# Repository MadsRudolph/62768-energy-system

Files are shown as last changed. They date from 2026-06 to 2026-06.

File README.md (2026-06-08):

# 62768 — Electrical Energy System

Team project for **62768 Electrical Energy Systems** (DTU, June 2026, 3-week course).
We design and build a complete electrical energy system per the course requirement spec
(*Kravspecifikation*), from idea to a working functional model (CDIO).

> 📋 **Start here:** [`docs/project-overview.md`](docs/project-overview.md) — what to build,
> targets, subsystem plan, deadlines, and division of labour (synthesised from the course material).
> 🗂️ **Kickoff:** [`docs/project-plan.md`](docs/project-plan.md) — the 9-section project plan
> (Lecture 1 structure) to fill in on day 1: tasks/owners, budget, Gantt.

## Team

| Name | GitHub | Role / area |
|---|---|---|
| Mads Rudolph | @MadsRudolph | |
| Jonas Beck Jensen | @MotherFrogher | |
| Andreas Skånning | @AndreasSJacobsen | |
| Bjørn Bjarnason | @Ask-ham | |
| Nikolas Jacobsen | @nikolas-jacobsen | |
| Nikolas Primdahl Lund | @s235080 | |

## System overview

```mermaid
flowchart LR
    SOL[Solar panel] --> MPPT["MPPT cap (15 mF)"]
    MPPT --> LIN["Linear reg (5V)"]
    LIN --> STORE(("Energy store<br/>1F · V3=5V"))

    MOT[DC-Motor] --> GEN["AC-generator<br/>(3-phase)"]
    GEN --> TR["3× transformer"]
    TR --> REC["Rectifier + cap (15 mF)"]
    REC --> BUCK["Buck (Vout=4.8V)"]
    BUCK -->|V1=15V| STORE

    STORE --> BOOST[Boost]
    BOOST -->|V2=10V| LOAD["Pulsing load 10V"]

    PID["PID (Arduino)"] --> PWM[PWM driver]
    PWM --> MOT
    STORE -.monitor.-> DAQ["PC monitoring"]
```

**Key targets:** V1 = 15 V ±1 V (≥300 mA to buck) · V2 = 10 V ±1 V (≥150 mA) · V3 = 5 V ±0.5 V.
Converters and current sensing must use **discrete components** (op-amps allowed; no integrated converter ICs).
Full requirement list lives in the course spec (see `docs/`).

## Repository layout

| Folder | Contents |
|---|---|
| `firmware/` | Arduino code — PID control, ADC, timer/PWM, monitoring |
| `simulation/` | Simulink models (`.slx`) + parameter scripts (`.m`) |
| `hardware/schematics/` | Circuit schematics |
| `hardware/bom/` | Bill of materials |
| `report/` | LaTeX project report — compile `report/main.tex` (`latexmk -pdf main.tex`) |
| `docs/` | Spec, lab guides, design notes; `docs/datasheets/` for component PDFs |
| `measurements/` | Lab/test data (csv, xlsx) |

## Getting started

- **Firmware:** Arduino IDE (or PlatformIO). Boards used: Arduino + (optionally) TI LAUNCHXL-F28027.
- **Simulation:** MATLAB/Simulink — open `.slx` models in `simulation/`, run the `Parameters*.m` scripts first to load workspace variables.
- **Report:** LaTeX in `report/`. Compile with `latexmk -pdf main.tex` (or `pdflatex main` twice). Each `sections/*.tex` can also be compiled standalone. Fill in the frontpage group members and the kravsporing table.

## Workflow (6-person team)

- **Branch per feature/task:** `git checkout -b firmware/pid-loop` (or `sim/...`, `hw/...`, `docs/...`).
- **Pull request into `main`** — keep `main` always working. Ask one teammate to review before merge.
- **Commit small and often**, with clear messages. Pull before you push.
- **Avoid committing binaries that change every save** — `.gitignore` already excludes MATLAB/Arduino build artifacts.
- Heavy binary files (videos, big captures): link from a shared drive instead of committing.

## Course

- DTU 62768, June 2026 · groups of up to 6 · assessment = report + functional model.
- Lab: V1.01-04 · Lecturers: Ashraf, Sam, Audrey.

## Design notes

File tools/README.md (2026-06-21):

# tools/

## srm-cam — Roland SRM-20 CAM tool (git submodule)

`tools/srm-cam/` is a **git submodule** pointing at
[`MadsRudolph/gerber2rml`](https://github.com/MadsRudolph/gerber2rml) (private):
a standalone tool that converts our KiCad Gerber/Excellon exports into Roland
SRM-20 **RML** jobs (trace isolation, drilling, board cutout) — the CNC-mill
alternative to the fiber laser.

### First checkout / after pulling this in

```bash
git submodule update --init tools/srm-cam
```

(or clone the team repo with `git clone --recurse-submodules …`). You need read
access to the private `gerber2rml` repo.

### Use it

```bash
cd tools/srm-cam
python -m venv .venv && .venv\Scripts\activate     # Windows
pip install -e ".[dev,gui]"
python -m gerber2rml.cli <gerber-folder> -o out -n <board>   # CLI → 3 .rml + runplan
python -m gerber2rml                                          # GUI (preview + export)
```

Gerbers come from the usual KiCad production export (see
`hardware/kicad/WORKFLOW.md`). Full docs live in the submodule: `tools/srm-cam/README.md`,
`tools/srm-cam/docs/design.md`.

### ⚠️ Not yet hardware-verified

Run `tools/srm-cam/docs/parity-mosfet_test.md` (compare against the mods website on a
real board) before cutting copper. The fiber-laser flow remains the default until then.

### Updating the pin

The submodule is pinned to a specific `gerber2rml` commit. To move the team repo to a
newer version: `cd tools/srm-cam && git pull origin main && cd ../.. && git add tools/srm-cam && git commit`.

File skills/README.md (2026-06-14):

# Team skills

Claude Code/Claude.ai skills for this project. A "skill" is a playbook Claude loads
automatically when it's relevant — install once and Claude knows our workflow.

## kicad-laser-pcb

The full KiCad → xTool fiber-laser PCB pipeline: schematic design-bug review
(gate drive, grounding, output caps, opto isolation), through-hole footprint
assignment, the 104×104 mm jig format, two-stage Freerouting, and DXF/Gerber export.
Encodes every gotcha we hit (Freerouting 1.9-not-2.0.1, the PowerShell BOM bug,
the `pcbnew` zone-removal crash, the pin-letter trap, …).

**Self-contained.** It bundles its own scripts (`scripts/`) and the laser footprint
library (`lib/`), so it works on *anyone's* KiCad 9 project — you do **not** need
access to our team repo to use it. Share the single `.skill` file with the whole class
and it just works (after the one-time toolchain install below).

### Install (each person, once)

**Option A — the packaged file (easiest to share).** Hand someone
`kicad-laser-pcb.skill` and they install it via the skills UI in Claude Code / the
Claude desktop app. Nothing else needed.

**Option B — copy the source folder** into your personal skills directory:

```powershell
# Windows
Copy-Item -Recurse "skills\kicad-laser-pcb" "$env:USERPROFILE\.claude\skills\"
```
```bash
# macOS / Linux
cp -r skills/kicad-laser-pcb ~/.claude/skills/
```

Restart Claude Code (or reload skills) and it'll show up. Ask something like
"route this buck board" or "review this boost schematic" and it triggers — pointed at
*your own* KiCad project.

### First-time toolchain setup

The skill drives the scripts in `hardware/kicad/tools/`, which need KiCad 9, Java 21,
Python 3.13 + sexpdata, and the Freerouting **1.9.0** jar. The one-time install steps
are in the skill's `references/setup.md` (Claude will walk you through them, or read it
directly). The pipeline is Windows + PowerShell; schematic review and footprint work
are fine on any OS, but routing/export need Windows + KiCad 9.

### Updating the skill

Edit the source under `skills/kicad-laser-pcb/`, then anyone can re-copy it. (The
`.skill` package is a convenience snapshot — regenerate it with the skill-creator's
`package_skill.py` if you change the source and want to redistribute the one-file
version.)

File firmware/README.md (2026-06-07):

# Firmware — 62768 Electrical Energy System

**Bare-metal AVR C** firmware (PlatformIO, no Arduino framework). Builds for
**Arduino Uno** (ATmega328P) and **Mega 2560**. The source files are empty
skeletons — to be written by the team.

## Build & upload

```bash
pio run -e uno            # build for Uno
pio run -e mega           # build for Mega 2560
pio run -e uno -t upload  # upload
pio device monitor        # serial monitor @ 115200
```

(Install PlatformIO: VS Code extension, or `pip install platformio`.)

## Files (skeletons — fill in)
| File | Intended role |
|---|---|
| `include/config.h` | Pins, calibration, setpoints, control parameters |
| `pid.h` / `src/pid.c` | PID controller (kept as plain C — can later be swapped for Simulink/Embedded Coder output) |
| `sensors.h` / `src/sensors.c` | ADC reading + scaling to volts/amps |
| `src/main.c` | Init, control loop, PWM, serial monitoring, ISRs |

## What it needs to do (from the spec)
- PID-regulate the motor/generator to hold bus **V1 = 15 V** (Krav 1)
- Use the Arduino's **ADC + timer interrupts + PWM** (Krav 15)
- **PC voltage monitoring**, updated every 1.0 s (Krav 13/14)

> Note: the skeletons are empty, so the project won't link until `main()` and the
> drivers are written.

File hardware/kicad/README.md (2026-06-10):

# KiCad — 62768 Electrical Energy System (KiCad 9)

Alle 7 system-boards, produktionsfiler til XTool-fiberlaseren og hele
genererings-pipelinen. **Status og produktionsplan: se `../../PCB_RESULTS.md`
og `production/README.md`.**

## Mappestruktur

| Mappe | Indhold |
|---|---|
| **`boards/<navn>/`** | Ét KiCad-projekt pr. board — **åbn `.kicad_pro`-filen** (skema + PCB linket). `pcb/`-undermappen har DRC-rapport + top/bund-renders. `README-exp3a.md` / `README-system.md` er design-noterne. |
| **`production/<navn>/`** | **Laserfiler**: `<navn>.dxf` (importeres i xTool), `_silk_top.dxf` (valgfri topside-tekst), `gerbers/` (komplet fab-sæt). Køreplan i `production/README.md`. |
| `bom/` | `footprint_map.csv` — ref → indkøbsdel (shop/kit) → footprint → noter. Bestil efter den. |
| `lib/` | Projekt-bibliotek: `energy_system.pretty/` (bl.a. `*_LaserPads`-footprints), `energy_system.kicad_sym`, scaffold-projektet. Hvert board har sin egen `fp-lib-table` der peger herhen. |
| `tools/` | Pipeline: `pcb_make_all.ps1` (netliste → placering → Freerouting → DRC → render), `pcb_export_production.ps1` (DXF + Gerbers), hjælpescripts. `tools/generators/` genskaber skemaerne. `retrofit_pcb.py` er historisk (engangs-rettelser, gamle stier). |
| `simulation/` | ngspice/behavioral-simuleringerne: `converters/` (buck/boost + modeller) og `exp3a/` (drive/feedback). Egne README'er. |

## Boards

`buck` · `boost` · `drive_circuit` · `feedback_circuit` · `rectifier` · `mppt` · `current_sense`

Designregler (fiberlaser-guiden): bane 1.0 mm, clearance 0.8 mm — ligger i hvert
boards `.kicad_pro`, så GUI-routing automatisk overholder dem. Komponentnavne er
graveret som kobber-tekst på B.Cu.

## Genbyg / eksportér (køres fra denne mappe)

```powershell
.\tools\pcb_make_all.ps1 [-Jar <sti>\freerouting-1.9.0.jar] [-Boards buck,mppt]
.\tools\pcb_export_production.ps1
```

Kræver KiCad 9, `py -3.13` med sexpdata, Java 21 + freerouting-**1.9.0**.jar
(https://github.com/freerouting/freerouting/releases/tag/v1.9.0 — IKKE 2.0.1,
se gotcha-tabellen i WORKFLOW.md: BOM/NPE æder SES-gemningen).
NB: KiCad-stable popper en harmløs debug-assert-dialog under DSN-eksport — klik **No**.

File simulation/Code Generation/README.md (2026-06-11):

# Code Generation example models

The worked Simulink models from the **Code Generation** lecture series (Ashraf/Sam).
They demonstrate the MATLAB → C automatic-code-generation workflow, peripheral by
peripheral, building up to a closed-loop controller.

| Model | Demonstrates | Lecture |
|---|---|---|
| `PulseGenerator.slx` | GPIO digital output (the LED-blink smoke test) | Deck 1–2 (Install) |
| `SliderPWM.slx` | ePWM — set frequency + vary duty live with a slider | Deck 3 (PWM) |
| `ADC.slx` | ADC peripheral — SOC trigger, channel, the sensing chain | Deck 4 (ADC) |
| `MotorControl2026.slx` | **closed-loop PI(z) control** — ref → PI → PWM → plant → ADC → back | Deck 5 (PID) |

`MotorControl2026.slx` is effectively the **template for our own motor/converter control**.

## ⚠️ Target board
These examples target the **TI C2000 F28027 LaunchPad** (the lecture's board). Our project
uses an **Arduino Mega 2560** — to run them on it, change *Configuration Parameters
(Ctrl+E) → Hardware board* and swap the C2000 ePWM/ADC blocks for the Arduino PWM / Analog
Input blocks. See the study notes for the full mapping:

- Slides + write-up: `Obsidian/Courses/62768 Electrical Energy Systems/` →
  `Lecture Notes/Code Generation — C2000 Workflow.md` (the lecture target) and
  `…/Code Generation — ATmega2560 (Arduino Mega) Workflow.md` (our board).

Needs the **C2000 Microcontroller Blockset** (for the originals) or the **Simulink Support
Package for Arduino Hardware** (to retarget) — see the install steps in those notes.

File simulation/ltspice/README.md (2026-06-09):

# LTspice converter models — buck & boost

First-pass open-loop models of the two self-built DC/DC converters (Krav 8/9),
generated with **SpicePilot / PySpice** and verified in **LTspice** batch mode.

| File | What it is |
|---|---|
| `buck_converter.py` / `boost_converter.py` | SpicePilot/PySpice generators — edit values here, re-run to regenerate |
| `buck.net` / `boost.net` | The LTspice-ready SPICE netlists (open these directly in LTspice) |
| `*.raw`, `*.log` | LTspice simulation output (gitignored) |

## How to use

**Just simulate (no Python needed):** open `buck.net` or `boost.net` in LTspice
(`File > Open`), then `Run`. Probe `V(out)`, `V(sw)`, `I(L1)`.

**Regenerate after changing a value:** edit the design block at the top of the
`.py`, then:
```
py -3.13 buck_converter.py        # rewrites buck.net
```
(Needs PySpice: `py -3.13 -m pip install pyspice`. ngspice is NOT required — we
only generate the netlist; LTspice does the simulating.)

**Batch-verify from the command line** (writes measurements into the `.log`):
```
"C:\Users\<you>\AppData\Local\Programs\ADI\LTspice\LTspice.exe" -b -ascii buck.net
```
then read the `.meas` results from `buck.log`.

## Design

Targets from the project diagram (Lec 1) and the Kravspecifikation. Formulas from
the [Lec 2 (Erickson)](../../../../Obsidian) / Lec 5 (Rashid) converter notes.

| | Buck | Boost |
|---|---|---|
| In → Out | 15 V (V1 bus) → 5 V (charges V3 store) | 5 V (V3 store) → 15 V (V2 load) |
| Duty `D` | `Vout/Vin` = 0.333 | `1 − Vin/Vout` = 0.667 |
| `f_sw` | 50 kHz | 50 kHz |
| `L` | 470 µH | 470 µH |
| `C` | 47 µF | 47 µF |
| `R_load` | 10 Ω (~0.5 A) | 100 Ω (150 mA) |

Inductor sized for continuous conduction (~30 % peak-peak ripple); capacitor sized
to keep output ripple inside the ± tolerance.

## Verified results (LTspice, steady state)

| Converter | Sim Vout | Output ripple (pp) | Inductor ripple (pp) | Spec | Pass |
|---|---|---|---|---|---|
| Buck 15→5 V | 4.66 V | 46 mV | 0.16 A | V3 = 5 V ±0.5 V | ✓ |
| Boost 5→15 V | 14.45 V | 109 mV | 0.16 A | V2 ±1.0 V | ✓ |

**Why Vout is a bit low:** open-loop, the switch `Ron` and the diode forward drop
eat ~0.3 V (buck) and ~0.55 V (boost). In the real system the converters are
**closed-loop** (discrete op-amp feedback), which trims the duty up to hit the
target exactly. Good thing to show in the report: ideal `D·Vin` vs measured, and
the loss budget.

> Note: the boost needs a long enough sim to settle — its output time constant is
> `R·C = 100 Ω × 47 µF = 4.7 ms`, so `boost.net` runs 25 ms (~5 τ) before measuring.
> The buck (`R·C = 0.47 ms`) settles inside 5 ms.

## From model to hardware (the discrete build)

These models use ideal SPICE primitives (`SW` switch + a Schottky-ish diode). The
actual board (Krav 9: **discrete components, no converter ICs**) maps them to:

| Model element | Real part |
|---|---|
| `S1` (SW switch) | **IRF530N** power MOSFET (in the kit) |
| gate `PULSE` source | Arduino PWM → **gate driver** (IR2110, high-side for the buck — see Exp 3A) |
| `MYDIODE` | Schottky freewheel/output diode (e.g. 1N5819) |
| — | + current sense (discrete + op-amp, Krav 10) |

## Next steps
- Swap the ideal `SW` for a real IRF530N SPICE model and the diode for a Schottky model.
- Close the loop (op-amp PI feedback) and re-check the step-response specs
  (V1 100→300 mA, V2 50→150 mA in ≤1 s).
- Optionally draw the graphical `.asc` schematics for the report figures.

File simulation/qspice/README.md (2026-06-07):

# QSPICE project — 62768 Electrical Energy System

Circuit-level (SPICE) simulation of the **discrete power electronics** — buck/boost
converters, 3-phase rectifier, gate-drive — to verify designs before building the PCB.
(Complements the Simulink models, which are more system/control level.)

## Open it
Open `energy_system.qsch` in **QSPICE** (free, from Qorvo — installed at
`C:\Program Files\QSPICE`). It's a **blank schematic** to build in.

> The file was created to match QSPICE's `.qsch` format (verified byte-for-byte against
> the installed examples). If for any reason it doesn't open, just make a fresh one in
> QSPICE (**File → New Schematic → Save as `energy_system.qsch`**) — the rest of this
> folder (README, .gitignore) still applies.

## Workflow
1. Draw the converter/rectifier circuit, add a `.tran` directive, simulate.
2. Use it to size L/C, check ripple and switching behaviour, and confirm the discrete
   design before committing it to the KiCad PCB (`../../hardware/kicad/`).

## Notes
- Generated outputs (`*.qraw` waveforms, `*.cir` netlist, etc.) are gitignored — only the
  `.qsch` schematic is tracked.
- Keep component values consistent with `../DC-DC Converters/load_parameters.m` and the
  targets in `../../docs/project-overview.md`.

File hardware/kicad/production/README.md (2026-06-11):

# Produktion på XTool fiberlaseren — klar til kørsel

Følger [SimsesLab/DTU-PCB-prototyping](https://github.com/SimsesLab/DTU-PCB-prototyping)-guiden.
*(Alternativ maskine: Roland SRM-20-fræseren — samme produktionsfiler, se [SRM20_MILL.md](SRM20_MILL.md).)*
Alle 7 boards overholder guidens designregler, **DRC = 0 fejl** og **0 uroutede net**:

- Bane ≥ 1.0 mm, clearance 0.8 mm (netclass — ligger i hvert boards `.kicad_pro`)
- **To-trins-routet:** alt der kan, ligger på **B.Cu** (etch-siden); kun de kryds
  der er umulige enkeltsidet, ligger på **F.Cu** (toppen) — se tabellen nederst
- Solid **no-net fill zone** pr. kobberlag (pad-forbindelse: ingen) — laseren
  fjerner kun isolations-kanalerne, jf. guidens "Correcting your design for the Laser"
- DIP **LongPads** + `energy_system:*_LaserPads` TO-220 (luft 0.84 mm ≥ 0.8)
- DXF eksporteret med guidens indstillinger: kobberlag + Edge.Cuts i én fil,
  drill marks **Small**, mm, ingen konturer

## Filer pr. board

| Fil | Hvad | Spejlvendes i xTool? |
|---|---|---|
| `<board>.dxf` | **BUNDEN** (B.Cu) — hoved-etch | **JA** |
| `<board>_top_cu.dxf` | **TOPPEN** (F.Cu) — trådbro-plan ELLER side 2 ved dobbeltsidet | NEJ |
| `<board>_silk_top.dxf` | valgfri topside-tekst (alle refdes) | NEJ |
| `gerbers/` | komplet Gerber-sæt (begge lag) + Excellon-drill | — |

## Top-laget: to måder at bygge det på

Alle net er routet — toppen indeholder kun det, der ikke kunne ligge enkeltsidet:

| Board | Top-baner | Længde | Vias | Net på toppen |
|---|---|---|---|---|
| buck | **0** | 0 mm | 0 | — (helt enkeltsidet!) |
| boost | 2 | 35 mm | 0 | D1-A |
| drive_circuit | 20 | 135 mm | 0 | GND, D2-A, PWM (manuel placering, to-trins-routet) |
| feedback_circuit | 15 | 73 mm | 0 | GND, SERVO |
| rectifier | 7 | 60 mm | 0 | GND, V1 |
| mppt | 15 | 77 mm | 0 | GND, PV_BUS, U1B_FB |
| current_sense | 8 | 68 mm | 0 | +5V, GND, RET1, U2B_FB |
| buck_v2 | 14 | 86 mm | 0 | (selvstaendig buck m. 555-PWM ombord — `boards/buck/buck_v2/`) |

**Mulighed A — enkeltsidet etch + trådbroer (anbefalet, hurtigst):** ets kun
bunden (`<board>.dxf`). Byg topbanerne som trådbroer mellem THT-benene —
`<board>_top_cu.dxf` ER tegningen (åbn evt. boardet i KiCad og se F.Cu-laget).
Ingen boards har vias længere — alle topbaner går pin-til-pin.

**Mulighed B — dobbeltsidet etch:** ets bunden, vend pladen, justér og ets
toppen med `<board>_top_cu.dxf` (IKKE spejlvendt). Guiden advarer: dobbeltsidet
er på eget ansvar/uprøvet — flip-justering er den svære del. Vias loddes som tråd.

## Komponentnavne på printet

Refdes (R1, U1 …) ligger som **kobber-tekst på F.Cu — OVERSIDEN, komponentsiden**
ved hver komponent (ikke spejlvendt). De er med i `<board>_top_cu.dxf`:
- **Mulighed B (dobbeltsidet):** navnene ætses i top-kobberet — færdig.
- **Mulighed A (enkeltsidet):** gravér `_top_cu.dxf` let på oversiden FØR
  kobberkørslen — så får du navnene OG trådbro-planen tegnet på toppen i én
  arbejdsgang. (Alternativt `_silk_top.dxf`, som kun har navne.)
Enkelte navne er flyttet/droppet i de tætteste klynger (fremgår af
`gerbers/<board>-F_Fab.gbr`).

## Udskæringsmål — positionerings-jiggen

**ALLE 7 boards har samme format:** edge cuts **104×104 mm**, skåret kobberplade
**præcis 109×109 mm** (jiggens åbning). Det giver 2.5 mm rand hele vejen rundt
mellem plade og print — efter gravering skæres/files ned til edge cuts-linjen.

## Tjekliste på laseren (fra guiden — læs hele guiden først!)

1. Sikkerhedskursus gennemført? Ellers STOP.
2. Skær kobberpladen til **præcis 109×109 mm** — jiggens åbning (IKKE de
   blå-film-plader; IKKE dobbeltsidet plade medmindre du kører Mulighed B).
3. 400-grit sandpapir, let — kun oxidlaget af.
4. xTool Creative Space → Import image → vælg `<board>.dxf`.
5. **FLIP designet (spejlvend!)** og gør det **compound**. (Kun bund-DXF'en!)
6. Engrave-mode, Output grøn. **Banerne skal være HVIDE, området omkring SORT**
   (sort = fjernes).
7. Huller: *Edit compound* → slet hver hul-markering så de bliver sorte
   (standard-importen graverer dem ikke).
8. Pladen i positionerings-jiggen (109×109-åbningen). *Framing* → juster så
   rammen IKKE går ud over kanten — der er 2.5 mm rand til edge cuts-linjen.
9. *Auto height adjustment*.
10. Preset **PCB** under Engrave-fanen — tjek parametre mod opslagene/TA'erne.
11. Sidste tjek: spejlvendt? hvide baner? parametre OK? → *Process*.
12. Kig IKKE ind i brændpunktet. Bagefter: bor hullerne (drill marks er graveret
    som små centreringsmærker), skær til endeligt mål, og byg toppen
    (trådbroer jf. Mulighed A — eller anden etch jf. Mulighed B).

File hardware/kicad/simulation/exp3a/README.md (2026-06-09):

# Exp 3A — behavioral simulations

The drive/feedback circuits use ICs (IR2110, MCP601, IL300, ILD74) that ngspice has
**no built-in models** for, so we can't sim the real schematics directly the way we did
the buck/boost (which were all SPICE primitives). Instead these are **behavioral**
models that capture each block's *intent* and run cleanly.

Run with PySpice driving its bundled ngspice DLL (py 3.13):
`py -3.13 run_feedback.py` (or load `feedback_behavioral.cir` in any ngspice).

## `feedback_behavioral.cir` — isolated linear amp ✅

Generic single-supply op-amps (tanh soft-rail, 0–5 V) + a behavioral **IL300**
(LED → two matched photodiodes, K3 = K2/K1 ≈ 1). DC-swept the input 0–15 V.

**Result:** `FB_OUT = INPUT / 6`, **dead linear** (ratio 0.16667 across the whole range,
see `fb_transfer.png` / `fb_sweep.csv`). 15 V in → 2.5 V out — ADC-friendly. The servo
node tracks the input exactly, confirming the IL300 servo loop linearises the opto.
Gain is set by `R1/R2` (÷6) and `R5/R3` (×1) with K3 ≈ 1.

### ⚠️ Polarity finding — the as-drawn schematic latches

The sim only converges to this linear transfer when the **LED is driven anode-side by U3**
(U3 *sources* the LED current, so U3↑ → Iled↑ → SERVO↑ = **negative** feedback).

In `feedback_circuit.kicad_sch` as generated, the LED is wired **anode → +5 V, cathode ←
R4 ← U3** (U3 *sinks* it) while U3's **+in = IN_P**. That combination is **positive
feedback** — the loop latches to a rail instead of regulating. Two equivalent fixes:

- **(a)** drive the LED **anode** from U3 (R4 → IL300 pin 1), cathode → GND; or
- **(b)** swap U3's inputs (+in = SERVO, −in = IN_P).

Check the slide to see which it intends, then apply the matching fix.
**Applied:** fix (a) is now in `feedback_circuit.kicad_sch`.

## `drive_behavioral.cir` — PWM motor drive ✅

The opto + IR2110 have no ngspice model, so they're idealised as a **gate PULSE**
(0→12 V, 10 kHz, 50%). The rest is real: **IRF540N** (VDMOS), **DC motor** (Ra=3 Ω +
La=2 mH + 8 V back-EMF), **1N4007** freewheel. Run: `py -3.13 run_drive.py`.

**Result** (steady state, see `drive_waveforms.png`):

| Quantity | Value | Meaning |
|---|---|---|
| SW node, on | ~0.02 V | MOSFET fully enhanced, motor current to GND |
| SW node, off | ~21 V | **freewheel diode clamps the inductive kick** (not a spike) |
| Motor current | ~0.49 A avg, 0.27 A p-p | winding inductance smooths PWM into near-DC |

The current ramps up while the gate is high (motor sees +20 V) and decays through D2
while the gate is low — classic chopper behaviour. This validates the **power stage +
freewheel**; the opto/IR2110 timing itself is trusted from the datasheets.

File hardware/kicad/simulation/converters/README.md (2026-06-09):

# KiCad converter schematics — buck & boost

KiCad 9 schematics of the two self-built DC/DC converters (Krav 8/9), generated
programmatically and matching the LTspice design models in
[`../../../simulation/ltspice/`](../../../simulation/ltspice).

```
converters/
├── design/   real (PCB-bound) schematics + the generator scripts
│   ├── buck.kicad_sch  boost.kicad_sch        the converters
│   ├── buck_preview.pdf  boost_preview.pdf    rendered figures (report)
│   └── buck_build.py  generate_kicad.py  add_optocoupler.py   generators
├── sim/      simulation copies (one standalone project each)
│   └── buck_sim.kicad_sch  boost_sim.kicad_sch
└── models/   ngspice device models (shared by both)
    └── IRF530N.lib (VDMOS)   1N5819.lib (Schottky)
```

**design/** vs **sim/**: the design sheets are the real circuits (opto + everything,
destined for the PCB). The sim sheets are simplified copies — opto excluded, gate
driven by a PULSE source — because each must be its **own standalone project** so the
KiCad simulator nets only that one converter (it flattens a whole project into one
circuit). Both reference the shared models via the relative path `..\models\*.lib`.

> **Simulating:** open a `sim/*.kicad_sch`, set a transient (`5m`/`1u` for buck,
> `25m`/`1u` for boost), Run, probe `V(VOUT_*)`. The gate is a PULSE source (the opto's
> isolated grounds break ngspice, so it's left out of the sim).

## How these were generated

The `spicepilot-kicad` library was tried first but its auto-layout only understands
IC topologies (current mirrors, op-amps) and collapsed the whole converter into one
overlapping cluster. So these follow the **proven kicad-skip / sexpdata pattern**
(per the DTU Multimeter project): components placed on an explicit 2.54 mm grid,
connectivity by net labels dropped exactly on each pin, with short wire stubs.

- **Switch** = real N-MOSFET symbol (`Q_NMOS`, valued **IRF530N**) — maps to the kit part.
- **Diode** = `D_Schottky`, valued **1N5819** (freewheel on the buck, output on the boost).
- Internal nets (`SW`, `VOUT_*`, `GND`) are local labels; external interface nets
  (`VIN_*`, `GATE`) are **global-label ports** — they connect to the rest of the system
  (rectifier bus, Arduino PWM) on other sheets.

## Open / render / regenerate

```
# open in KiCad 9 (File > Open)        buck.kicad_sch / boost.kicad_sch
# render a PDF figure
"C:\Program Files\KiCad\9.0\bin\kicad-cli.exe" sch export pdf -o buck_preview.pdf buck.kicad_sch
# regenerate after editing the tables in generate_kicad.py  (needs: pip install sexpdata)
py -3.13 generate_kicad.py
```

## Isolated gate drive (optocoupler)

Each converter's MOSFET gate is driven through a **4N25 optocoupler** for galvanic
isolation between the Arduino and the power stage (non-inverting):

```
PWM (Arduino) -> R1 330 -> 4N25 LED -> GND_MCU        (isolated logic side)
4N25 transistor: collector -> +12V supply, emitter -> GATE
R2 10k: gate pulldown -> reference
```

- **Boost** (low-side switch): pulldown -> `GND`, supply `+12V`.
- **Buck** (high-side switch): pulldown -> `SW`, floating supply `+12V_SW`. The gate is
  referenced to the MOSFET **source = SW node** (not GND), since V_gs is measured against
  the source. The opto's isolation is what lets this side float on SW.

> ⚠️ **Drive strength:** a 4N25 phototransistor gives isolation but only ~2 mA of drive.
> The IRF530N's gate charge (~34 nC) charges in ~17 µs at 2 mA — workable at **10 kHz**
> but still marginal at 50 kHz. For fast, clean switching add a **BJT totem-pole buffer**
> (BD139 + PNP) after the opto, and/or keep the switching frequency low.

## ERC

Both report **3 expected notes**, all external-interface `global_label_dangling`:
`PWM`, `GND_MCU`, and the `+12V*` gate-drive rail — they connect to the rest of the
system on other sheets. All **internal** nets (SW, VOUT, GND, GATE) are clean.

## Next steps
- Add the **BJT gate-drive buffer** after each optocoupler (see drive-strength note).
- Assign **footprints** (THT) so the schematic can drive a PCB layout.
- Add current sense (Krav 10); optionally merge into `energy_system.kicad_sch` as sub-sheets.

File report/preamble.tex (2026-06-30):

% ============================================================
%  FÆLLES PRÆAMBEL
%  Deles af main.tex (hele rapporten) og de enkelte sektionsfiler,
%  som via \ifdefined\mainfile også kan kompileres alene.
%  Ret kun pakker/stil her ét sted.
%  NB: \documentclass er IKKE her -- den står i main.tex (og i sektionernes
%  standalone-guard), så Overleaf ikke forveksler preamble.tex med hoveddokumentet.
% ============================================================
\usepackage[utf8]{inputenc}
\usepackage[T1]{fontenc}
\usepackage[danish]{babel}
\usepackage{subcaption}
\usepackage{graphicx}              % Indsættelse af billeder
% ------------------------------------------------------------
%  Rod-uafhængige stier: virker både når der kompileres fra
%  report/-mappen (lokalt) og fra repo-roden (Overleaf).
%  Alle \input/\includegraphics bruger report-relative stier
%  (images/..., sections/...); fallback-listerne nedenfor lader
%  TeX også finde dem under report/.
% ------------------------------------------------------------
\graphicspath{{./}{report/}{../}}
\makeatletter
\providecommand\input@path{}
\g@addto@macro\input@path{{./}{report/}{../}}
\makeatother
\usepackage[absolute,overlay]{textpos}
\usepackage{float}                 % H-placering
\usepackage{amsmath}
\usepackage{amssymb}
\usepackage{siunitx}               % \SI{15}{\volt} m.m. -- praktisk til måleresultater
\usepackage{booktabs}
\usepackage[a4paper, left=2.5cm, right=2.5cm, top=2.5cm, bottom=2.5cm]{geometry}
\usepackage{listings}              % Kildekode-listings
\usepackage{xcolor}
\usepackage{tikz}
\usetikzlibrary{automata, positioning, arrows, calc, shapes.geometric}
\tikzset{
    >=stealth,
    shorten >=2pt, shorten <=2pt,
    node distance=2.8cm,
    block/.style={draw, very thick, rectangle, minimum height=1cm, minimum width=2cm, fill=blue!10},
}
\usepackage[colorlinks=true,
            linkcolor=black,
            citecolor=blue,
            urlcolor=blue]{hyperref}

% ------------------------------------------------------------
%  Listing-stil til C / Arduino-firmware
% ------------------------------------------------------------
\lstdefinestyle{c}{
    language=C,
    extendedchars=true,
    basicstyle=\footnotesize\ttfamily,
    keywordstyle=\color{blue}\bfseries,
    commentstyle=\color{green!60!black}\itshape,
    stringstyle=\color{red},
    numbers=left, numberstyle=\tiny\color{gray}, stepnumber=1, numbersep=8pt,
    showspaces=false, showstringspaces=false, showtabs=false,
    frame=single, rulecolor=\color{black}, tabsize=4, captionpos=b,
    breaklines=true, breakatwhitespace=false,
    literate=%
        {æ}{{\ae}}1 {ø}{{\o}}1 {å}{{\aa}}1
        {Æ}{{\AE}}1 {Ø}{{\O}}1 {Å}{{\AA}}1
        {Δ}{{$\Delta$}}1 {Ω}{{$\Omega$}}1 {≈}{{$\approx$}}1,
}

% ------------------------------------------------------------
%  Listing-stil til MATLAB
% ------------------------------------------------------------
\lstdefinestyle{matlab}{
    language=Matlab,
    basicstyle=\footnotesize\ttfamily,
    keywordstyle=\color{blue}\bfseries,
    commentstyle=\color{green!60!black}\itshape,
    stringstyle=\color{magenta},
    numbers=left, numberstyle=\tiny\color{gray}, numbersep=8pt,
    showstringspaces=false, frame=single, tabsize=4, captionpos=b, breaklines=true,
}

\title{Elektrisk Energisystem}
\author{Gruppe \textbf{XX} -- 62768}
\date{Juni 2026}

% \mainfile defineres i main.tex (IKKE her) -- ellers tror standalone-sektioner
% også at de er i hoveddokumentet og springer deres \end{document} over.
\newcommand{\doubleunderline}[1]{\underline{\underline{#1}}}

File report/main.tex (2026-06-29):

% ============================================================
%  SAMLET RAPPORT -- Elektrisk Energisystem (62768)
%  Fælles præambel: preamble.tex
%  Hver sektionsfil kan også kompileres alene (se \ifdefined\mainfile).
%  Kompiler:  latexmk -pdf main.tex     (eller pdflatex main, 2x)
%  NB: \documentclass står her, så Overleaf vælger main.tex som hoveddokument.
% ============================================================
\documentclass{article}
\input{preamble}
\newcommand{\mainfile}{}   % markerer at sektionerne inkluderes -> spring standalone-guard over

\begin{document}

\input{frontpage}

% ============================================================
%  INDHOLD
% ============================================================
\newpage
\tableofcontents
\newpage

% ============================================================
%  RAPPORT
% ============================================================
\input{sections/introduktion}
\input{sections/systemoverblik}

\clearpage
\section{Sub systems}
\input{sections/generator-transformer}   % AC-generator, 3x transformer, ensretter -> V1
\input{sections/buck}                     % Buck-konverter (Vout = 4.8 V)
\input{sections/boost}                    % Boost-konverter -> pulserende last (V2 = 10 V)
\input{sections/solcelle-mppt}            % Solcelle + MPPT + lineær regulator -> V3
\input{sections/stroemmaaling}            % Strømmåling med diskrete komponenter
\input{sections/styring}                  % Arduino: PID, ADC, timer, PWM, overvågning
\input{sections/DriveCircuit}

\input{sections/Feedback-circuit}

\clearpage
\input{sections/integration}              % Systemintegration + energikilde-prioritering           % Test og resultater (100 W LED-test)
\input{sections/diskussion}
\input{sections/konklusion}

% ============================================================
%  APPENDIKS
% ============================================================
\clearpage
\appendix
\part{Appendix}
\input{sections/kravsporing} 
\input{sections/responsibility}
% Kravsporing: 18 krav -> ansvarlig / status
\clearpage
\input{sections/appendix-kildekode}
% Firmware-kildekode (\lstinputlisting)

\end{document}

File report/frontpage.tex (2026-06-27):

% ============================================================
%  FORSIDE (kun til den samlede rapport, main.tex)
% ============================================================

% Logo i højre hjørne (officielt DTU-logo, vektor-PDF)
\begin{textblock*}{3cm}(17.8cm,1cm)
  
\end{textblock*}

% --- Hjælpekommandoer til medlemskort ---
% Kort med foto:        \photocard{billedsti}{Navn}{Studienr.}
% Pladsholder (intet foto): \placeholdercard{Navn}{Studienr.}
\newcommand{\photocard}[3]{%
  \begin{tabular}{c}
    \fbox{}\\[4pt]
    \textbf{#2}\\ #3
  \end{tabular}}
\newcommand{\placeholdercard}[2]{%
  \begin{tabular}{c}
    \fbox{\parbox[c][3cm][c]{2.6cm}{\centering\Huge ?}}\\[4pt]
    \emph{#1}\\ \emph{#2}
  \end{tabular}}

\vspace*{3cm}
\begin{center}
    {\Huge \textbf{ Electrical energy systems, project}}\\[0.6cm]
    {\large Project report}\\[1.0cm]
    \textbf{Course 62768 -- Electrical Energy Systems (project)}\\[0.3cm]
    Danmarks Tekniske Universitet \\
    June 2026
\end{center}

\vspace{1.5cm}

\begin{center}
\renewcommand{\arraystretch}{1.2}
\begin{tabular}{ccc}
    \photocard{images/frontpage/Mads.png}{Mads Rudolph}{s246132} &
    \photocard{images/frontpage/dtu_jonas.png}{Jonas Beck Jensen}{s240324} &
    \photocard{images/frontpage/dtu_andreas.png}{Andreas Skånning}{s241123} \\[1.0cm]
    \photocard{images/frontpage/bjorn.jpg}{Bjørn Bjarnason}{s233928} &
    \photocard{images/frontpage/nikolas.jpg}{Nikolas Jacobsen}{s245428} &
    \photocard{images/frontpage/nikolas_lund.jpg}{Nikolas Primdahl Lund}{s235080} \\
\end{tabular}
\end{center}

\vfill
\begin{center}
     \textbf{\large Group 06}
\end{center}

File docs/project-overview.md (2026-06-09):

# 62768 Electrical Energy Systems — Project Overview

Synthesis of the course material (7 lecture decks, Exp 3A, Three-Phase Transformer
lab, the Kravspecifikation, and the intro slides). Shared reference for the team.

> 📐 **How the circuits fit together** (motor drive vs buck vs boost vs feedback — they're
> separate stages, don't cross-wire them): see [**system-architecture.md**](system-architecture.md).

## What this project is
A 6-person **CDIO** project: build a **two-source electrical energy system**.
- **Deliverables:** group **report** + **poster** → upload to **DTU Learn by 26 June**.
  Plus **peer review** of the report and a **poster presentation**.
- **Grading:** **Pass / Fail**, on the overall impression of the report.
- **Timeline:** 8 June intro + project box; 9 June Simulink code-gen + converter design
  + MPPT (Sam); work through 3 weeks; 26 June hand-in.
- **Kit (from EIS, MCA-143):** Motraxx SR555 DC-motor, Hacker A20-L22 3-phase PMSM
  generator (14 poles, 924 rev/V), 3× ring-core transformers (1:8, Y/Δ choosable,
  ~20–400 Hz), Phaesun Sun Plus 10 PV panel (10 W), 4×400 W halogen "sun", 1 F
  super-cap, Arduino, NI USB-6008 DAQ.

## The system + authoritative targets (from the spec table)
Two branches feed a shared **1 F** super-capacitor store → boost → pulsing load.

| Node | Requirement | Priority |
|---|---|---|
| **V1** (rectifier bus) | 15 V ±1 V at 100 mA buck draw; generator delivers 300 mA; hold through a 100→300 mA step in ≤1.0 s | 1 |
| **V2** (load) | within ±1.0 V; deliver ≥150 mA; hold through a 50→150 mA step in ≤1.0 s | 1 |
| **V3** (energy store) | 5 V ±0.5 V for currents > 20 mA | 1 |
| Converters | self-built **buck & boost**, **discrete components** (no converter ICs) | 1 |
| Current sensing | discrete components, **op-amps allowed**, no other ICs | 1 |
| Source priority | **PV consumed first**, generator is the supplementary source | 1 |
| System test | drive a **100 W LED light at 0.5 m** from the PV branch | 1 |
| Monitoring + Arduino ADC/timer/PWM | PC monitoring, 1.0 s update | 2 (optional) |

> Priority 1 = must design + implement. Priority 2 = optional.

## Subsystems + which lecture drives each
> ✅ **All mappings below are verified against the slide PDFs** (read 9 June). Lecture
> sequence: **Lec 1** = Project Description/Plan; **Lec 1 Modeling** = motor/gen model +
> PID + MPPT (Per Lynggaard companion); **Lec 2** = buck/boost (Erickson);
> **Lec 3** = PMSM; **Lec 4** = diode rectifiers; **Lec 5** = DC/DC choppers (Rashid).
> (Note: the 2024 `Lec 2.pdf` is an old *DC-Motor* deck, superseded by
> `Lec 2_PowerElectronics.pdf` — ignore the old one.)

| Subsystem | What to do | Theory source |
|---|---|---|
| **Generator stage** | PWM-drive DC motor → 3-phase PMSM generator → 3× transformer (**1:8, Y-Δ** — avoids 3rd-harmonic issues), 20–400 Hz → **6-diode rectifier + 15 mF** → V1 = 15 V | **Lec 1 Modeling** (motor+gen TF), **Lec 3** (PMSM), **Lec 4** (3φ rectifier: `V_dc=1.654·V_m`, FF/RF, L/C/LC filter) |
| **Buck converter** (discrete) | feed V2; with `k=D`: `ΔI=V_s·k(1−k)/(2fL)`, `ΔV_c=V_s·k(1−k)/(16LCf²)` (amplitude, about the mean); worst-case ripple at k=0.5 ≈ `V_s/(4fL)` | **Lec 2** (Erickson) + **Lec 5** (Rashid chopper) |
| **Boost converter** (discrete) | store → pulsing load; `V_a=V_s/(1−k)`, `ΔI=V_s·k/(2fL)`, `ΔV_c=(V_a/R)·k/(2fC)` | **Lec 2** + **Lec 5** |
| **PV + MPPT** | Sun Plus 10 under 4×400 W halogen → **discrete MPPT (Perturb & Observe)** → buck + linear-reg → 1 F store at V3 = 5 V | **Lec 1 Modeling** (P&O flowchart) |
| **Gate drive + current sense** | the **Exp 3A** circuit: ILD74 opto → IR2110 → IRF530N + 1N4007 freewheel; isolated feedback via IL300 + MCP601 op-amps | Exp 3A lab |
| **Arduino control** | motor PID + MPPT + monitoring (see below) | **Lec 1 Modeling** (digital PID in C, Ziegler-Nichols) |

## The Arduino's role (important)
- The Arduino's **PID regulates V1 by driving the motor's PWM** (closed loop on the
  generator output) — **not** the converters. The buck/boost are **discrete/analog**.
- So the Arduino does: **motor PID + MPPT + (optional) PC monitoring**.
- **Lec 1 Modeling** shows a P-only loop leaves **≈3 V steady-state error** (or rings if
  you push the gain) → a **full PID** is required. The plant ≈ 1st-order,
  `H(s)=22.83/((s+7.4)(s+37.17))`, settles ~9.6 V.
- **For the PID C-code:** Lec 1 Modeling gives the digital PID directly as a few lines of
  C (integral = running sum `y=y+x; yi=y*Ki/fs`; derivative = difference
  `y=x-xold; yd=Kd*y*fs`), tuned with Ziegler-Nichols. `dcdc120_cl.slx` is the *converter*
  model — a separate thing, not the Arduino's deployed controller.

## How the repo maps to this
| Repo | Role |
|---|---|
| `firmware/` | Motor PID + ADC + monitoring (bare-metal C skeletons — team writes) |
| `simulation/` | Converter models + `load_parameters.m`; **still need a motor+generator model from Lec 2** for the PID |
| `hardware/kicad/` | The discrete buck/boost/MPPT/current-sense/gate-drive board |
| `report/` + Figma poster | The two graded deliverables (due 26 June) |
| `docs/datasheets/` | Exactly the Exp 3A parts (IR2110, IRF540, MCP601, IL300, ILD74) |

## Suggested division of labour (group of 6)
The intro slides suggest: mechanical (2), electronics (2), code (2). A workable split:
- **Generator/mechanical:** motor mount, generator, transformer wiring, rectifier + filter → V1.
- **Power electronics:** discrete buck + boost + MPPT + current-sense + gate-drive → PCB (KiCad).
- **Firmware + control:** motor PID, MPPT, monitoring + the Simulink modeling/code-gen.
- **Report + poster:** continuous, everyone contributes; owners coordinate.

Track tasks via the GitHub issues/board.

## Confirm with the supervisor
- **V2 nominal value** — diagram shows buck "4.8 V" and load "10 V", but the spec table
  only says "within ±1 V" without the nominal. Pin this down.
- **Energy store**: 1 F super-cap vs the 6 V / 2.8 Ah gel battery (spec leaves it open).
- Requirement 10's priority field is blank in the spec.

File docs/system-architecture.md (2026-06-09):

# System Architecture — how the circuits fit together

**Read this before wiring blocks together.** It clears up which parts are *separate
circuits* and how they actually connect — and one mix-up that's easy to make.

---

## The system at a glance (the signal/power chain)

```
Arduino ──PWM──▶ [Motor drive] ──▶ DC Motor ──▶ AC Generator ──▶ 3φ Transformer ──▶ Rectifier ──▶ V1 (15 V)
   ▲                                                                                                  │
   └──────────────────────── [Feedback / sensing] ◀──────────────────────────────────────────────────┤
                                                                                                      │
                                                                                                      ▼
                                                                  [Buck] ──▶ Store (1F, V3 = 5 V) ──▶ [Boost] ──▶ Load (V2)
PV panel ──▶ [MPPT] ──────────────────────────────────────────────────────▶ Store
```

The blocks in `[brackets]` are the circuits we build. Power flows **left → right**; the
feedback path closes the control loops back to the Arduino.

---

## The separate circuits (each is its own block)

| # | Circuit | Input → Output | Its job |
|---|---|---|---|
| 1 | **Motor drive** | Arduino PWM → DC motor | spin the motor → generator, which sets **V1**. The Arduino's **PID regulates V1 by varying this PWM** (motor speed). |
| 2 | **Feedback / sensing** | V1, V2, V3, currents → Arduino & converter controllers | measure everything (op-amps + dividers) for the control loops and PC monitoring. |
| 3 | **Buck converter** | **V1 (15 V)** → 5 V store | step the rectified bus down to charge the energy store. Has **its own** switch, gate drive, and control. |
| 4 | **Boost converter** | store (5 V) → load (15 V) | step the store up to the pulsing load. Has **its own** switch, gate drive, and control. |
| (5) | **PV + MPPT** | solar panel → store | maximum-power-point tracking into the store (PV is consumed first). |

---

## What connects to what — the rules

- **Motor drive** is at the **very start** of the chain. Its only output is the **motor**.
  Its PWM exists to **regulate V1** (via motor speed) — nothing else.
- **Buck input = V1** (the rectifier output). **Not** the motor drive.
- **Boost input = the store.** **Not** the buck directly (the store sits between them).
- **Each converter has its OWN gate driver and its OWN feedback** that regulates *its own*
  output. They are independent stages.

---

## ⚠️ Common mix-up: the buck is **NOT** part of the motor drive

It's tempting to tap the motor drive's **IR2110** to switch the buck's MOSFET — they use
the same `opto → IR2110 → MOSFET` pattern, so they look alike. **Don't.** Here's why:

- The motor drive's PWM duty is set by the **V1 loop** (whatever motor speed V1 needs).
- The buck's switch needs a PWM that regulates the **buck's 5 V output** — a *different*
  objective.

If the buck is driven from the motor's IR2110, it just chops at *the motor's* duty. It may
*read* ~5 V (because the motor PWM happens to land near the right duty), but the moment the
V1 loop changes that duty, **the buck output drifts with it.** The two stages become
accidentally chained.

**What the buck should have instead** — its own front-end, fed from V1:

```
   senses buck 5 V output
            │
            ▼
   [Buck control] ──▶ [own gate driver: opto + IR2110 + bootstrap] ──▶ IRF530N ──▶ L-C ──▶ 5 V
                                                                          ▲
                                                                     V1 (15 V) in
```

The control is either a **discrete op-amp loop** (Krav 9 prefers discrete) regulating to
5 V, or a separate Arduino PWM channel — but **independent of the motor drive**. The boost
is the same idea (its own drive + feedback).

**One-liner:** *the motor drive and the buck are different stages — the buck takes V1 in
and needs its own gate driver + its own feedback. Don't drive the buck from the motor's
IR2110.*

---

## Gate-drive reminder (applies to each converter switch)

The **buck switch is high-side** (its source = the switching node SW, which swings up to
15 V). To drive a high-side N-MOSFET you **must** use the IR2110's **high-side** channel:

- gate ← **HO (pin 7)**, *not* LO (pin 1)
- **VS (pin 5) → the SW node** (the MOSFET source)
- **bootstrap**: diode VCC→VB + cap VB→VS

Driving a high-side MOSFET from a **ground-referenced** output (LO) makes it run as a
**source follower** — it "works" (the output gets choppy ~12 V instead of 15 V, so you
need more duty), but the MOSFET sits in its linear region and **dissipates a lot of heat**.
If a switch MOSFET is getting hot, this is usually why. (The boost switch is low-side —
LO is correct there.)

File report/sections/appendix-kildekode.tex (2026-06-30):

\ifdefined\mainfile\else\documentclass{article}\input{../preamble}\begin{document}\fi

\section{Source code -- Firmware}
\label{sec:appendix-kildekode}

\noindent
The MPPT firmware for the Arduino Nano (ATmega328P) is listed below. It implements the
Perturb-and-Observe algorithm described in Section~\ref{sec:styring}: the PV voltage and
current are read from the INA219 over the I\textsuperscript{2}C bus, the power is computed
in software, and the PWM duty cycle is adjusted to track the maximum power point. The code
is written in embedded C and is included directly from the firmware sources in the
repository (\texttt{firmware/MPPT-embedded-c/}).

\subsection*{main.c}
\lstinputlisting[style=c]{firmware/MPPT-embedded-c/src/main.c}

\subsection*{ina219.h}
\lstinputlisting[style=c]{firmware/MPPT-embedded-c/src/ina219.h}

\subsection*{ina219.c}
\lstinputlisting[style=c]{firmware/MPPT-embedded-c/src/ina219.c}

\subsection*{twi.h}
\lstinputlisting[style=c]{firmware/MPPT-embedded-c/src/twi.h}

\subsection*{twi.c}
\lstinputlisting[style=c]{firmware/MPPT-embedded-c/src/twi.c}

\ifdefined\mainfile\else\end{document}\fi

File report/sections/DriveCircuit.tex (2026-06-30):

\ifdefined\mainfile\else\documentclass{article}\input{../preamble}\begin{document}\fi

\subsection{Simulation and MPPT Control Behavior}

The simulation does not represent a classical closed loop control system that regulates the output to a fixed reference value. Instead, it implements a Maximum Power Point Tracking (MPPT) algorithm based on the Perturb and Observe method.\\
\\
In this approach, the controller does not aim to track a predefined voltage or current. Instead, it continuously adjusts the PWM duty cycle in order to find the operating point that maximizes the power output of the PV module.\\
\\
This is fundamentally different from traditional PID control, where the objective is to minimize the error between a reference value and the measured output. In the MPPT system, the objective is to maximize the power, meaning that the system performs an optimization.\\
\\
A key component in the simulation is the buck converter. The buck converter makes control of the operating point possible by adjusting the efective load seen by the PV module. By changing the PWM duty cycle, the controller changes the current drawn from the PV module, which shifts the operatingpoint along the I--V curve.\\
\\
In the experimental setup, the PV module was connected directly to a resistive load. In this case, the operating point is fixed by the load, and no active control is possible. The measurements were therefore used to determine the I/V and P/V characteristics and to identify the maximum power point.\\
\\
In contrast, the simulation includes a buck converter, which acts as a controllable interface between the PV module and the load. This allows the MPPTalgorithm to dynamically adjust the operating point and track the maximum power point.\\
\\
For this reason, the simulation results are not expected to match the measured voltage, current, and power values directly. The purpose of the simulation is instead to demonstrate that the control strategy works and that the system is able to converge to a stable operating point where the power is maximum
\begin{figure} [H]
    \centering
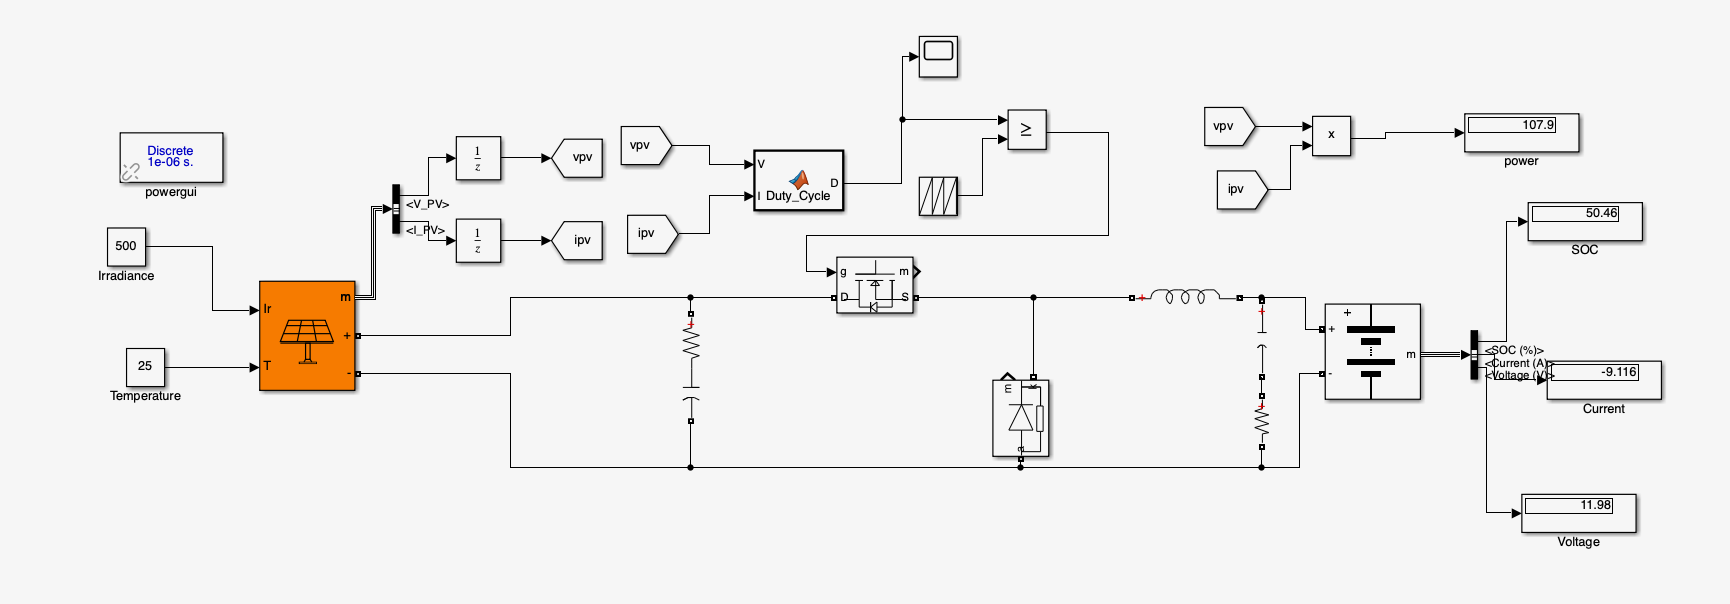
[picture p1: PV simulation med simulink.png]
    
    \caption{Simulation of PV regulation}
    \label{fig:PV_sim}
\end{figure}

\begin{figure} [H]
    \centering
    
    \caption{PWM simulation}
    \label{fig:PWM_sim}
\end{figure}
\noindent The figure shows the PWM duty cycle generated by the MPPT algorithm. 
At the beginning, the duty cycle changes rapidly as the algorithm searches for the maximum power point. 
After a short transient, the duty cycle converges to a stable value of approximately 0.43. 
\\
This behavior indicates that the system has found an operating point where the power is maximized. 
The constant value of the duty cycle demonstrates that the algorithm has reached steady state and no further adjustment is required.

\subsection{Drive Circuit}
\label{sec:DriveCircuit}

\noindent
The driver circuit is used to control the DC motor that drives the three-phase generator in the energy system. The motor speed is controlled by applying a PWM signal to the driver circuit. By changing the PWM duty cycle, the average voltage applied to the motor changes, which makes it possible to regulate the generator speed and therefore the generated voltage.

\vspace{0.4cm}

\noindent
In this project, the driver circuit consists of a CNY17-3 optocoupler, an IR2110 gate driver, and an IRF540N MOSFET. The circuit is designed to allow a low-voltage microcontroller signal to control a higher-power motor circuit. The microcontroller generates the PWM signal, while the MOSFET switches the motor current on and off.

\vspace{0.5cm}

\begin{figure}[H]
\centering
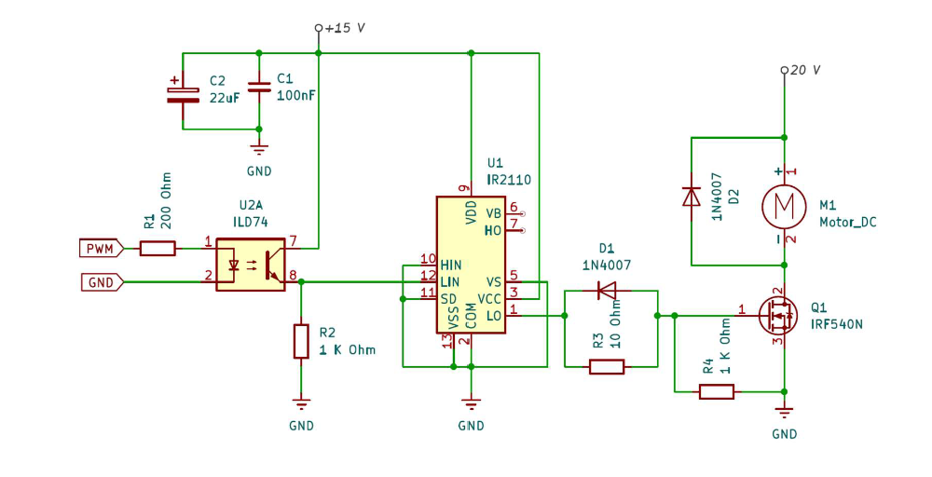
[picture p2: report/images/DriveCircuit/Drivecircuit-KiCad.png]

\caption{KiCad schematic of the motor driver circuit used in the project. - Lecture 2, Exp 3A}
\label{fig:driver_circuit_KiCad}
\end{figure}

\vspace{0.5cm}

\noindent
The PWM signal from the microcontroller is first sent through the CNY17-3 optocoupler. The purpose of the optocoupler is to provide galvanic isolation between the low-voltage control side and the motor power side. This is important because the motor and generator can create electrical noise, voltage spikes, and ground potential differences. The optocoupler helps protect the microcontroller from these disturbances.

\vspace{0.4cm}

\noindent
The input side of the CNY17-3 contains an internal LED. A series resistor is used to limit the current through this LED and prevent damage. When the microcontroller sends a PWM signal, the LED inside the optocoupler turns on and off. On the output side of the optocoupler, this signal is transferred optically and used as the input signal for the IR2110 gate driver.

\vspace{0.4cm}

\noindent
The IR2110 is used as a MOSFET gate driver. A microcontroller output pin cannot normally supply enough current to charge and discharge the MOSFET gate quickly. Therefore, the IR2110 is used to amplify the control signal and provide a stronger gate drive signal to the MOSFET. This allows the MOSFET to switch faster and more reliably.

\vspace{0.4cm}

\noindent
In this circuit, the IR2110 is mainly used to drive the low-side MOSFET. The MOSFET used is an IRF540N N-channel MOSFET. The motor is connected between the positive supply and the drain of the MOSFET, while the source of the MOSFET is connected to ground. When the PWM signal turns the MOSFET on, current flows through the motor and the MOSFET to ground. When the MOSFET turns off, the motor current is interrupted.

\vspace{0.4cm}

\noindent
A flyback diode is placed across the motor. This diode is important because the motor is an inductive load. When the MOSFET turns off, the motor inductance tries to keep the current flowing, which can create a large voltage spike. The flyback diode gives this current a safe path and helps protect the MOSFET from overvoltage.

\vspace{0.4cm}

\noindent
The circuit also includes resistors around the MOSFET gate. These resistors help control the switching behaviour of the MOSFET. A gate resistor limits the peak gate current and reduces ringing during switching. A gate-to-source resistor is also used to make sure the MOSFET stays off when no valid gate signal is present. This prevents unintended switching of the motor.

\vspace{0.4cm}

\noindent
Decoupling capacitors are placed close to the IR2110 supply pins. These capacitors help stabilize the driver supply voltage and reduce the effect of switching noise. This is important because the MOSFET gate driver needs a stable supply voltage to operate reliably.

\subsubsection*{Reasoning for choice of components}

\noindent
The following calculations justify the most important component values used in the motor driver circuit. Since the function of the optocoupler, gate driver, MOSFET, flyback diode, and decoupling capacitors has already been explained above, this section mainly focuses on the selected resistor values and switching considerations.

\vspace{0.4cm}

\noindent
\textbf{Optocoupler LED series resistor}

\noindent
The input LED of the CNY17-3 optocoupler must be driven with a controlled current. To achieve reliable switching while still protecting the microcontroller output and the optocoupler LED, the LED current is chosen as:

\[
I_F = 10~\text{mA}
\]

\noindent
The resistor value can be calculated as:

\[
R = \frac{V_{\text{MCU}} - V_F}{I_F}
\]

\noindent
Using \(V_{\text{MCU}} = 3.3~\text{V}\), \(V_F = 1.3~\text{V}\), and \(I_F = 10~\text{mA}\), the resistor value becomes:

\[
R = \frac{3.3~\text{V} - 1.3~\text{V}}{0.01~\text{A}}
\]

\[
R = 200~\Omega
\]

\noindent
A \(200~\Omega\) resistor is therefore selected. This gives approximately:

\[
I_F = \frac{V_{\text{MCU}} - V_F}{R}
\]

\[
I_F = \frac{3.3~\text{V} - 1.3~\text{V}}{200~\Omega}
\]

\[
I_F = 10~\text{mA}
\]

\noindent
This current is suitable for the CNY17-3 and ensures that the optocoupler can transfer the PWM signal reliably.

\vspace{0.5cm}

\noindent
\textbf{Optocoupler output resistor}

\noindent
On the output side of the CNY17-3, a \(1~\text{k}\Omega\) resistor is used to make sure that the IR2110 input has a defined logic level. This prevents the gate driver input from floating when the optocoupler is not conducting. The CNY17-3 is chosen because its current transfer ratio gives better margin when transferring the PWM signal compared with lower CTR optocoupler versions.

\vspace{0.5cm}

\noindent
\textbf{MOSFET gate resistor}

\noindent
The gate resistor is selected to control how quickly the MOSFET gate is charged and discharged. The IRF540N has a total gate charge of approximately:

\[
Q_g = 71~\text{nC}
\]

\noindent
The required gate current can be estimated as:

\[
I_g = \frac{Q_g}{t_{sw}}
\]

\noindent
Using \(Q_g = 71~\text{nC}\) and an assumed switching time of \(t_{sw} = 200~\text{ns}\), the gate current becomes:

\[
I_g = \frac{71~\text{nC}}{200~\text{ns}}
\]

\[
I_g \approx 0.355~\text{A}
\]

\noindent
The theoretical gate resistance can then be estimated as:

\[
R_g = \frac{V_{GS}}{I_g}
\]

\noindent
Using \(V_{GS} = 15~\text{V}\) and \(I_g = 0.355~\text{A}\), the gate resistance becomes:

\[
R_g = \frac{15~\text{V}}{0.355~\text{A}}
\]

\[
R_g \approx 42~\Omega
\]

\noindent
In the practical circuit, a smaller gate resistor is used to obtain faster switching and reduce switching losses. The resistor still helps limit the peak gate current and reduces ringing in the gate signal.

\vspace{0.5cm}

\noindent
\textbf{Decoupling capacitors}

\noindent
A (100~\text{nF}) capacitor is placed close to the IR2110 supply pins to reduce high-frequency noise. A larger capacitor is also used on the supply rail to support the driver during switching. These capacitors help keep the gate-driver supply stable when the MOSFET switches the motor current.

\vspace{0.5cm}

\noindent
Overall, the chosen component values allow the PWM signal to be transferred safely through the CNY17-3, while the IR2110 and IRF540N can switch the motor current reliably. The selected resistor and capacitor values help protect the circuit, reduce noise, and improve switching stability.

\vspace{0.5cm}

\begin{figure}[H]
\centering
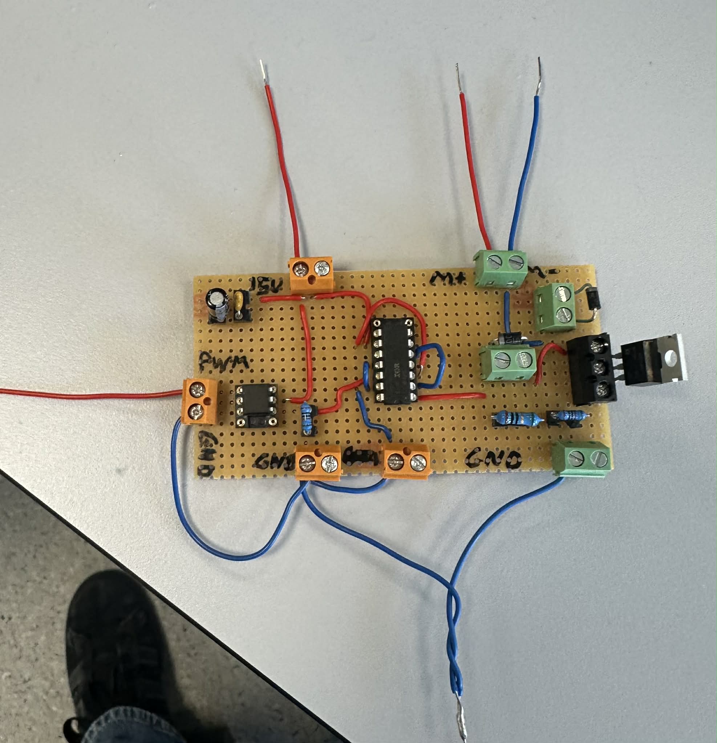
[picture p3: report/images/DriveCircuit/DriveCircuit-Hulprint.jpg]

\caption{Physical implementation of the motor driver circuit on perfboard.}
\label{fig:driver_circuit_physical}
\end{figure}

\vspace{0.5cm}

\noindent
The driver circuit is used as part of the generator control system. By changing the PWM duty cycle, the controller can adjust the speed of the DC motor. A higher duty cycle gives a higher average motor voltage, which increases the motor speed and generator output voltage. A lower duty cycle reduces the motor voltage, which lowers the generator speed and output voltage.

\vspace{0.4cm}
\subsection*{PID Control of the Motor}
A PID controller is used to regulate the output voltage of the motor-generator system. 
The system dynamics are characterized by a dominant pole at approximately 37 rad/s and an additional pole at 7 rad/s. 
A reference voltage \(V_{ref}\) is defined as the desired output level, and the controller adjusts the system such that the measured output voltage follows this reference.
\noindent
The controller compares the measured output voltage with the reference voltage, and the difference between these is defined as the error:

\[
e(t) = V_{ref} - V_{out}
\]
\noindent
This error signal is used as the input to the digital PID controller, which generates a control signal based on proportional, integral, and derivative actions. 
The controller output determines the PWM duty cycle, which is sent through the drive circuit to control the DC motor.
\noindent
The PID parameters (\(K_p\), \(K_i\), and \(K_d\)) are selected based on the system dynamics. 
The dominant time constant \(\tau_1 \approx 0.027\) s provides a guideline for the tuning.
\noindent
An initial estimate of the integral gain can be found as:

\[
K_i \approx \frac{K_p}{\tau_1}
\]
\noindent
The derivative gain can be approximated as:

\[
K_d \approx K_p \cdot \tau_1
\]
\noindent
In practice, however, the theoretical values from these relations are rarely optimal for the real system. 
This is because the physical system includes non ideal effects such as friction, non linearities, delays, which are not fully integrated in the simplified model.
\noindent
The final PID parameters were given in a code generation document selected as:

\[
K_p = 20, \quad K_i = 2, \quad K_d = 0.6
\]
\noindent
The proportional gain \(K_p\) is often chosen through iterative tuning. 
The tuning process starts with a small value of \(K_p\), which should be gradually increased while observing the system response. 
Increasing \(K_p\) improves the response speed of the system, but too high values result in oscillations. 
The selected value \(K_p = 20\) was found to provide a fast response without causing instability.
\noindent
The integral gain \(K_i = 2\) was chosen to eliminate steady-state error. 
A larger value of \(K_i\) can lead to oscillatory behaviour, so a moderate value was selected to ensure stable convergence to the reference.
\noindent
The derivative gain \(K_d = 0.6\) is introduced to provide damping of oscillations. 
Since the system is already relatively fast, only a small derivative term is required. 
The derivative action reduces overshoot and improves stability.
\noindent
Overall, the selected PID parameters represent a compromise between theoretical predictions and practical performance. 
The final values are obtained through iterative tuning based on simulation and experimental testing, where they provided the most stable and efficient way of operation of the system.

\vspace{0.5cm}

\begin{figure}[H]
\centering
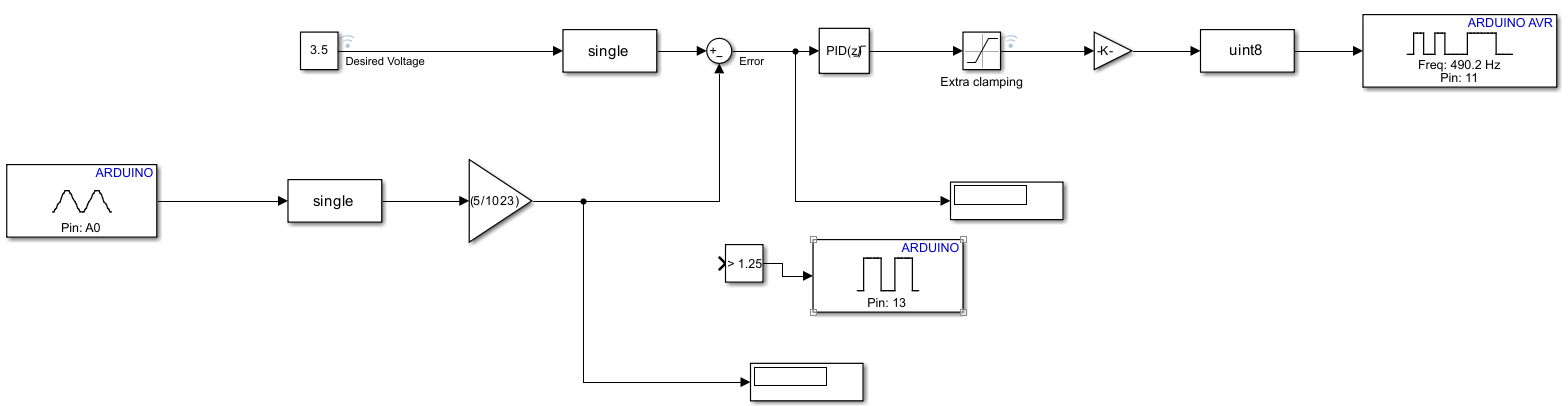
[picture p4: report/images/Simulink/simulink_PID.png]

\caption{Simulink code gen - From MotorControl2026 file.}
\label{fig:simulink_pid_codegen}
\end{figure}

\ifdefined\mainfile\else\end{document}\fi

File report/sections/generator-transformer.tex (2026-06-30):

\ifdefined\mainfile\else\documentclass{article}\input{../preamble}\begin{document}\fi

\subsection{AC-generator, transformer and rectifier}
\label{sec:generator-transformer}
% Beskriv generatoren, 3-fase transformeren og ensretter + kondensator (15\,mF). Krav 1--3 (V1 = 15\,V). Inkl. simulering (Simulink) og målte resultater.

% TODO: design, beregninger, simulering, implementering og måleresultater.

\subsection*{DC-motor / AC-generator}

The system uses a Motraxx SR555SHP-3247S-75 brushed DC motor to drive an A20-22 L EVO kv924 three-phase generator. The DC motor has a rated voltage of \(12~\text{V}\) and a no-load speed of \(5887~\text{rpm}\). When the motor is loaded, the speed decreases to \(5024~\text{rpm}\), which shows that the connected generator and electrical load affect the motor speed. This is expected, since the motor must deliver mechanical torque to rotate the generator while the generator supplies electrical power to the rest of the system.

\noindent The speed drop of the DC motor can be calculated as:

\[
\Delta n = n_{\text{no-load}} - n_{\text{load}}
\]

\[
\Delta n = 5887 - 5024 = 863~\text{rpm}
\]

\noindent This corresponds to a percentage speed decrease of:

\[
\frac{863}{5887} \cdot 100 \approx 14.7\%
\]

\noindent This means that the motor speed decreases by approximately \(14.7\%\) when it is loaded.

\noindent The motor current also increases when the motor is loaded. The no-load current is \(0.25~\text{A}\), while the load current is \(1.46~\text{A}\). The current increase is therefore:

\[
\Delta I = I_{\text{load}} - I_{\text{no-load}}
\]

\[
\Delta I = 1.46 - 0.25 = 1.21~\text{A}
\]

\noindent The approximate electrical input power to the DC motor under load can be calculated as:

\[
P_{\text{in}} = V \cdot I
\]

\[
P_{\text{in}} = 12 \cdot 1.46 = 17.52~\text{W}
\]

\noindent So, under load, the DC motor uses approximately \(17.52~\text{W}\) of electrical input power.

\noindent The behavior of the DC motor can also be explained using the theory for a DC motor. The internal generated voltage, also called back EMF, is given by:

\[
E_A = K\phi\omega_m
\]

\noindent This equation shows that the internal generated voltage depends on the magnetic flux \(\phi\) and the mechanical speed \(\omega_m\). When the motor slows down, \(\omega_m\) decreases, and therefore the internal generated voltage \(E_A\) also decreases. The armature current is given by:

\[
I_A = \frac{V_T - E_A}{R_A}
\]

\noindent This means that when \(E_A\) decreases, the armature current \(I_A\) increases. The induced torque is given by:

\[
\tau_{\text{ind}} = K\phi I_A
\]

\noindent Therefore, when the armature current increases, the induced torque also increases. The motor then reaches a new operating point where the induced torque equals the load torque, but at a lower speed. This explains why the motor slows down when the generator is loaded and why it draws more current when more electrical power is required from the generator.
\vspace{0.5cm}

\noindent The generator is an A20-22 L EVO kv924 brushless outrunner motor. It is lightweight, weighing only \(55~\text{g}\), and has an operating voltage range of \(7.2~\text{V}\) to \(12.6~\text{V}\). According to the datasheet, the generator motor can run at around \(7200~\text{rpm}\) and has a power rating between \(165~\text{W}\) and \(187~\text{W}\), depending on the setup. This means that the generator motor is suitable for producing electrical energy in a small-scale energy system. In practice, the actual output voltage and current will depend on the speed of rotation, the load connected to the system, and losses in the transformer and rectifier.

\noindent Since the generator has a motor constant of \(924~\text{rpm/V}\), the approximate generated voltage at \(7200~\text{rpm}\) can be estimated as:

\[
V \approx \frac{n}{K_V}
\]

\[
V \approx \frac{7200}{924} \approx 7.79~\text{V}
\]

\noindent This is only an approximate value, because the actual generated voltage depends on the rotation speed, the connected load, the transformer connection, and losses in the rectifier.
\vspace{0.5cm}

\noindent In our system, the generated three-phase AC voltage is first connected through a \(Y-\Delta\) transformer and then through a three-phase rectifier. The transformer is used to adapt the three-phase voltage before it reaches the rectifier. The rectifier then converts the three-phase AC voltage into the DC voltage \(V_1\), which is used by the rest of the circuit.

\vspace{1.5cm}

\subsection*{Transformer}

Our transformer setup uses a Wye-to-Delta connection, written as \(Y-\Delta\). This means that the primary side of the transformer is connected in wye, while the secondary side is connected in delta. In our system, the transformer is placed between the three-phase generator and the three-phase rectifier. Its purpose is to adapt the generated AC voltage before it is converted into the DC voltage \(V_1\).
\vspace{0.5cm}
\noindent A three-phase transformer can either be made as one single three-phase transformer or as three separate single-phase transformers connected together. A single three-phase transformer is usually lighter, smaller, cheaper, and slightly more efficient. However, using three separate single-phase transformers can make maintenance easier, because one transformer can be replaced individually if there is a fault.

\noindent For a wye-connected primary side, the line voltage and phase voltage are related by:

\[
V_L = \sqrt{3} \cdot V_\phi
\]

\noindent This means that each transformer winding on the primary side only receives the phase voltage, which is smaller than the line-to-line voltage. On the delta-connected secondary side, the line voltage is equal to the phase voltage:

\[
V_L = V_\phi
\]

\noindent Because of this, the final voltage ratio depends both on the transformer turns ratio and on the \(Y-\Delta\) connection. If the transformer turns ratio is written as:

\[
a = \frac{V_{\phi,\text{primary}}}{V_{\phi,\text{secondary}}}
\]

\noindent then the line voltage relationship for a \(Y-\Delta\) transformer becomes:

\[
\frac{V_{L,\text{primary}}}{V_{L,\text{secondary}}}
=
\sqrt{3} \cdot a
\]

\noindent This means that the voltage on the secondary side is not only determined by the winding ratio, but also by the fact that the primary is connected in wye and the secondary is connected in delta.
\vspace{0.5cm}

\noindent Another important point is that three-phase transformer calculations are often done on a per-phase basis. This means that impedance, voltage regulation, efficiency, and similar calculations can be treated almost like single-phase transformer calculations, but applied to each phase of the three-phase system.
\vspace{0.5cm}

\noindent A useful advantage of the \(Y-\Delta\) transformer connection is that it helps reduce problems caused by third-harmonic components. In a pure wye-wye transformer, third-harmonic voltages can become large, especially if the load is unbalanced. In a \(Y-\Delta\) transformer, the delta winding gives these third-harmonic currents a closed path where they can circulate instead of appearing strongly in the output voltage. This helps make the voltage supplied to the rectifier more stable and reduces unwanted distortion.
\vspace{0.5cm}

\noindent The delta side can also help if the load is slightly unbalanced, because the delta connection can partly redistribute the imbalance between the phases. This makes the \(Y-\Delta\) connection more stable compared to some other transformer connections. Therefore, the \(Y-\Delta\) transformer is useful in our system because it affects the voltage level, improves stability, reduces harmonic problems, and helps provide a better three-phase AC input for the rectifier.
\vspace{0.5cm}
\subsection*{System Dynamics of the Motor-Generator}

The dynamic behavior of the motor-generator system is governed by both mechanical and electrical effects. 
The DC motor and the mechanical load introduce inertia and damping, which influence how the system responds to changes in input.
\\
The mechanical part of the system can be described by the following equation:

\[
T = J_m \frac{d\omega}{dt} + B_m \omega + J_a \frac{d\omega}{dt} + B_a \omega
\]
where \(J_m\) and \(J_a\) represent the inertia of the motor and the load, and \(B_m\) and \(B_a\) represent mechanical damping (friction). 
The angular speed \(\omega\) describes the rotational speed of the motor and generator.
\\
This equation shows that the system does not respond instantaneously to changes in input. 
The inertia resists fast changes in speed, while the damping represents friction that slows down the system. 
As a result, the system has a dynamic response with a certain time delay.
\\
These physical properties lead to a transfer function \(H(s)\) that contains poles. 
From the system model, the motor generator system is characterized by a dominant pole at approximately 37 rad/s and an additional pole at 7 rad/s.
\\
The corresponding time constants are:

\[
\tau_1 = \frac{1}{37} \approx 0.027 \, \text{s}
\]
\[
\tau_2 = \frac{1}{7} \approx 0.143 \, \text{s}
\]
The dominant pole indicates that the system can be approximated as a first-order system, meaning that the response is mainly governed by one dominant time constant.
\\
These dynamics are important, as they determine how quickly the motor-generator system reacts to changes in input and form the basis for the subsequent control design. These time constants are used later in the PID tuning

\vspace{1.5cm}

\subsection*{Rectifier}

\noindent
We use a three-phase diode rectifier consisting of six Schottky diodes. Three diodes are connected to the positive DC output, called the top diodes, and three diodes provide the return path to the negative output, called the bottom diodes. Each phase of the AC generator is connected to the rectifier input.

\vspace{0.4cm}

\begin{figure}[H]
    \centering
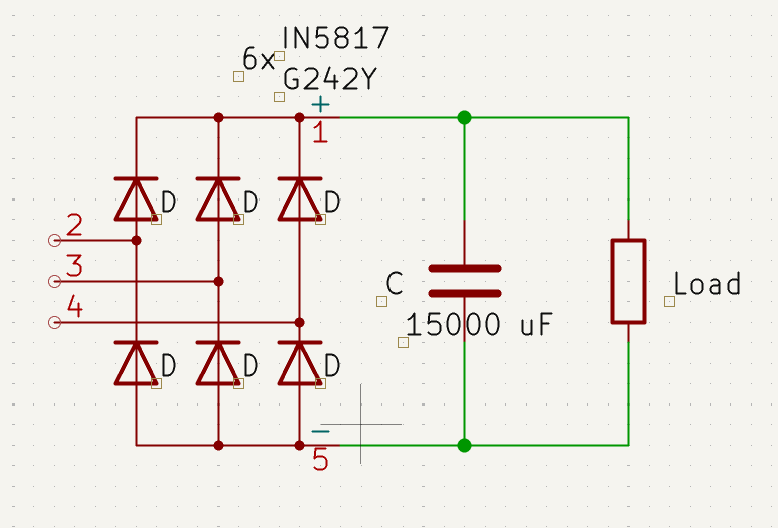
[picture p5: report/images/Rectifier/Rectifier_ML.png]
    
    \caption{KiCad schematic of the three-phase rectifier circuit.}
    \label{fig:rectifier_kicad}
\end{figure}

\vspace{0.4cm}

\noindent
At any instant, the phase with the highest voltage conducts through its corresponding top diode, while the phase with the lowest voltage provides the return path through one of the bottom diodes. In this way, the rectifier converts the three-phase AC input into a pulsating DC output. According to the lecture slides, two diodes conduct at the same time in a three-phase bridge rectifier, and each diode conducts for \(120^\circ\). The conducting diode pair is the pair connected between the two supply lines with the highest instantaneous line-to-line voltage.

\vspace{0.4cm}

\noindent
The line-to-line voltage is important for the rectifier, because the rectifier output depends on the voltage between two phases. For a three-phase system, the line-to-line voltage is related to the phase voltage by:

\[
V_L = \sqrt{3} \cdot V_\phi
\]

\vspace{0.2cm}

\noindent
Schottky diodes are chosen due to their low forward voltage drop, typically \(0.2~\text{V}\) to \(0.4~\text{V}\), which reduces power losses and increases the available DC voltage after rectification. This is useful because two diodes conduct at the same time, so the total diode voltage drop affects the final DC output voltage.

\vspace{0.5cm}

\noindent
After the rectifier, an RC filter is used to smooth the pulsating DC voltage. The capacitor stores charge during voltage peaks and releases it during voltage drops, reducing ripple and producing a more stable DC voltage. The lecture slides also mention that DC filters are usually made as \(L\), \(C\), or \(LC\) filters, and that the filter design depends on the harmonics and ripple content in the output voltage.

\vspace{0.5cm}

\noindent
The DC voltage after the rectifier is designed to operate in the range of approximately \(20\text{--}30~\text{V}\). This variation occurs due to changing load conditions in the system. When the load increases, more current is drawn, causing a voltage drop across internal resistances and components, which lowers the DC voltage. At lower load conditions, the voltage increases due to reduced current draw.

\vspace{0.5cm}

\noindent
This DC voltage is then fed into a buck converter, which steps the voltage down to a stable level of approximately \(15~\text{V}\) for the final load. The buck converter therefore converts a higher, variable input voltage into a lower and regulated output voltage.

\vspace{0.5cm}

\noindent
The load used during testing consists of a \(150~\Omega\) power resistor and a capacitor of \(15000~\mu\text{F}\). The resistor is implemented as a power resistor to safely dissipate the electrical power without overheating. At operating voltages between \(20~\text{V}\) and \(30~\text{V}\), the resistor draws a current between approximately \(133~\text{mA}\) and \(200~\text{mA}\).

\vspace{0.5cm}

\noindent
The maximum power dissipation at \(30~\text{V}\) is:

\[
P = \frac{V^2}{R}
\]

\[
P = \frac{30^2}{150} = 6~\text{W}
\]

\vspace{0.2cm}

\noindent
However, since the voltage is not constant and varies with load conditions, the average power dissipation is lower. A \(5~\text{W}\) power resistor can be acceptable for short or lower-voltage tests, but if the resistor is operated continuously near \(30~\text{V}\), a higher power rating such as \(10~\text{W}\) would be safer.

\vspace{0.5cm}

\noindent
The power resistor is used as a controllable test load to simulate the expected input conditions of the buck converter. Since the buck converter reduces the voltage from approximately \(20\text{--}30~\text{V}\) to \(15~\text{V}\), the input current is lower than the output current. The resistor is therefore selected to approximate the expected input current drawn by the buck converter during operation.

\vspace{0.5cm}

\noindent
Overall, the rectifier performance depends on values such as output voltage, output current, ripple content, diode current rating, peak current, and peak inverse voltage. These are important because the diodes must be able to handle the current and voltage stresses in the circuit.

\vspace{1.5cm}

\subsubsection*{Measured Input Voltage, Rectifier Output Voltage, and Input Current}

\vspace{0.2cm}

\noindent
To verify the behaviour of the rectifier, measurements were performed where the input voltage to the motor was gradually increased. For each input voltage, the DC output voltage after the rectifier and the input current were measured. The measured values are shown in Table~\ref{tab:rectifier_measurements}.

\vspace{0.3cm}

\begin{table}[H]
\centering
\caption{Measured input voltage, output voltage after the rectifier, and input current.}
\begin{tabular}{|c|c|c|}
\hline
\textbf{Input voltage (V)} & \textbf{Output voltage (V)} & \textbf{Input current (A)} \\ \hline
1.5 & 1.84 & 0.400 \\ \hline
2.0 & 2.89 & 0.430 \\ \hline
2.5 & 4.10 & 0.450 \\ \hline
3.0 & 5.06 & 0.525 \\ \hline
3.5 & 6.27 & 0.550 \\ \hline
4.0 & 7.30 & 0.618 \\ \hline
4.5 & 8.52 & 0.630 \\ \hline
5.0 & 9.70 & 0.679 \\ \hline
5.5 & 10.83 & 0.710 \\ \hline
6.0 & 11.92 & 0.757 \\ \hline
6.5 & 13.02 & 0.787 \\ \hline
7.0 & 14.22 & 0.831 \\ \hline
7.5 & 15.23 & 0.870 \\ \hline
8.0 & 16.47 & 0.903 \\ \hline
8.5 & 17.46 & 0.920 \\ \hline
9.0 & 18.70 & 0.970 \\ \hline
9.5 & 19.60 & 0.999 \\ \hline
10.0 & 20.80 & 1.045 \\ \hline
10.5 & 21.80 & 1.072 \\ \hline
11.0 & 22.90 & 1.123 \\ \hline
11.5 & 24.10 & 1.149 \\ \hline
12.0 & 25.10 & 1.185 \\ \hline
12.5 & 26.40 & 1.220 \\ \hline
\end{tabular}
\label{tab:rectifier_measurements}
\end{table}

\vspace{0.5cm}

\begin{figure}[H]
    \centering

    \begin{subfigure}{0.46\textwidth}
        \centering
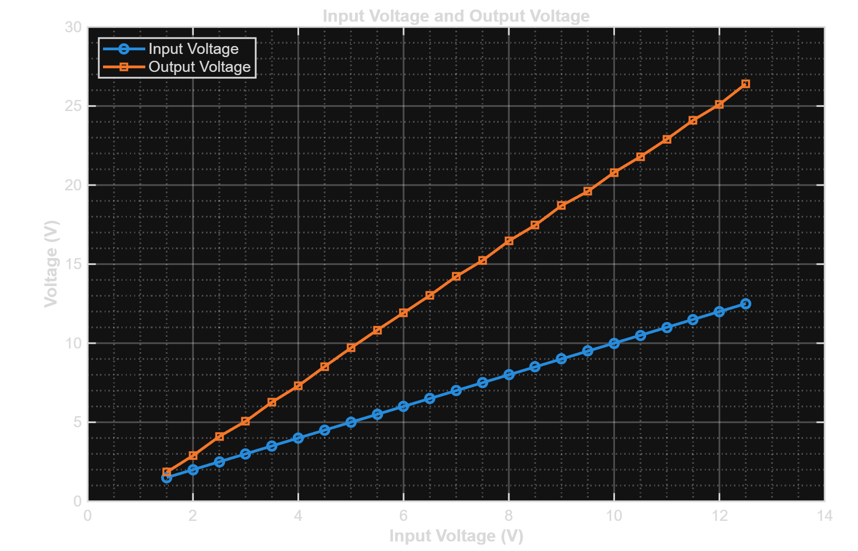
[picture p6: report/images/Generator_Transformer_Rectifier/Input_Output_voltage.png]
        
        \caption{Input voltage and output voltage}
        \label{fig:input_output_voltage}
    \end{subfigure}
    \hfill
    \begin{subfigure}{0.46\textwidth}
        \centering
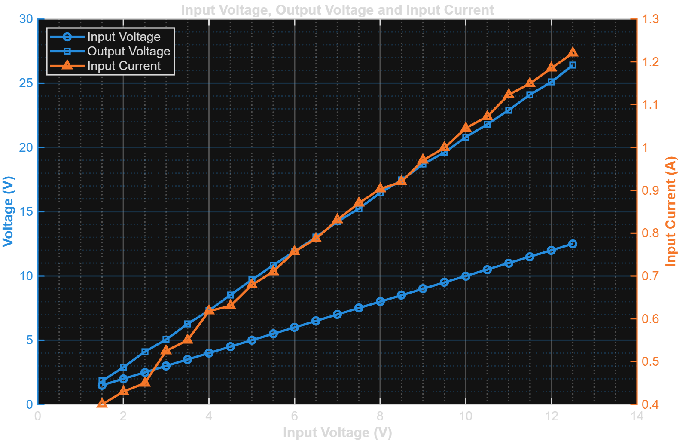
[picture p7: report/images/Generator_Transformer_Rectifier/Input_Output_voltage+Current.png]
        
        \caption{Input voltage, output voltage and input current}
        \label{fig:input_output_voltage_current}
    \end{subfigure}

    \caption{Measured rectifier output voltage and input current as the motor input voltage is increased.}
    \label{fig:rectifier_measurements}
\end{figure}

\vspace{0.5cm}

\noindent
From the measurements in Table~\ref{tab:rectifier_measurements}, it can be seen that the output voltage after the rectifier increases as the input voltage to the motor is increased. At an input voltage of \(1.5~\text{V}\), the rectifier output voltage is \(1.84~\text{V}\). When the input voltage is increased to \(12.5~\text{V}\), the rectifier output voltage increases to \(26.40~\text{V}\). This shows that a higher motor input voltage causes the motor to rotate faster, which drives the generator at a higher speed. As a result, the generated three-phase AC voltage increases, and the rectified DC voltage also increases.

\vspace{0.5cm}

\noindent
Figure~\ref{fig:input_output_voltage} shows the relationship between the input voltage and the output voltage after the rectifier. The graph shows that the output voltage is higher than the input voltage over the full measurement range. This is expected because the input voltage is applied to the DC motor, while the output voltage is measured after the generator, transformer, and rectifier. Therefore, the graph does not show a direct voltage gain from one electrical point to another, but instead shows how the full motor-generator and rectifier system reacts when the motor input voltage is increased.

\vspace{0.5cm}

\noindent
Figure~\ref{fig:input_output_voltage_current} also includes the input current. The input current generally increases as the input voltage is increased. At \(1.5~\text{V}\), the input current is \(0.400~\text{A}\), while at \(12.5~\text{V}\), it reaches \(1.220~\text{A}\). This shows that the motor draws more current as it has to deliver more mechanical power to the generator. The increasing current also indicates that the load on the motor becomes larger when the generator output voltage and output power increase.

\vspace{0.5cm}

\noindent
The measured output voltage reaches the desired rectifier output range of approximately \(20\text{--}30~\text{V}\) when the motor input voltage is around \(10~\text{V}\) or higher. For example, at \(10~\text{V}\) input, the rectifier output voltage is \(20.80~\text{V}\), and at \(12.5~\text{V}\) input, the output voltage is \(26.40~\text{V}\). This means that the system is able to produce a suitable DC voltage for the buck converter when the motor is supplied with a sufficiently high input voltage.

\vspace{0.5cm}

\noindent
Overall, the measurements confirm that the rectifier output voltage depends strongly on the speed of the generator, which is controlled by the motor input voltage. The graphs show a clear relationship between motor input voltage, rectifier output voltage, and input current. This supports the expected behaviour of the system, where a higher motor voltage gives a higher generator speed, a higher rectified DC voltage, and a higher current drawn by the motor.

\subsection{Rectifier Simulation and Output Ripple}
\begin{figure}[H]
    \centering
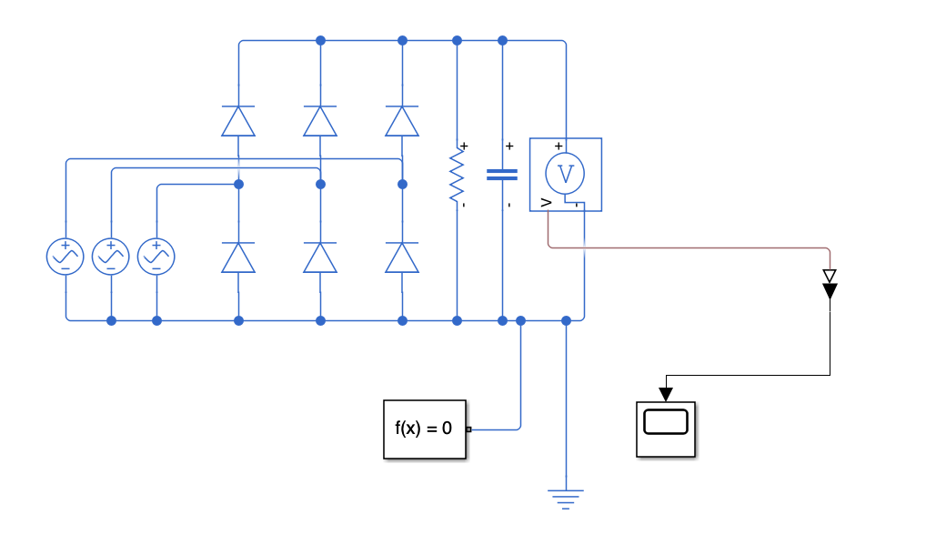
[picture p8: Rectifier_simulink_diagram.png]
    
    \caption{Rectitifer Simulink system}
    \label{fig:Rectifier_simulink_diagram}
\end{figure}
In the Simulink model, a reference node (ground) is introduced for each voltage source. 
This is necessary because each voltage source in the simulation requires a return path in order to define a complete electrical circuit.
\vspace{0.5cm}

\noindent In a real three-phase system, the generator is typically connected in a way where the phase voltages are defined relative to each other, and a separate return path is not explicitly required in the same way. 
However, in the simulation environment, each source must be referenced to a common node to ensure correct behavior of this model 
As a result, a neutral reference is added in the model, even though this does not fully represent the physical implementation. 
This simplification allows the three-phase rectifier to be modeled correctly using individual voltage sources connected to the diode bridge.
\\
Therefore, the simulation model includes a return path for each phase, which is a modeling requirement rather than a physical necessity in the real system. The KiCad model earlier (Fig.2 on page 6) shows the system more effectively in reality.

\vspace{0.5cm}
\begin{figure} [H]
    \centering
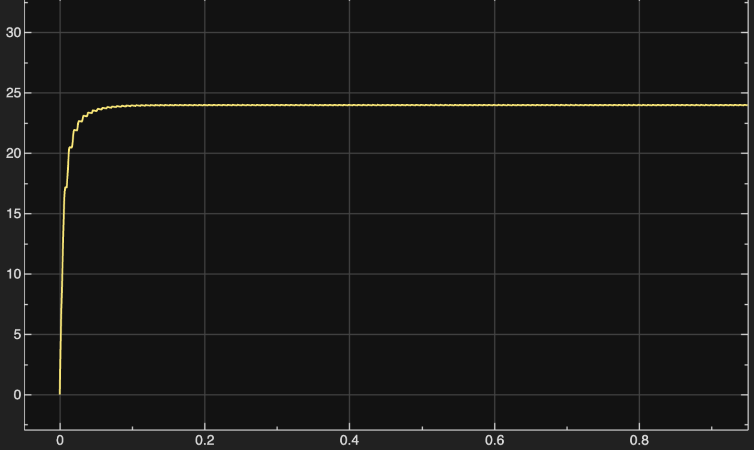
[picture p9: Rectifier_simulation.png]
    
    \caption{Rectifier simulation}
    \label{fig:Rectifier_sim}
\end{figure}
\noindent The figure shows the simulated output voltage of the rectifier during startup. 
Initially the voltage increases rapidly as the output capacitor charges. 
After a short transient period, the voltage stabilizes around 24 V, with a voltage of 25 volt pr phase after the transformer, a 15000 uF capacitor to smooth the signal, and a power resistor with 150 ohms and 5 W is used, simulating the load and the rest of the power system. 
This behavior is expected, since the capacitor stores energy and smooths the rectified voltage.

\begin{figure}[H]
    \centering
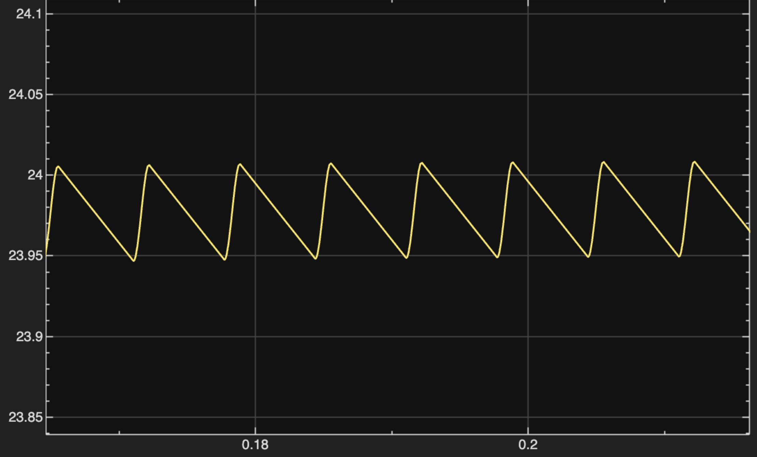
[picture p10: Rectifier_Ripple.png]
    
    \caption{Rectifer Ripple}
    \label{fig:Rectifier_sim_ripple}
\end{figure}
\noindent The second figure shows a zoomed view of the steady state output voltage, where a small ripple is visible ($\Delta$V). 
The ripple is caused by the rectification of the AC input and the charging and discharging of the filter capacitor.
The capacitor reduces the ripple by storing energy during voltage peaks and supplying energy during voltage drops. 
However, since the capacitor is not infinite a small periodic variation in the voltage remains.
The ripple amplitude is relatively small compared to the DC level, which indicates that the filtering is effective. 
This results in a stable DC voltage which can be used for the following stages in the system.

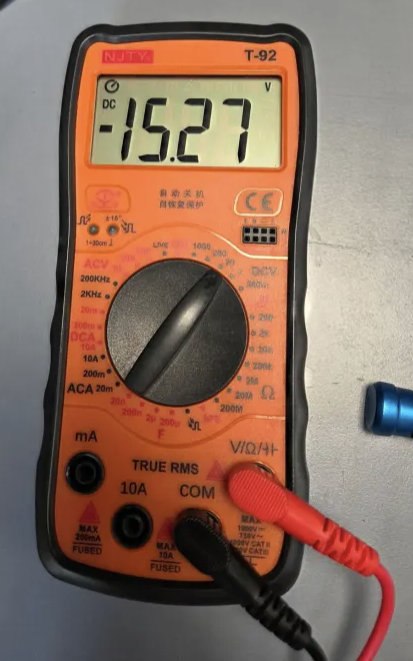
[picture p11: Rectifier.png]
\begin{figure}[H] \centering  \caption{The rectifier output voltage with a load of $33\,\Omega$ shows that the system satisfies the requirement of delivering at least $300\,\mathrm{mA}$ to the buck converter, i.e., $\frac{15\,\mathrm{V}}{33\,\Omega} \approx 455\,\mathrm{mA}$.} \label{fig:rectifier-output} \end{figure}

\ifdefined\mainfile\else\end{document}\fi

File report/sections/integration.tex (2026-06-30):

\ifdefined\mainfile\else\documentclass{article}\input{../preamble}\begin{document}\fi

\section{Systemintegration}
\label{sec:integration}
% Sammenkobling af alle delsystemer til den fulde kæde.
% Energikilde-prioritering: solcelle først, AC-generator supplerer (krav 11).

% TODO: beskriv integrationen og verifikation af den samlede kæde.
\subsection{Generator-Only Operation} 
The overall system consists of a photovoltaic (PV) part and a generator part. 
In this section, only the generator part of the system is considered, meaning the system operating without the PV module.

\vspace{0.5cm} \noindent
In generator-only operation, a DC motor provides mechanical energy to a three-phase AC generator. 
The generator produces three-phase voltages with a phase shift of 120 degrees between each phase. 
The voltage amplitude from the generator is relatively low and is therefore increased using a transformer.

\vspace{0.5cm} \noindent
The transformer is connected in a wye-delta configuration, which scales the voltage according to the transformer turns ratio and a factor of $\sqrt{3}$ due to the three-phase connection. 
The resulting three-phase voltage is then converted to DC using a three-phase rectifier. 
After rectification, a capacitor of 15000~$\mu$F is used to reduce ripple and produce a smoother DC voltage.

\vspace{0.5cm} \noindent
This DC voltage supplies the load, while the same voltage is measured in parallel by the feedback circuit. 
The feedback circuit measures the rectified voltage (approximately 15~V) and provides a scaled version of the signal to the microcontroller. 
An optically isolated feedback circuit is used to protect the microcontroller from higher voltages and electrical noise.

\vspace{0.5cm} \noindent
The output from the feedback circuit is connected to the ADC input of the microcontroller. 
The microcontroller processes this signal and generates a PWM output, which is sent to the drive circuit. 
The drive circuit uses this PWM signal to control the MOSFET that supplies power to the DC motor.

\vspace{0.5cm} \noindent
A separate supply voltage is used in the drive circuit to power the motor. 
Depending on the duty cycle of the PWM signal from the TI MCU which acts as a PID controller, the MOSFET switches on and off, thereby controlling the average voltage applied to the motor. 
As a result, the motor speed is adjusted by the PID controller by changing the duty cycle, ensuring a stable rectified output voltage.

\vspace{0.5cm} \noindent
In this operating mode, the buck converter is not actively used for regulation, as the system operates without the PV module. 
The buck converter is primarily used in combination with the PV system, where it enables control of the operating point through adjustment of the PWM duty cycle..

\begin{figure}[H]
\centering
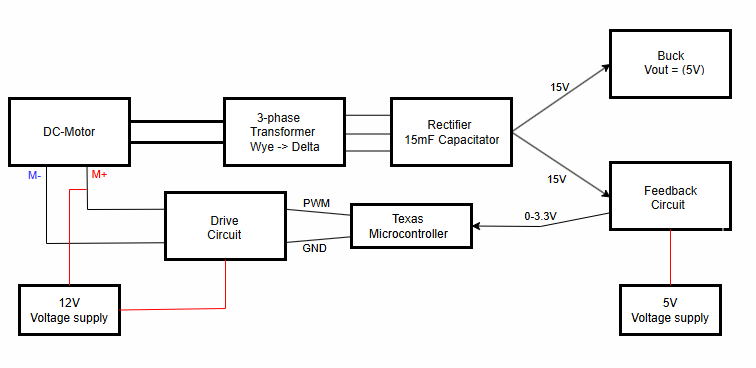
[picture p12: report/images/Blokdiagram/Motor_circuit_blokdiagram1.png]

\caption{Motor/Generator Subsystem }
\label{fig:blokdiagram_Motor_circuit}
\end{figure}

\vspace{0.5cm}

\subsection{Complete system measurements}
\noindent
After the full system was connected, measurements were made with the solar panel turned off and turned on. This was done to see how much the solar panel affected the rest of the system.

\vspace{0.5cm} \noindent
By looking at the pictures, the measured voltage and current values can be read directly from the power supplies. These values are collected in the table below, so it is easier to compare the circuit operation with and without the solar panel active.

\vspace{0.5cm} \noindent
Afterwards, the output values of the buck converter, boost converter, and rectifier were measured directly on the physical circuit. These measurements were used to verify that each part of the system produced the expected voltage level during complete system operation.

\begin{figure}[H]
    \centering
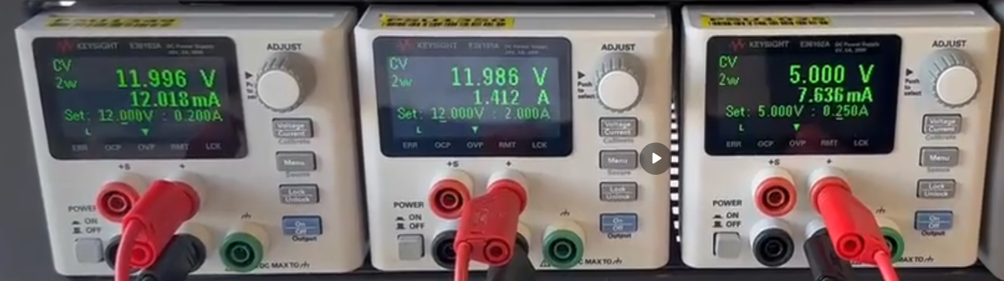
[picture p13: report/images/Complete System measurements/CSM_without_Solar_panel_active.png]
    
    \caption{Complete system measurement without the solar panel active.}
    \label{fig:csm_without_solar}
\end{figure}

\begin{figure}[H]
    \centering
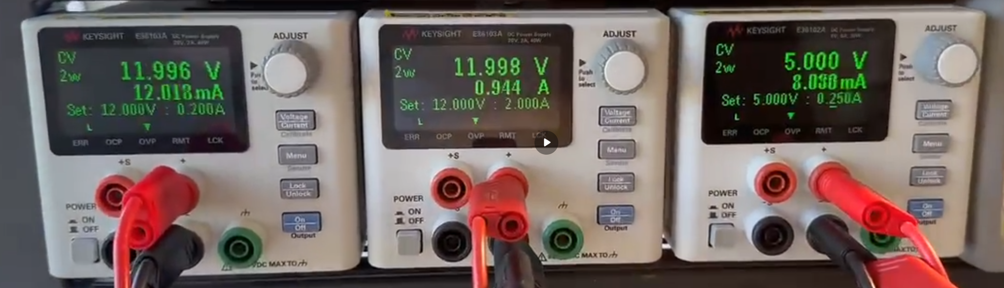
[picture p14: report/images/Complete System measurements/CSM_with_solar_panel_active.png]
    
    \caption{Complete system measurement with the solar panel active.}
    \label{fig:csm_with_solar}
\end{figure}

\begin{table}[H]
\centering
\caption{Measured values for the complete system with and without the solar panel active.}
\small
\setlength{\tabcolsep}{3pt}
\begin{tabular}{|l|c|c|c|c|c|}
\hline
\textbf{Operating condition} & \textbf{Boost} & \textbf{Buck} & \textbf{Rectifier} & \textbf{Motor V} & \textbf{Motor I} \\
\hline
Without solar panel active & 11.06 V & 4.8 V & 11.5 V & 12 V & 1.412 A \\
\hline
With solar panel active & 11.5 V & 5.1 V & 15.5 V & 12 V & 0.944 A \\
\hline
\end{tabular}
\label{tab:complete_system_measurements}
\end{table}

\noindent
From the measurements, it can be seen that the system works in both cases. There are some differences in the measured voltages, but the values are still close to the expected voltage levels. The boost converter output is around 11 V, and the buck converter output is around 5 V, which shows that both converters are working.

\vspace{0.5cm} \noindent
The most important result is the motor current. When the solar panel is not active, the motor uses 1.412 A. When the solar panel is active, the motor current decreases to 0.944 A. The difference is:

\[
\Delta I = 1.412 - 0.944 = 0.468~\text{A}
\]
\noindent
This means that the motor current is reduced by:

\[
\frac{0.468}{1.412} \cdot 100 \approx 33.1\%
\]
\noindent
So the motor current is reduced by approximately 33\%. This shows that the solar panel helps supply power to the system. Because of this, the motor-generator part does not need to deliver as much power, and the load on the motor becomes smaller.

\vspace{0.5cm} \noindent
The variations in voltage are expected because the system is made of many different parts, such as the motor, generator, rectifier, capacitors, buck converter, boost converter, and solar panel. Each part has losses, and the voltage can change slightly depending on the load. For example, when the solar panel is active, it adds energy to the system, which changes the operating point. This is why the rectifier output increases from 11.5 V to 15.5 V.

\vspace{0.5cm} \noindent
The converters also do not give a perfectly constant voltage. The output depends on the input voltage, duty cycle, component losses, switching ripple, and the load current. Therefore, a small difference between 4.8 V and 5.1 V at the buck output is normal.

\vspace{0.5cm} \noindent
The capacitors also affect the voltage. They help smooth the voltage, but they cannot remove all changes completely. Small variations can also come from measurement uncertainty, wires, contact resistance, and ripple in the circuit.

\vspace{0.5cm} \noindent
Overall, the measurements show that the complete system works. The voltage values only change slightly, and the system stays operational. The reduction in motor current clearly shows that the solar panel contributes power and reduces the load on the motor-generator system.

\begin{figure}[H]
    \centering
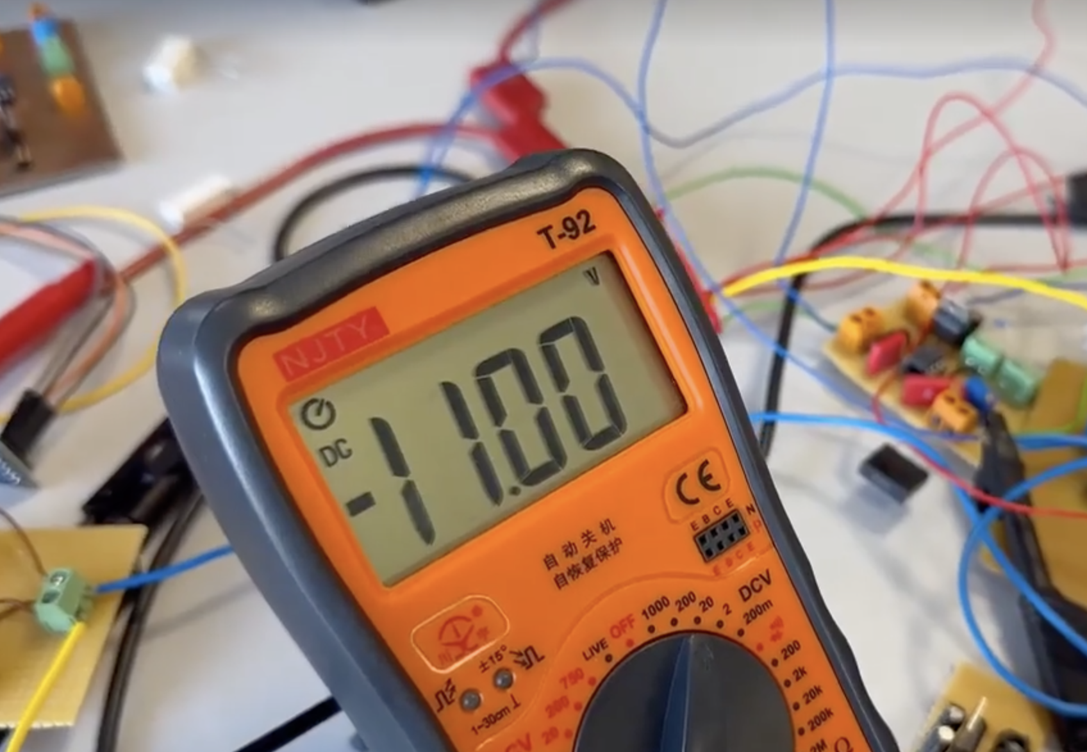
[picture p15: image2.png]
    
    \caption{Rectifier voltage (V1) without PV is too low when the full system is assembled}
    \label{fig:v1_without_pv}
\end{figure}

\begin{figure}[H]
    \centering
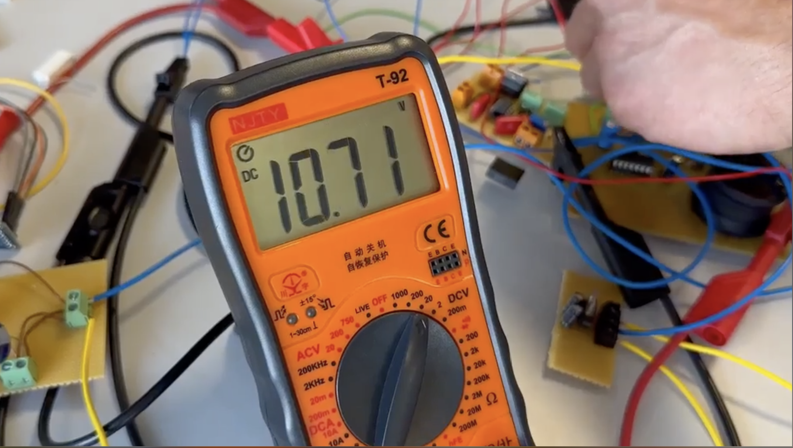
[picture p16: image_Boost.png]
    
    \caption{Voltage on Boost converter without PV. Our measured voltage on the Boost converter (V2) at 68 ohms, which satisfied the requirement of +/- 1 Volts}
    \label{V_Boost_without_PV}
\end{figure}

\begin{figure}[H]
    \centering
    
    \caption{Buck converter output voltage (V3) without PV satisfied the requirement of +/- 0.5 Volts}
    \label{fig:v3_without_pv}
\end{figure}

\begin{figure}[H]
    \centering
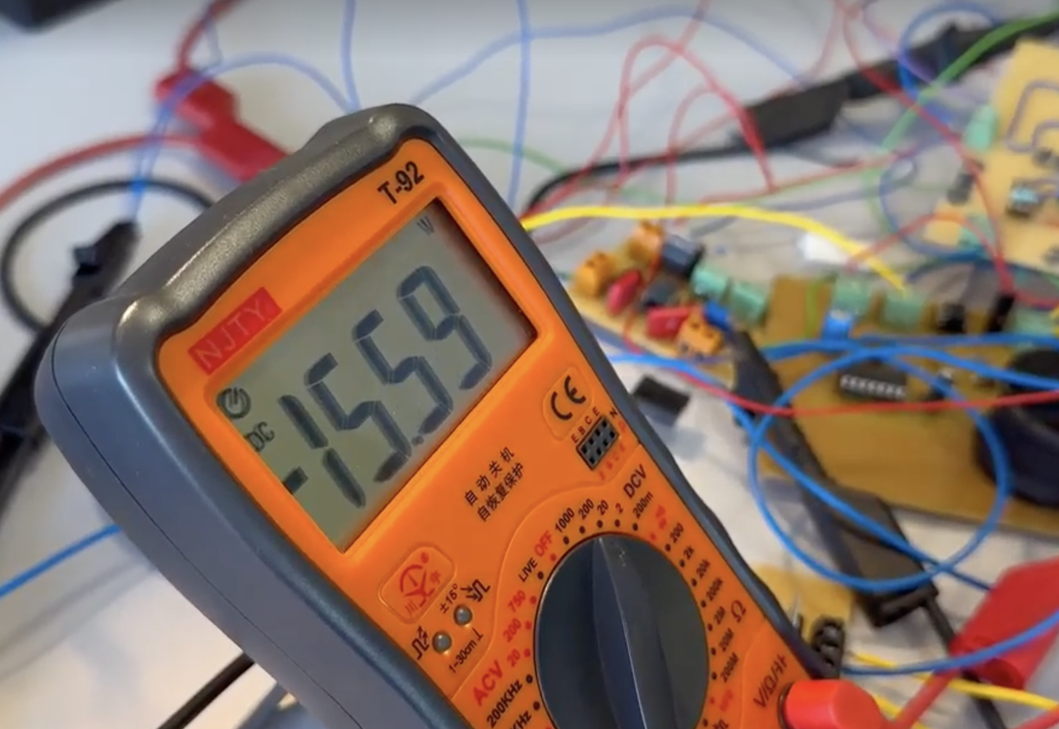
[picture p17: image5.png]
    
    \caption{Rectifier voltage (V1) with PV satisfies requirement for voltage }
    \label{fig:v1_with_pv}
\end{figure}

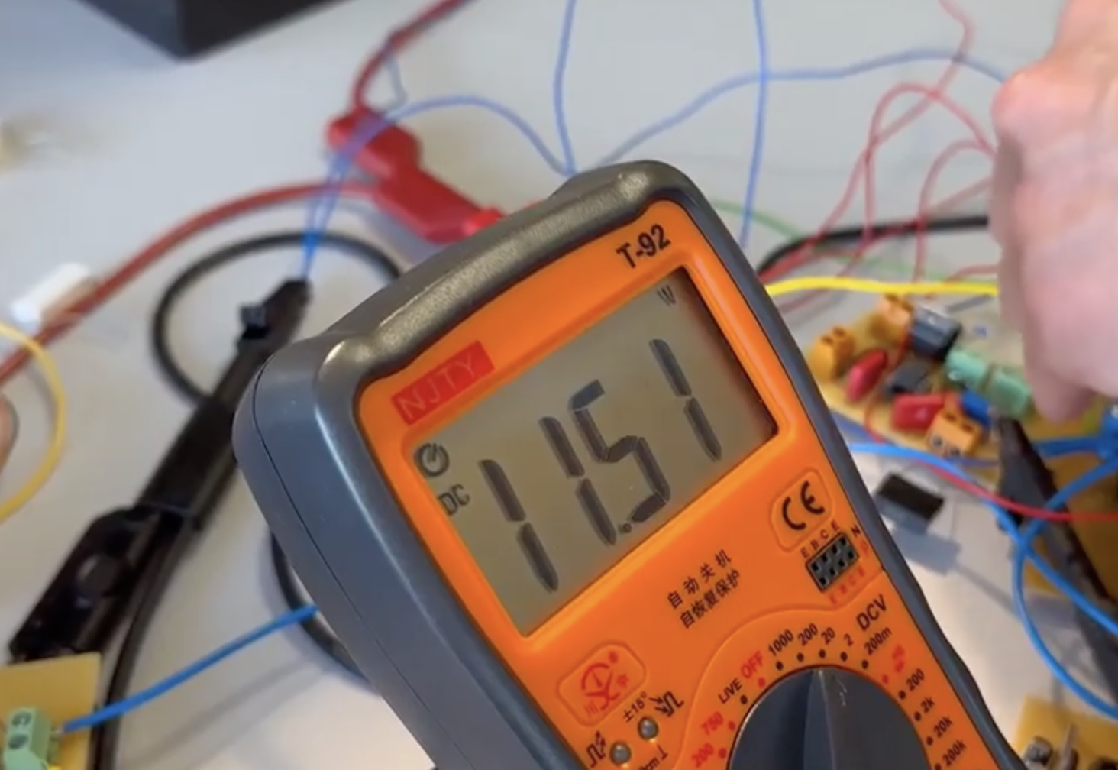
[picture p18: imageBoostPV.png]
\begin{figure}[H] \centering  \caption{The boost-converter output voltage ($V_2$) with a $68\,\Omega$ load. At an output voltage of $11.51\,\mathrm{V}$, the load current is approximately $\frac{11.51\,\mathrm{V}}{68\,\Omega} \approx 221\,\mathrm{mA}$.} \label{fig:v2_with_pv} \end{figure}

\begin{figure}[H]
    \centering
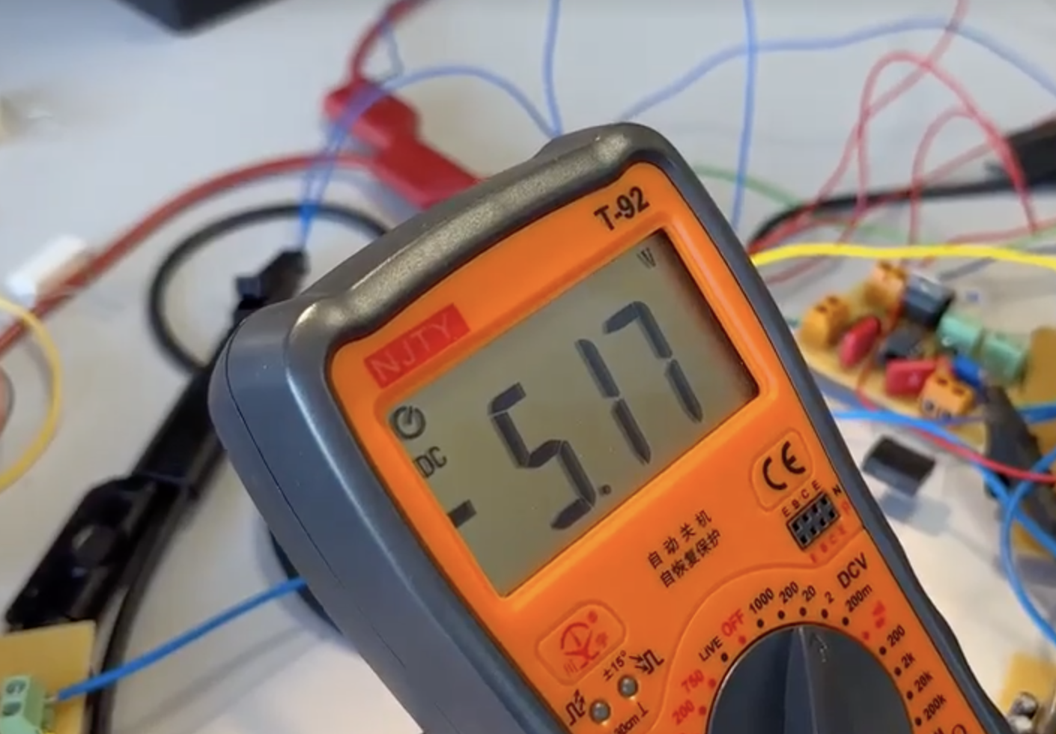
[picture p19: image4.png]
    
    \caption{Buck converter voltage (V3) with PV satisfies the requirement for voltage:}
    \label{fig:v3_with_pv}
\end{figure}

\vspace{0.5cm}

\subsection{Requirement compliance and limitations}
\noindent
The measured rail voltages can be compared directly with the specification. The buck
output $V_3$ measured $4.8~\text{V}$ without the panel and $5.1~\text{V}$ with it,
which is inside the required $5~\text{V}\pm0.5~\text{V}$ band (Krav~7) in both cases.

\vspace{0.5cm} \noindent
The rectified bus $V_1$ is required to be $15~\text{V}\pm1~\text{V}$ (Krav~1). This was
met with the solar panel active, where $V_1$ reached $15.5~\text{V}$, but in
generator-only operation the bus settled at $11.5~\text{V}$, below the lower limit. The
reason is that the PID loop on the generator side was not able to hold the bus at the
target under this operating point, and the high-side switching of the generator-side
MOSFET was not ideal (discussed in Section~\ref{sec:diskussion}). The current-step
behaviour of Krav~2 and Krav~3 (delivery of $300~\text{mA}$ to the buck and recovery
within $1.0~\text{s}$ after a $100$--$300~\text{mA}$ load change) was not characterised
quantitatively and is therefore only partially verified.

\vspace{0.5cm} \noindent
The boost rail $V_2$ is required to stay within $10~\text{V}\pm1~\text{V}$ (Krav~4 and
Krav~6). On the bench the boost converter reached $10.1~\text{V}$ at a $48\%$ duty cycle
(Section~\ref{sec:boost}), comfortably inside the band, but in the integrated system the
same rail measured $11.06~\text{V}$ without the panel and $11.5~\text{V}$ with it ---
about $1~\text{V}$ above the upper limit. The difference comes from the boost operating
at a fixed duty cycle while its input voltage and load differ from the bench conditions,
so the duty cycle was no longer the value that produces exactly $10~\text{V}$. Closing a
control loop around $V_2$, or trimming the duty cycle to the integrated operating point,
would bring the rail back inside tolerance; this was not done in the present setup. The
$\geq150~\text{mA}$ delivery of Krav~5 is met, since the rail supplies the $68~\Omega$
load at roughly $11~\text{V}$, corresponding to about $160~\text{mA}$.

\vspace{0.5cm}

\subsection{PV section}
With the results obtained from table \ref{tab:pv_measurements}, we were able to test the PV-system by connecting the MPPT controller to the panel itself. Before doing this, we however tested that the INA219-module read both voltage and current correct, by connecting a load with a stable voltage source. This way, we could verify the voltage and current reading, by using Ohm's law to determine the theoretical current.\\
\\
When the entire system was connected, we where able to read the voltage and current in "real time" and verify that we where getting the maximum amount of power, for the load.
\vspace{0.5cm}
The boost converter was tested in order to verify that it fulfills the requirement for the V2 output voltage.
\vspace{0.5cm}
The converter was supplied with an input voltage of 5 V from the energy storage and operated with a PWM switching frequency of 10 kHz. 
At a duty cycle of 48\%, the measured output voltage was approximately 10.1 V.
\vspace{0.5cm}
This result matches the target voltage for the V2 rail, which is specified as 10 V $\pm$ 1 V. 
The measured peak-to-peak ripple was approximately 56 mV, corresponding to about 0.5\% of the output voltage, indicating stable operation of the converter.
\vspace{0.5cm}
The measurement confirms that the boost converter is able to step up the voltage from the energy storage and regulate the output voltage to the required level.

\ifdefined\mainfile\else\end{document}\fi

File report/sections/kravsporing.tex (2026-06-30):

\ifdefined\mainfile\else\documentclass{article}\input{../preamble}\begin{document}\fi

\section{Specifications}
\label{sec:kravsporing}
% Sporing af kravspecifikationens 18 krav -> ansvarlig / delsystem / status.
% Hold synkront med GitHub-issues.

\begin{table}[H]
    \centering
    \begin{tabular}{c l c l l}
        \toprule
        \textbf{\#} & \textbf{Requirement} & \textbf{Pri.} & \textbf{Subsystem} & \textbf{Status} \\
        \midrule
        1  & AC generator voltage (V1)     & 1 & Generator   & Partial \\
        2  & AC generator current          & 1 & Generator   & Met\\
        3  & V1 under load                 & 1 & Generator   & Not shown \\
        4  & Load voltage (V2)             & 1 & Boost       & Partial \\
        5  & Load current (V2)             & 1 & Boost       & Met \\
        6  & V2 under load                 & 1 & Boost       & Partial \\
        7  & Energy storage current (V3)   & 1 & Solar       & Met \\
        8  & Voltage conversion            & 1 & Buck/Boost  & Met \\
        9  & Discrete components           & 1 & Buck/Boost  & Met \\
        10 & Current measurement           & 1 & Measurement & Met \\
        11 & Energy source prioritization  & 1 & Integration & Met \\
        12 & Buck and Boost implemented    & 1 & Buck/Boost  & Met \\
        13 & System monitoring             & 2 & Software    & Not done \\
        14 & Monitoring every 1.0\,s       & 2 & Software    & Not done \\
        15 & Software design (Arduino)     & 2 & Software    & Partial \\
        16 & System test (100\,W LED)      & 1 & Test        & Met \\
        17 & Linear regulator              & 2 & Solar       & Not done \\
        18 & Data processing platform      & 2 & Software    & Met \\
        \bottomrule
    \end{tabular}
    \caption{Requirement tracing. Pri.~1 = must be designed and implemented; Pri.~2 =
    voluntary. Status: \emph{Met} = demonstrated within specification;
    \emph{Partial} = implemented but not fully verified against the numeric criterion;
    \emph{Not shown} = not characterised quantitatively; \emph{Not done} = voluntary
    requirement not implemented.}
    \label{tab:kravsporing}
\end{table}

\ifdefined\mainfile\else\end{document}\fi

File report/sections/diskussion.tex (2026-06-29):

 \ifdefined\mainfile\else\documentclass{article}\input{../preamble}\begin{document}\fi

\section{Discussion}
\label{sec:diskussion}
% Refleksion over resultater, afvigelser fra krav, designvalg og mulige forbedringer.

% TODO.

When we tested the complete system, we could see that the system worked, but the values were not exactly the same in all situations. This was expected, because the system consists of many different parts that affect each other. The motor, generator, rectifier, capacitors, buck converter, boost converter, and solar panel are all connected together, so when one part changes, the rest of the system can also change a little.

\vspace{0.5cm} \noindent
Without the solar panel active, the boost converter gave 11.06 V, the buck converter gave 4.8 V, and the rectifier output was 11.5 V. When the solar panel was active, the boost converter gave 11.5 V, the buck converter gave 5.1 V, and the rectifier output increased to 15.5 V. These values are not perfect, but they are close to what we wanted. In a real circuit, it is difficult to get exactly the same values as in theory, because there are losses in the components, voltage drops in the wires, ripple from the converters, and some uncertainty in the measurements.

\vspace{0.5cm} \noindent
The clearest result from the test was the motor current. When the solar panel was not active, the motor used 1.412 A. When the solar panel was active, the motor current dropped to 0.944 A. This is a reduction of about 33\%. This shows that the solar panel actually helped the system. Since the solar panel supplied some of the power, the motor-generator did not need to work as hard, and therefore the motor used less current.

\vspace{0.5cm} \noindent
The rectifier output was also higher when the solar panel was active. This makes sense, because the solar panel adds extra energy to the system and changes the voltage level on the DC side. Since the capacitors and converters are connected together, the voltage in one part of the system can influence the voltage in another part. Therefore, the increase from 11.5 V to 15.5 V is not necessarily a problem, but more a result of the complete system finding a new operating point.
\newline
Another factor that may explain this is that the MOSFET on the generator side was not driven ideally. An NMOS can be used for high-side switching, but it requires the gate voltage to remain sufficiently higher than the source voltage. In the implemented circuit, both the gate and drain were supplied with approximately 12 V or 15 V. When the MOSFET turned on, the source voltage increased towards the gate voltage, thereby reducing the gate-source voltage. As a result, the MOSFET may not have been fully enhanced and may have operated partly in its active region. This would create a significant voltage drop across the MOSFET and increase the amount of energy dissipated as heat.
\newline
A simpler solution would be to replace the NMOS with a PMOS, such as the IRF5305, which turns on when the source voltage is higher than the gate voltage. When the source is connected to 12 V or 15 V and the gate is pulled towards 0 V, the PMOS obtains a sufficiently large source-gate voltage. The IRF5305 has a maximum $R_{\mathrm{DS(on)}}$ of $0.06,\Omega$ at $V_{\mathrm{GS}}=-10,\mathrm{V}$. Since the source remains connected to the input supply, the gate-source voltage can remain approximately constant during the ON-period. This allows the MOSFET to operate with a low $R_{\mathrm{DS(on)}}$, thereby reducing conduction losses and heat dissipation.
By implementing the buck converter in this way, the high-side driver circuit used for the NMOS-based buck converter on the PV side could also be avoided. This would simplify the overall system and is expected to provide more reliable switching. The proposed buck-converter circuit is shown below. This circuit was not experimentally verified as part of the complete system.
\begin{figure}[H]
    \centering
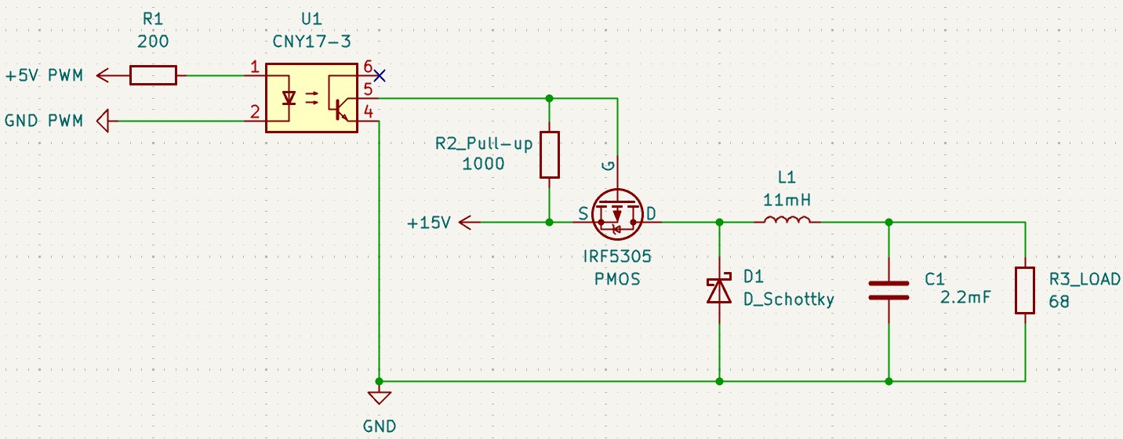
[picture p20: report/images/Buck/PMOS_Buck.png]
    
    \caption{Proposed Improved Buck Converter, not implemented}
    \label{fig:placeholder}
\end{figure}

\vspace{0.5cm} \noindent
We also performed a load test. Here we saw that when the load was increased, the measured voltage also increased. At first this was not what we expected, because normally a higher load can cause the voltage to drop. However, our system is not just a simple voltage source with a resistor. It contains converters, capacitors, PWM control, and the motor-generator. When the load changes, the converters and the generator can also change their operating point. This can explain why the voltage increased during the test.

\vspace{0.5cm} \noindent
In the load test, the boost converter behaved almost the same with and without the solar panel active. This means that the boost converter was able to keep approximately the same output voltage even when the solar panel was connected. This is good, because it shows that the boost converter was stable. At the same time, it also means that the solar panel effect is not very visible from the boost voltage alone. The motor current is a better value to look at, because it clearly shows that the motor was less loaded when the solar panel was active.

\vspace{0.5cm} \noindent
Some of the differences in the measured values can also come from the practical setup. The converters are not ideal, and there are losses in the MOSFETs, diodes, inductors, and capacitors. The wires and connections also have some resistance. Since the circuit uses PWM switching, there will also be some ripple and noise. The capacitors reduce this, but they cannot remove it completely.
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

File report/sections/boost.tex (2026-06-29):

\ifdefined\mainfile\else\documentclass{article}\input{../preamble}\begin{document}\fi

\subsection{Boost-converter}
\label{sec:boost}
% Selvbygget boost-konverter til pulserende 10\,V last (krav 4--6, 8, 12). Dimensionering, regulering og last-respons.

% TODO: design, beregninger, simulering, implementering.

\subsection*{Measurement results}
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

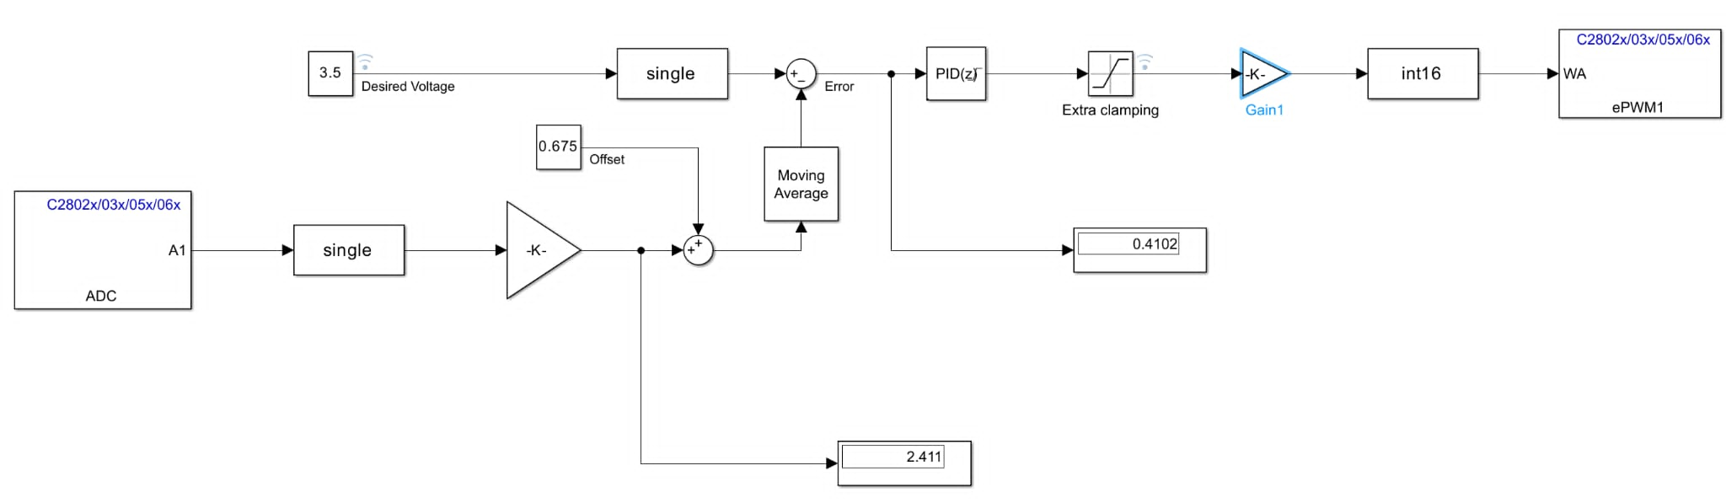
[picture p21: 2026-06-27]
report/images/MPPT/image.png

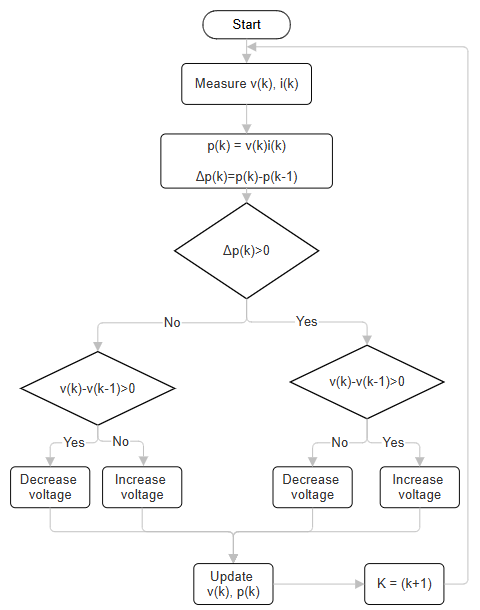
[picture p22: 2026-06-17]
report/images/MPPT/MPPT_Flowchart.png

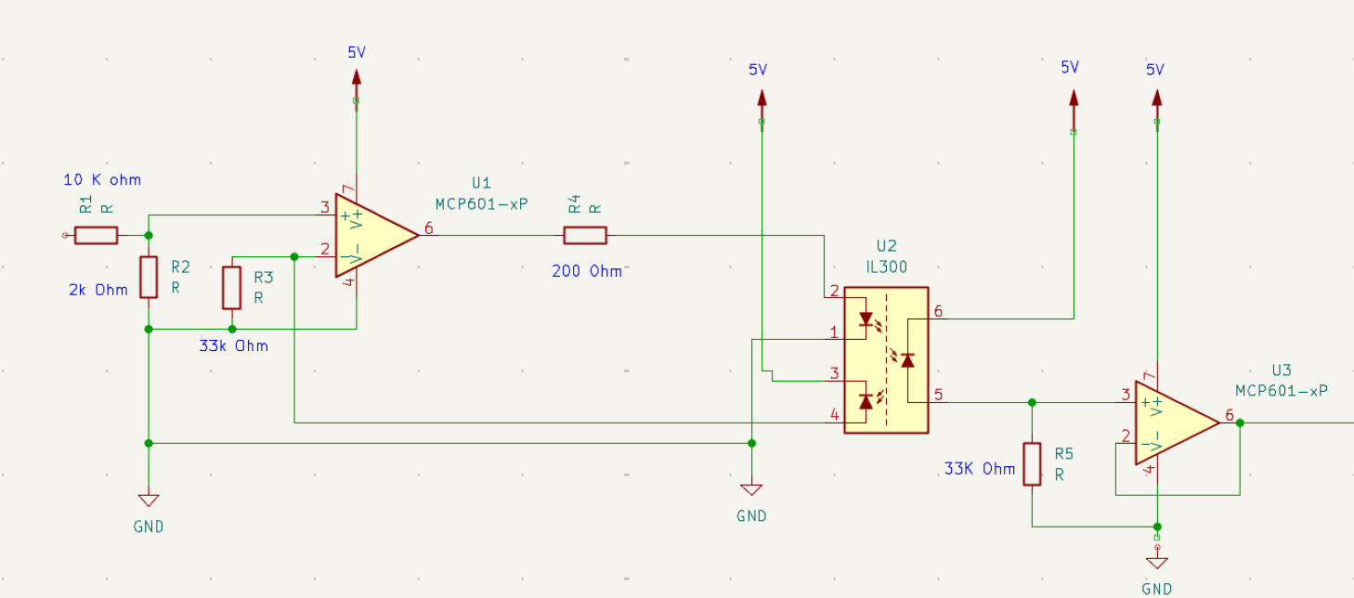
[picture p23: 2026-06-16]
report/images/Feedback-circuit/Feedback circuit.png

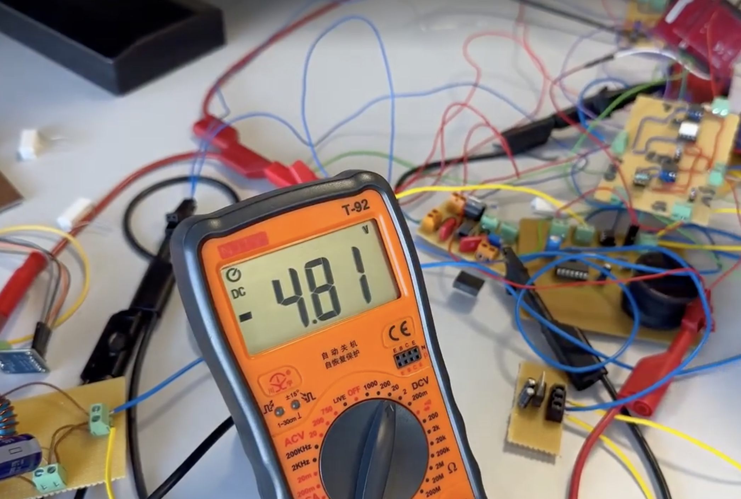
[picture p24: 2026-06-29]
report/images/integration/image.png

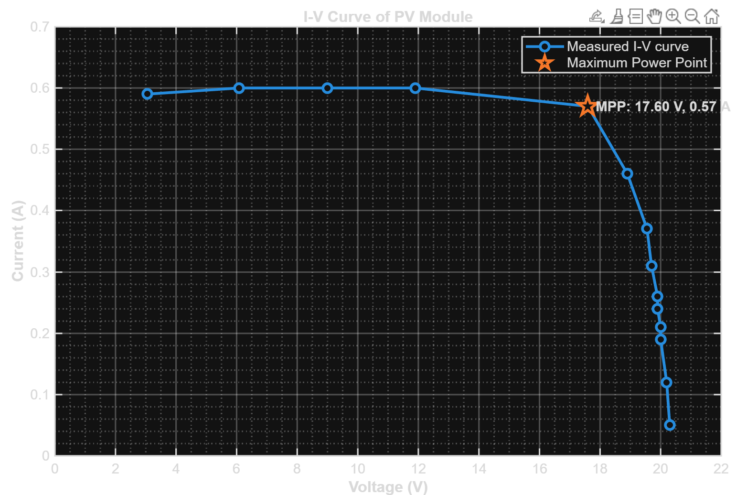
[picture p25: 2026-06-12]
report/images/Solarpanel/IV-curve of PV module.png

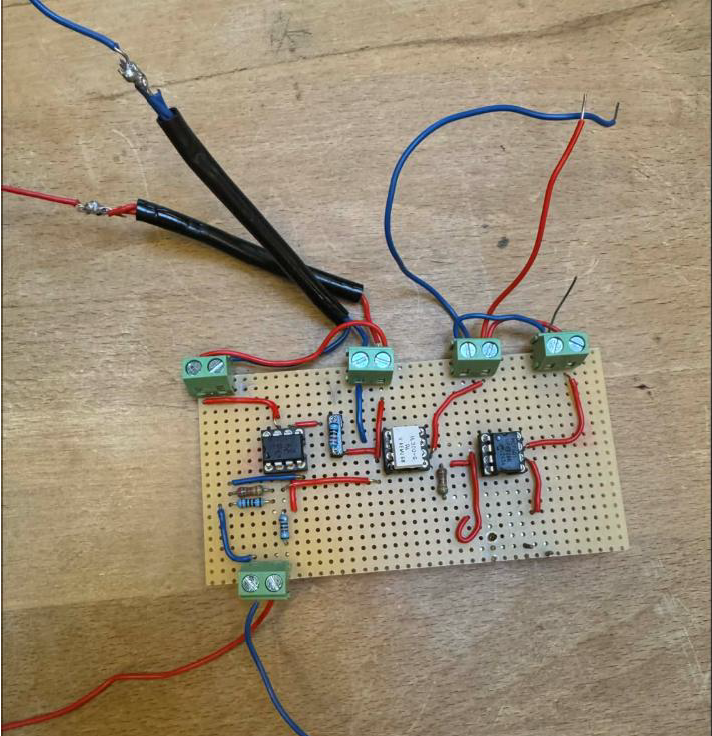
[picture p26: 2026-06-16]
report/images/Feedback-circuit/Feedback circuit hulprint.png

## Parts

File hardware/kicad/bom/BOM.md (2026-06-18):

# BOM — 62768 energy system

> Genereret fra [`footprint_map.csv`](footprint_map.csv) med `tools/bom_to_md.py` — **redigér CSV'en, ikke denne fil.** Alle substitutioner er flagget i note-kolonnen.

## Samlet indkøbsliste

| Antal | Del | Pakke | Kilde |
|---|---|---|---|
| 25 | 2 pol skrueterminal | `TerminalBlock_bornier-2_P5.08mm` | shop |
| 22 | 1k00 | `R_Axial_DIN0207_L6.3mm_D2.5mm_P7.62mm_Horizontal` | shop |
| 13 | 100n keramisk | `C_Disc_D5.0mm_W2.5mm_P5.00mm` | shop |
| 11 | Header Male | `PinHeader_1x02_P2.54mm_Vertical` | shop |
| 9 | 10k0 | `R_Axial_DIN0207_L6.3mm_D2.5mm_P7.62mm_Horizontal` | shop |
| 9 | 1N4006 | `D_DO-41_SOD81_P10.16mm_Horizontal` | shop |
| 8 | 1R00 | `R_Axial_DIN0207_L6.3mm_D2.5mm_P7.62mm_Horizontal` | shop |
| 6 | 1N4148 | `D_DO-35_SOD27_P7.62mm_Horizontal` | shop |
| 6 | 22uF 50V | `CP_Radial_D8.0mm_P3.50mm` | shop |
| 6 | 4700uF 50V | `CP_Radial_D18.0mm_P7.50mm` | shop |
| 6 | 47uF 50V | `CP_Radial_D8.0mm_P3.50mm` | shop |
| 5 | 1N5817 | `D_DO-41_SOD81_P10.16mm_Horizontal` | shop |
| 5 | 200R | `R_Axial_DIN0207_L6.3mm_D2.5mm_P7.62mm_Horizontal` | shop |
| 5 | 9k09 | `R_Axial_DIN0207_L6.3mm_D2.5mm_P7.62mm_Horizontal` | shop |
| 5 | IRF530 | `TO-220-3_Vertical_LaserPads` | shop |
| 5 | MCP601 | `DIP-8_W7.62mm_LongPads` | kit |
| 5 | toroid (egen-vikling) | `L_Toroid_Vertical_L34.5mm_W15.0mm_P28.20mm_LaserPads` | egen-vikling |
| 4 | 10R0 | `R_Axial_DIN0207_L6.3mm_D2.5mm_P7.62mm_Horizontal` | shop |
| 4 | Header Male | `PinHeader_1x03_P2.54mm_Vertical` | shop |
| 4 | IR2110 | `DIP-14_W7.62mm_LongPads` | kit |
| 3 | 10n keramisk | `C_Disc_D5.0mm_W2.5mm_P5.00mm` | shop |
| 3 | 1uF keramik/film | `C_Disc_D5.0mm_W2.5mm_P5.00mm` | shop |
| 3 | 2k00 | `R_Axial_DIN0207_L6.3mm_D2.5mm_P7.62mm_Horizontal` | shop |
| 3 | 4N25 | `DIP-6_W7.62mm_LongPads` | shop |
| 3 | BZX55C3V0 | `D_DO-35_SOD27_P7.62mm_Horizontal` | shop |
| 3 | LM358 | `DIP-8_W7.62mm_LongPads` | shop |
| 2 | 3 pol skrueterminal | `TerminalBlock_bornier-3_P5.08mm` | shop |
| 2 | 332R (E96) | `R_Axial_DIN0207_L6.3mm_D2.5mm_P7.62mm_Horizontal` | shop |
| 2 | 33k2 (E96) | `R_Axial_DIN0207_L6.3mm_D2.5mm_P7.62mm_Horizontal` | shop |
| 2 | 49k9 (E96) | `R_Axial_DIN0207_L6.3mm_D2.5mm_P7.62mm_Horizontal` | shop |
| 2 | CNY17 | `DIP-6_W7.62mm_LongPads` | shop |
| 1 | 100k | `R_Axial_DIN0207_L6.3mm_D2.5mm_P7.62mm_Horizontal` | shop |
| 1 | 12k0 | `R_Axial_DIN0207_L6.3mm_D2.5mm_P7.62mm_Horizontal` | shop |
| 1 | 1N5822 (BESTIL) | `D_DO-201AD_P15.24mm_Horizontal` | bestil |
| 1 | 20K trimmer | `Potentiometer_Bourns_3296W_Vertical` | shop |
| 1 | 220R | `R_Axial_DIN0207_L6.3mm_D2.5mm_P7.62mm_Horizontal` | shop |
| 1 | 22k6 | `R_Axial_DIN0207_L6.3mm_D2.5mm_P7.62mm_Horizontal` | shop |
| 1 | 470uF 25V | `CP_Radial_D8.0mm_P3.50mm` | shop |
| 1 | 4k75 | `R_Axial_DIN0207_L6.3mm_D2.5mm_P7.62mm_Horizontal` | shop |
| 1 | 6k49 (E96) | `R_Axial_DIN0207_L6.3mm_D2.5mm_P7.62mm_Horizontal` | shop |
| 1 | 8n2 film (box) | `C_Rect_L13.0mm_W6.0mm_P10.00mm_FKS3_FKP3_MKS4` | shop |
| 1 | BZX55C5V1 | `D_DO-35_SOD27_P7.62mm_Horizontal` | shop |
| 1 | DIP-Switch | `SW_DIP_SPSTx02_Slide_9.78x7.26mm_W7.62mm_P2.54mm` | shop |
| 1 | Header Male | `PinHeader_1x05_P2.54mm_Vertical` | shop |
| 1 | IL300 | `DIP-8_W7.62mm_LongPads` | kit |
| 1 | ILD74 | `DIP-8_W7.62mm_LongPads` | kit |
| 1 | IRF540 | `TO-220-3_Vertical_LaserPads` | shop |
| 1 | LM7805 | `TO-220-3_Vertical_LaserPads` | shop |
| 1 | Motraxx SR555 | `TerminalBlock_bornier-2_P5.08mm` | kit |
| 1 | NE555 | `DIP-8_W7.62mm_LongPads` | shop |
| 1 | TIP41A | `TO-220-3_Vertical_LaserPads` | shop |

## Buck-converter (`buck`)

| Ref | Værdi | Del (indkøb) | Kilde | Footprint | Noter |
|---|---|---|---|---|---|
| D1 | 1N5819 | 1N5817 | shop | `Diode_THT:D_DO-41_SOD81_P10.16mm_Horizontal` | SUBSTITUTION: 1N5819 ikke i shoppen. 1N5817 (Schottky 1A/20V) OK ved 15V bus med marginal - tjek spidsspaending |
| M1 | IRF530N | IRF530 | shop | `energy_system:TO-220-3_Vertical_LaserPads` | shoppen har IRF530 (uden N) - samme pinout G-D-S og TO-220 |
| R1 | 330 | 332R (E96) | shop | `Resistor_THT:R_Axial_DIN0207_L6.3mm_D2.5mm_P7.62mm_Horizontal` | E96: 330 -> 332R (0.6% afvigelse) eller 2x packs - uproblematisk for LED-formodstand |
| R2 | 10k | 10k0 | shop | `Resistor_THT:R_Axial_DIN0207_L6.3mm_D2.5mm_P7.62mm_Horizontal` |  |
| C1 | 47u | 47uF 50V | shop | `Capacitor_THT:CP_Radial_D8.0mm_P3.50mm` |  |
| U1 | 4N25 | 4N25 | shop | `Package_DIP:DIP-6_W7.62mm_LongPads` | monter i DIP6-sokkel (shop) |
| L1 | 470u | toroid (egen-vikling) | egen-vikling | `energy_system:L_Toroid_Vertical_L34.5mm_W15.0mm_P28.20mm_LaserPads` | Maalt med skydelaere paa den fysiske toroid: OD 34.5mm staaende paa kant; ben-pitch 28.2mm c-c (26.6mm indvendigt + 1.6mm ben); drill 2.0mm. Genberegn ripple med viklet L (Lec 2: dI=Vs*k(1-k)/(2fL)) |
| J1 | V1 ind (15V) | 2 pol skrueterminal | shop | `TerminalBlock:TerminalBlock_bornier-2_P5.08mm` |  |
| J2 | 5V ud | 2 pol skrueterminal | shop | `TerminalBlock:TerminalBlock_bornier-2_P5.08mm` |  |
| J3 | PWM (isoleret) | Header Male | shop | `Connector_PinHeader_2.54mm:PinHeader_1x02_P2.54mm_Vertical` | PWM + GND_MCU (isoleret jord - maa IKKE forbindes til effekt-GND) |
| J4 | gate-forsyning | Header Male | shop | `Connector_PinHeader_2.54mm:PinHeader_1x02_P2.54mm_Vertical` | OBS: +12V_SW refereret til SW-knuden (flydende hjaelpeforsyning) - high-side switch. Se PCB_RESULTS.md |

## Boost-converter (`boost`)

| Ref | Værdi | Del (indkøb) | Kilde | Footprint | Noter |
|---|---|---|---|---|---|
| D1 | 1N5819 | 1N5817 | shop | `Diode_THT:D_DO-41_SOD81_P10.16mm_Horizontal` | SUBSTITUTION: som buck. Boost-udgang ~10V - 20V-rating OK |
| M1 | IRF530 | IRF530 | shop | `energy_system:TO-220-3_Vertical_LaserPads` |  |
| R1 | 330 | 332R (E96) | shop | `Resistor_THT:R_Axial_DIN0207_L6.3mm_D2.5mm_P7.62mm_Horizontal` |  |
| R2 | 10k | 10k0 | shop | `Resistor_THT:R_Axial_DIN0207_L6.3mm_D2.5mm_P7.62mm_Horizontal` |  |
| C1 | 47u | 47uF 50V | shop | `Capacitor_THT:CP_Radial_D8.0mm_P3.50mm` |  |
| U1 | 4N25 | 4N25 | shop | `Package_DIP:DIP-6_W7.62mm_LongPads` | DIP6-sokkel |
| L1 | 470u | toroid (egen-vikling) | egen-vikling | `energy_system:L_Toroid_Vertical_L34.5mm_W15.0mm_P28.20mm_LaserPads` | som buck L1: maalt toroid OD 34.5mm / pitch 28.2mm / drill 2.0mm |
| J1 | lager ind (5V) | 2 pol skrueterminal | shop | `TerminalBlock:TerminalBlock_bornier-2_P5.08mm` |  |
| J2 | V2 ud (10V) | 2 pol skrueterminal | shop | `TerminalBlock:TerminalBlock_bornier-2_P5.08mm` |  |
| J3 | PWM (isoleret) | Header Male | shop | `Connector_PinHeader_2.54mm:PinHeader_1x02_P2.54mm_Vertical` |  |
| J4 | gate-forsyning | Header Male | shop | `Connector_PinHeader_2.54mm:PinHeader_1x02_P2.54mm_Vertical` | +12V/GND (low-side switch - jordrefereret OK) |

## Motor-drive (`drive`)

| Ref | Værdi | Del (indkøb) | Kilde | Footprint | Noter |
|---|---|---|---|---|---|
| R1 | 200 | 200R | shop | `Resistor_THT:R_Axial_DIN0207_L6.3mm_D2.5mm_P7.62mm_Horizontal` |  |
| R2 | 10 | 10R0 | shop | `Resistor_THT:R_Axial_DIN0207_L6.3mm_D2.5mm_P7.62mm_Horizontal` | gate-seriemodstand |
| R3 | 1k | 1k00 | shop | `Resistor_THT:R_Axial_DIN0207_L6.3mm_D2.5mm_P7.62mm_Horizontal` |  |
| R4 | 1k | 1k00 | shop | `Resistor_THT:R_Axial_DIN0207_L6.3mm_D2.5mm_P7.62mm_Horizontal` |  |
| C1 | 22u | 22uF 50V | shop | `Capacitor_THT:CP_Radial_D8.0mm_P3.50mm` |  |
| C2 | 100n | 100n keramisk | shop | `Capacitor_THT:C_Disc_D5.0mm_W2.5mm_P5.00mm` |  |
| D1 | 1N4007 | 1N4006 | shop | `Diode_THT:D_DO-41_SOD81_P10.16mm_Horizontal` | SUBSTITUTION: 1N4007 (1000V) ikke i shoppen; 1N4006 (800V) rigelig ved 20V. Friloeb over motor |
| D2 | 1N4007 | 1N4006 | shop | `Diode_THT:D_DO-41_SOD81_P10.16mm_Horizontal` | SUBSTITUTION: som D1. Gate-vejs-diode |
| Q1 | IRF540N | IRF540 | shop | `energy_system:TO-220-3_Vertical_LaserPads` | kittet har ogsaa IRF540N (datasheet i docs/datasheets) - TO-220AB bekraeftet |
| U1 | ILD74 | ILD74 | kit | `Package_DIP:DIP-8_W7.62mm_LongPads` | KIT-DEL - IKKE i shoppen. Dual-kanal opto DIP-8 (datasheet bekraeftet). 4N25 er IKKE drop-in (single + anden pinout). DIP8-sokkel |
| U2 | IR2110 | IR2110 | kit | `Package_DIP:DIP-14_W7.62mm_LongPads` | KIT-DEL - IKKE i shoppen. 14-Lead PDIP bekraeftet i datasheet. DIP14-sokkel |
| M1 | Motor_DC | Motraxx SR555 | kit | `TerminalBlock:TerminalBlock_bornier-2_P5.08mm` | motor tilsluttes via skrueterminal (ledninger) |
| J1 | PWM ind | Header Male | shop | `Connector_PinHeader_2.54mm:PinHeader_1x02_P2.54mm_Vertical` |  |
| J2 | forsyning | 3 pol skrueterminal | shop | `TerminalBlock:TerminalBlock_bornier-3_P5.08mm` | +20V / +15V / GND |

## Feedback (isoleret) (`feedback`)

| Ref | Værdi | Del (indkøb) | Kilde | Footprint | Noter |
|---|---|---|---|---|---|
| R1 | 10k | 10k0 | shop | `Resistor_THT:R_Axial_DIN0207_L6.3mm_D2.5mm_P7.62mm_Horizontal` |  |
| R2 | 2k | 2k00 | shop | `Resistor_THT:R_Axial_DIN0207_L6.3mm_D2.5mm_P7.62mm_Horizontal` |  |
| R3 | 33k | 33k2 (E96) | shop | `Resistor_THT:R_Axial_DIN0207_L6.3mm_D2.5mm_P7.62mm_Horizontal` | E96: 33k -> 33k2 (0.6%) |
| R4 | 200 | 200R | shop | `Resistor_THT:R_Axial_DIN0207_L6.3mm_D2.5mm_P7.62mm_Horizontal` |  |
| R5 | 33k | 33k2 (E96) | shop | `Resistor_THT:R_Axial_DIN0207_L6.3mm_D2.5mm_P7.62mm_Horizontal` |  |
| U1 | IL300 | IL300 | kit | `Package_DIP:DIP-8_W7.62mm_LongPads` | KIT-DEL - IKKE i shoppen og INGEN aekvivalent. Servo-loopet kraever netop IL300. DIP-8 bekraeftet i datasheet. DIP8-sokkel |
| U3 | MCP601 | MCP601 | kit | `Package_DIP:DIP-8_W7.62mm_LongPads` | KIT-DEL. PDIP-8 bekraeftet (DS21314G). Shop-alternativ: MCP6002 (dual - kraever omtegning) eller LM358. DIP8-sokkel |
| U4 | MCP601 | MCP601 | kit | `Package_DIP:DIP-8_W7.62mm_LongPads` | som U3 |
| J1 | ind + forsyning | Header Male | shop | `Connector_PinHeader_2.54mm:PinHeader_1x03_P2.54mm_Vertical` | INPUT / +5V / GND |
| J2 | FB ud | Header Male | shop | `Connector_PinHeader_2.54mm:PinHeader_1x02_P2.54mm_Vertical` |  |

## Rectifier (3-faset bro) (`rectifier`)

| Ref | Værdi | Del (indkøb) | Kilde | Footprint | Noter |
|---|---|---|---|---|---|
| D1 | 1N4006 | 1N4006 | shop | `Diode_THT:D_DO-41_SOD81_P10.16mm_Horizontal` | 6-diode 3-faset bro; 1A/800V rigeligt til 300mA / 8x trafo-spaending |
| D2 | 1N4006 | 1N4006 | shop | `Diode_THT:D_DO-41_SOD81_P10.16mm_Horizontal` |  |
| D3 | 1N4006 | 1N4006 | shop | `Diode_THT:D_DO-41_SOD81_P10.16mm_Horizontal` |  |
| D4 | 1N4006 | 1N4006 | shop | `Diode_THT:D_DO-41_SOD81_P10.16mm_Horizontal` |  |
| D5 | 1N4006 | 1N4006 | shop | `Diode_THT:D_DO-41_SOD81_P10.16mm_Horizontal` |  |
| D6 | 1N4006 | 1N4006 | shop | `Diode_THT:D_DO-41_SOD81_P10.16mm_Horizontal` |  |
| C1 | 4700u/50V | 4700uF 50V | shop | `Capacitor_THT:CP_Radial_D18.0mm_P7.50mm` | 3x parallel = 14.1mF (~spec'ens 15mF). VERIFICER fysisk diameter/pitch foer bestilling - shoppen angiver ikke dimensioner |
| C2 | 4700u/50V | 4700uF 50V | shop | `Capacitor_THT:CP_Radial_D18.0mm_P7.50mm` |  |
| C3 | 4700u/50V | 4700uF 50V | shop | `Capacitor_THT:CP_Radial_D18.0mm_P7.50mm` |  |
| R1 | 10k | 10k0 | shop | `Resistor_THT:R_Axial_DIN0207_L6.3mm_D2.5mm_P7.62mm_Horizontal` | bleeder |
| J1 | 3-fase ind | 3 pol skrueterminal | shop | `TerminalBlock:TerminalBlock_bornier-3_P5.08mm` | fra trafo-sekundaerer |
| J2 | V1 ud | 2 pol skrueterminal | shop | `TerminalBlock:TerminalBlock_bornier-2_P5.08mm` |  |

## MPPT / PV (`mppt`)

| Ref | Værdi | Del (indkøb) | Kilde | Footprint | Noter |
|---|---|---|---|---|---|
| D1 | 1N5817 | 1N5817 | shop | `Diode_THT:D_DO-41_SOD81_P10.16mm_Horizontal` | seriediode mod tilbage-stroem i panelet |
| DZ1 | BZX55C5V1 | BZX55C5V1 | shop | `Diode_THT:D_DO-35_SOD27_P7.62mm_Horizontal` | 5.1V reference |
| Q1 | TIP41A | TIP41A | shop | `energy_system:TO-220-3_Vertical_LaserPads` | pass-transistor TO-220 (BD139/TO-126 droppet: 2.28mm pitch kan ikke overholde laserens 0.8mm clearance). SKAL have koeleplade (op til ~7W ved fuld PV-stroem) |
| U1 | LM358 | LM358 | shop | `Package_DIP:DIP-8_W7.62mm_LongPads` | forsynes fra PV-bus (<32V OK). DIP8-sokkel |
| C1 | 4700u/50V | 4700uF 50V | shop | `Capacitor_THT:CP_Radial_D18.0mm_P7.50mm` | MPPT-kondensator 3x parallel = 14.1mF |
| C2 | 4700u/50V | 4700uF 50V | shop | `Capacitor_THT:CP_Radial_D18.0mm_P7.50mm` |  |
| C3 | 4700u/50V | 4700uF 50V | shop | `Capacitor_THT:CP_Radial_D18.0mm_P7.50mm` |  |
| C4 | 100n | 100n keramisk | shop | `Capacitor_THT:C_Disc_D5.0mm_W2.5mm_P5.00mm` | LM358 afkobling |
| C5 | 47u | 47uF 50V | shop | `Capacitor_THT:CP_Radial_D8.0mm_P3.50mm` | udgangskondensator V3 |
| C6 | 100n | 100n keramisk | shop | `Capacitor_THT:C_Disc_D5.0mm_W2.5mm_P5.00mm` | zener-stoejfilter |
| R1 | 100k | 100k | shop | `Resistor_THT:R_Axial_DIN0207_L6.3mm_D2.5mm_P7.62mm_Horizontal` | PV-spaendingsdeler top |
| R2 | 22k6 | 22k6 | shop | `Resistor_THT:R_Axial_DIN0207_L6.3mm_D2.5mm_P7.62mm_Horizontal` | deler bund: 21V -> 3.9V til ADC |
| R3 | 4k75 | 4k75 | shop | `Resistor_THT:R_Axial_DIN0207_L6.3mm_D2.5mm_P7.62mm_Horizontal` | zener-bias ~2.7mA |
| R4 | 1k00 | 1k00 | shop | `Resistor_THT:R_Axial_DIN0207_L6.3mm_D2.5mm_P7.62mm_Horizontal` | basemodstand |
| R5 | 1R00 | 1R00 | shop | `Resistor_THT:R_Axial_DIN0207_L6.3mm_D2.5mm_P7.62mm_Horizontal` | shunt 2x1R parallel = 0R5 (effekt: 0.6A -> 2x 0.18W i 1/4W-modstande) |
| R6 | 1R00 | 1R00 | shop | `Resistor_THT:R_Axial_DIN0207_L6.3mm_D2.5mm_P7.62mm_Horizontal` |  |
| R7 | 1k00 | 1k00 | shop | `Resistor_THT:R_Axial_DIN0207_L6.3mm_D2.5mm_P7.62mm_Horizontal` | inverterende indgang |
| R8 | 9k09 | 9k09 | shop | `Resistor_THT:R_Axial_DIN0207_L6.3mm_D2.5mm_P7.62mm_Horizontal` | gain -9.09: 0.6A -> +2.7V |
| J1 | PV ind | 2 pol skrueterminal | shop | `TerminalBlock:TerminalBlock_bornier-2_P5.08mm` |  |
| J2 | til lager (V3) | 2 pol skrueterminal | shop | `TerminalBlock:TerminalBlock_bornier-2_P5.08mm` |  |
| J3 | sense -> Arduino | Header Male | shop | `Connector_PinHeader_2.54mm:PinHeader_1x03_P2.54mm_Vertical` | PV_V / PV_I / GND |

## Current sense (3 kanaler) (`current_sense`)

| Ref | Værdi | Del (indkøb) | Kilde | Footprint | Noter |
|---|---|---|---|---|---|
| R11 | 1R00 | 1R00 | shop | `Resistor_THT:R_Axial_DIN0207_L6.3mm_D2.5mm_P7.62mm_Horizontal` | lavside-shunt kanal 1 (V1->buck; 300mA -> 90mW OK i 1/4W) |
| R12 | 1k00 | 1k00 | shop | `Resistor_THT:R_Axial_DIN0207_L6.3mm_D2.5mm_P7.62mm_Horizontal` | gain-ben |
| R13 | 9k09 | 9k09 | shop | `Resistor_THT:R_Axial_DIN0207_L6.3mm_D2.5mm_P7.62mm_Horizontal` | gain 10.09: 300mA -> 3.03V |
| R21 | 1R00 | 1R00 | shop | `Resistor_THT:R_Axial_DIN0207_L6.3mm_D2.5mm_P7.62mm_Horizontal` | kanal 2 (boost->last) |
| R22 | 1k00 | 1k00 | shop | `Resistor_THT:R_Axial_DIN0207_L6.3mm_D2.5mm_P7.62mm_Horizontal` |  |
| R23 | 9k09 | 9k09 | shop | `Resistor_THT:R_Axial_DIN0207_L6.3mm_D2.5mm_P7.62mm_Horizontal` |  |
| R31 | 1R00 | 1R00 | shop | `Resistor_THT:R_Axial_DIN0207_L6.3mm_D2.5mm_P7.62mm_Horizontal` | kanal 3 (lager V3) |
| R32 | 1k00 | 1k00 | shop | `Resistor_THT:R_Axial_DIN0207_L6.3mm_D2.5mm_P7.62mm_Horizontal` |  |
| R33 | 9k09 | 9k09 | shop | `Resistor_THT:R_Axial_DIN0207_L6.3mm_D2.5mm_P7.62mm_Horizontal` |  |
| U1 | LM358 | LM358 | shop | `Package_DIP:DIP-8_W7.62mm_LongPads` | indgange gaar til GND (derfor ikke TL072). +5V forsyning -> ADC-sikker. DIP8-sokkel |
| U2 | LM358 | LM358 | shop | `Package_DIP:DIP-8_W7.62mm_LongPads` | B-halvdel = unity-buffer (ubrugt) |
| C1 | 100n | 100n keramisk | shop | `Capacitor_THT:C_Disc_D5.0mm_W2.5mm_P5.00mm` |  |
| C2 | 100n | 100n keramisk | shop | `Capacitor_THT:C_Disc_D5.0mm_W2.5mm_P5.00mm` |  |
| J1 | kanal 1 retur | 2 pol skrueterminal | shop | `TerminalBlock:TerminalBlock_bornier-2_P5.08mm` | grenens returledning ind paa pin 1 - system-GND videre fra pin 2 |
| J2 | kanal 2 retur | 2 pol skrueterminal | shop | `TerminalBlock:TerminalBlock_bornier-2_P5.08mm` |  |
| J3 | kanal 3 retur | 2 pol skrueterminal | shop | `TerminalBlock:TerminalBlock_bornier-2_P5.08mm` |  |
| J4 | Arduino | Header Male | shop | `Connector_PinHeader_2.54mm:PinHeader_1x05_P2.54mm_Vertical` | +5V / I1 / I2 / I3 / GND |

## buck_v2 (`buck_v2`)

| Ref | Værdi | Del (indkøb) | Kilde | Footprint | Noter |
|---|---|---|---|---|---|
| C1 | 22u | 22uF 50V | shop | `Capacitor_THT:CP_Radial_D8.0mm_P3.50mm` | LM7805 indgangskondensator (fra V1/Rectifier) |
| C2 | 22u | 22uF 50V | shop | `Capacitor_THT:CP_Radial_D8.0mm_P3.50mm` | 5V-skinnens udgangskondensator |
| C3 | 100n | 100n keramisk | shop | `Capacitor_THT:C_Disc_D5.0mm_W2.5mm_P5.00mm` | paa 555-udgangen (teamets valg) |
| C6 | 8n2 | 8n2 film (box) | shop | `Capacitor_THT:C_Rect_L13.0mm_W6.0mm_P10.00mm_FKS3_FKP3_MKS4` | 555 timing; box film ~9.3mm pitch (maalt) |
| C4 | 47u | 47uF 50V | shop | `Capacitor_THT:CP_Radial_D8.0mm_P3.50mm` | udgangskondensator (var 100n - rettet) |
| C5 | 100n | 100n keramisk | shop | `Capacitor_THT:C_Disc_D5.0mm_W2.5mm_P5.00mm` | 555 CONT |
| D1 | 1N4148 | 1N4148 | shop | `Diode_THT:D_DO-35_SOD27_P7.62mm_Horizontal` | duty-styringsdiode (555) |
| D2 | 1N4148 | 1N4148 | shop | `Diode_THT:D_DO-35_SOD27_P7.62mm_Horizontal` | duty-styringsdiode (555) |
| D3 | 1N5817 | 1N5817 | shop | `Diode_THT:D_DO-41_SOD81_P10.16mm_Horizontal` | friloebsdiode |
| J2 | MCP PWM | Header Male | shop | `Connector_PinHeader_2.54mm:PinHeader_1x02_P2.54mm_Vertical` | ekstern PWM ind (pin 2 = GND) |
| J3 | 5V ud | 2 pol skrueterminal | shop | `TerminalBlock:TerminalBlock_bornier-2_P5.08mm` |  |
| L1 | 121u | toroid (egen-vikling) | egen-vikling | `energy_system:L_Toroid_Vertical_L34.5mm_W15.0mm_P28.20mm_LaserPads` | 121uH = maalt paa den viklede toroid |
| Q1 | IRF530 | IRF530 | shop | `energy_system:TO-220-3_Vertical_LaserPads` |  |
| R3 | 200R | 200R | shop | `Resistor_THT:R_Axial_DIN0207_L6.3mm_D2.5mm_P7.62mm_Horizontal` | opto-LED formodstand |
| R1 | 10k | 10k0 | shop | `Resistor_THT:R_Axial_DIN0207_L6.3mm_D2.5mm_P7.62mm_Horizontal` | 555 timing |
| R2 | 10k | 10k0 | shop | `Resistor_THT:R_Axial_DIN0207_L6.3mm_D2.5mm_P7.62mm_Horizontal` | 555 timing |
| R4 | 1k | 1k00 | shop | `Resistor_THT:R_Axial_DIN0207_L6.3mm_D2.5mm_P7.62mm_Horizontal` | gate->source (V_GS=0 ved sluk) |
| RV1 | 20k | 20K trimmer | shop | `Potentiometer_THT:Potentiometer_Bourns_3296W_Vertical` | duty-justering. FOOTPRINT ANTAGET (3296W) - maal den fysiske trimmer |
| SW1 | DIP-switch | DIP-Switch | shop | `Button_Switch_THT:SW_DIP_SPSTx02_Slide_9.78x7.26mm_W7.62mm_P2.54mm` | valg: 555-PWM eller ekstern (J1) |
| U1 | LM7805 | LM7805 | shop | `energy_system:TO-220-3_Vertical_LaserPads` | SUBSTITUTION: LF50 ikke i shoppen - 7805 samme pinout (IN/GND/OUT) |
| U3 | 4N25 | 4N25 | shop | `Package_DIP:DIP-6_W7.62mm_LongPads` | DIP6-sokkel. Symbolben omnummereret til DIP-6 (E=4 C=5; pad 3/6 ubrugt) |
| U2 | NE555 | NE555 | shop | `Package_DIP:DIP-8_W7.62mm_LongPads` | DIP8-sokkel |
| U4 | IR2110 | IR2110 | kit | `Package_DIP:DIP-14_W7.62mm_LongPads` | KIT-DEL - ikke i shoppen. DIP14-sokkel. Gate-driver HIGH-SIDE (HO/pin7; VS->SW; bootstrap) |
| D4 | 1N4148 | 1N4148 | shop | `Diode_THT:D_DO-35_SOD27_P7.62mm_Horizontal` | bootstrap-diode +15V(VCC)->VB |
| C7 | 1u | 1uF keramik/film | shop | `Capacitor_THT:C_Disc_D5.0mm_W2.5mm_P5.00mm` | bootstrap-kondensator VB->VS(SW). Verificer fysisk pitch (film kan vaere 7.5mm) |
| R5 | 10 | 10R0 | shop | `Resistor_THT:R_Axial_DIN0207_L6.3mm_D2.5mm_P7.62mm_Horizontal` | gate-seriemodstand (HO->gate) |
| D5 | 1N4148 | 1N4148 | shop | `Diode_THT:D_DO-35_SOD27_P7.62mm_Horizontal` | anti-parallel over R5 (K=HO; A=GATE) -> hurtig sluk |
| R6 | 1k | 1k00 | shop | `Resistor_THT:R_Axial_DIN0207_L6.3mm_D2.5mm_P7.62mm_Horizontal` | HIN pulldown (opto-emitter -> GND) |
| C8 | 22u | 22uF 50V | shop | `Capacitor_THT:CP_Radial_D8.0mm_P3.50mm` | +15V bulk-afkobling (driver) |
| C9 | 100n | 100n keramisk | shop | `Capacitor_THT:C_Disc_D5.0mm_W2.5mm_P5.00mm` | +15V HF-afkobling (driver) |
| J5 | drive +15V | 2 pol skrueterminal | shop | `TerminalBlock:TerminalBlock_bornier-2_P5.08mm` | jordrefereret driver-forsyning (erstatter det flydende 9V-batteri) |

## boost_v2 (`boost_v2`)

| Ref | Værdi | Del (indkøb) | Kilde | Footprint | Noter |
|---|---|---|---|---|---|
| J1 | lager ind (5V) | 2 pol skrueterminal | shop | `TerminalBlock:TerminalBlock_bornier-2_P5.08mm` | 5V fra lager-kondensatoren |
| L1 | 470u | toroid (egen-vikling) | egen-vikling | `energy_system:L_Toroid_Vertical_L34.5mm_W15.0mm_P28.20mm_LaserPads` | maalt toroid (som boost v1) |
| M1 | IRF530 | IRF530 | shop | `energy_system:TO-220-3_Vertical_LaserPads` | lavside-switch (kilde = GND) |
| D1 | 1N5819 | 1N5817 | shop | `Diode_THT:D_DO-41_SOD81_P10.16mm_Horizontal` | SUBSTITUTION: 1N5819->1N5817 (Schottky 1A/20V); boost-udgang ~10V OK |
| C1 | 47u | 47uF 50V | shop | `Capacitor_THT:CP_Radial_D8.0mm_P3.50mm` | udgangskondensator V2 |
| J2 | V2 ud (10V) | 2 pol skrueterminal | shop | `TerminalBlock:TerminalBlock_bornier-2_P5.08mm` |  |
| J3 | PWM (isoleret) | Header Male | shop | `Connector_PinHeader_2.54mm:PinHeader_1x02_P2.54mm_Vertical` | PWM + GND_MCU (isoleret jord - maa IKKE forbindes til effekt-GND) |
| R1 | 200 | 200R | shop | `Resistor_THT:R_Axial_DIN0207_L6.3mm_D2.5mm_P7.62mm_Horizontal` | opto-LED formodstand |
| U1 | CNY17 | CNY17 | shop | `Package_DIP:DIP-6_W7.62mm_LongPads` | DIP6-sokkel. Bruger 4N25-symbol (samme 6-bens pinout). Shop: CNY17/MCT5211 |
| R2 | 1k | 1k00 | shop | `Resistor_THT:R_Axial_DIN0207_L6.3mm_D2.5mm_P7.62mm_Horizontal` | LIN pulldown (opto-emitter -> GND) |
| U2 | IR2110 | IR2110 | kit | `Package_DIP:DIP-14_W7.62mm_LongPads` | KIT-DEL - ikke i shoppen. DIP14-sokkel. Gate-driver lavside (LO/pin1) |
| R3 | 10 | 10R0 | shop | `Resistor_THT:R_Axial_DIN0207_L6.3mm_D2.5mm_P7.62mm_Horizontal` | gate-seriemodstand |
| D2 | 1N4007 | 1N4006 | shop | `Diode_THT:D_DO-41_SOD81_P10.16mm_Horizontal` | SUBSTITUTION: 1N4007->1N4006 (800V rigeligt). Anti-parallel over R3 -> hurtig sluk |
| R4 | 1k | 1k00 | shop | `Resistor_THT:R_Axial_DIN0207_L6.3mm_D2.5mm_P7.62mm_Horizontal` | gate pulldown |
| C2 | 22u | 22uF 50V | shop | `Capacitor_THT:CP_Radial_D8.0mm_P3.50mm` | +15V bulk-afkobling |
| C3 | 100n | 100n keramisk | shop | `Capacitor_THT:C_Disc_D5.0mm_W2.5mm_P5.00mm` | +15V HF-afkobling |
| J4 | drive +15V | 2 pol skrueterminal | shop | `TerminalBlock:TerminalBlock_bornier-2_P5.08mm` | gate-driver forsyning (jordrefereret - lavside OK) |

## mppt_buck (`mppt_buck`)

| Ref | Værdi | Del (indkøb) | Kilde | Footprint | Noter |
|---|---|---|---|---|---|
| J1 | PV ind | 2 pol skrueterminal | shop | `TerminalBlock:TerminalBlock_bornier-2_P5.08mm` | PV-panel ind (Voc 20.3V) |
| C1 | 470u/25V | 470uF 25V | shop | `Capacitor_THT:CP_Radial_D8.0mm_P3.50mm` | PV-bulk >=25V (Voc 20.3V). MAAL fysisk diameter/pitch foer bestilling |
| Q1 | IRF530 | IRF530 | shop | `energy_system:TO-220-3_Vertical_LaserPads` | high-side switch (100V/14A rigeligt ved 20V/2A) |
| D1 | 1N5822 | 1N5822 (BESTIL) | bestil | `Diode_THT:D_DO-201AD_P15.24mm_Horizontal` | >=3A Schottky friloeb ved ~2A. Shoppen har INGEN >=3A Schottky (kun 1N5817 1A). Bestil 1N5822/SB540 (40V/3A). DO-201AD passer |
| L1 | 150u | toroid (egen-vikling) | egen-vikling | `energy_system:L_Toroid_Vertical_L34.5mm_W15.0mm_P28.20mm_LaserPads` | L=Vout(Vin-Vout)/(dIL*f*Vin); 150u~31kHz. Vikles til faktisk PWM-frekvens. Kerne skal taale >=2.5A peak uden maetning |
| C2 | 47u | 47uF 50V | shop | `Capacitor_THT:CP_Radial_D8.0mm_P3.50mm` | lokal udgangskondensator (1F-lageret er bulk) |
| J2 | lager ud (5V) | 2 pol skrueterminal | shop | `TerminalBlock:TerminalBlock_bornier-2_P5.08mm` | til 1F energilager |
| J3 | PWM (Arduino) | Header Male | shop | `Connector_PinHeader_2.54mm:PinHeader_1x02_P2.54mm_Vertical` | PWM + GND_MCU (P&O duty fra Arduino - D5/Timer3 hvis Arduino-side) |
| R1 | 200 | 200R | shop | `Resistor_THT:R_Axial_DIN0207_L6.3mm_D2.5mm_P7.62mm_Horizontal` | opto-LED formodstand |
| U1 | CNY17 | CNY17 | shop | `Package_DIP:DIP-6_W7.62mm_LongPads` | DIP6-sokkel. 4N25-symbol (samme 6-bens pinout). Shop: CNY17/MCT5211 |
| R2 | 1k | 1k00 | shop | `Resistor_THT:R_Axial_DIN0207_L6.3mm_D2.5mm_P7.62mm_Horizontal` | HIN pulldown (opto-emitter -> GND) |
| U2 | IR2110 | IR2110 | kit | `Package_DIP:DIP-14_W7.62mm_LongPads` | KIT-DEL - ikke i shoppen. DIP14-sokkel. Gate-driver HIGH-SIDE (HO/pin7; VS->SW; bootstrap) |
| R3 | 10 | 10R0 | shop | `Resistor_THT:R_Axial_DIN0207_L6.3mm_D2.5mm_P7.62mm_Horizontal` | serie gate-modstand (HO->gate) |
| D3 | 1N4148 | 1N4148 | shop | `Diode_THT:D_DO-35_SOD27_P7.62mm_Horizontal` | anti-parallel over R3 (K=HO; A=GATE) -> hurtig sluk |
| R4 | 1k | 1k00 | shop | `Resistor_THT:R_Axial_DIN0207_L6.3mm_D2.5mm_P7.62mm_Horizontal` | gate pulldown -> SW (high-side ref) |
| D2 | 1N4148 | 1N4148 | shop | `Diode_THT:D_DO-35_SOD27_P7.62mm_Horizontal` | bootstrap-diode +15V(VCC)->VB (K=VB; A=+15V) |
| C3 | 1u | 1uF keramik/film | shop | `Capacitor_THT:C_Disc_D5.0mm_W2.5mm_P5.00mm` | bootstrap-kondensator VB->VS(SW). MAAL fysisk pitch (film kan vaere 7.5mm) |
| C4 | 22u | 22uF 50V | shop | `Capacitor_THT:CP_Radial_D8.0mm_P3.50mm` | +15V bulk-afkobling (driver) |
| C5 | 100n | 100n keramisk | shop | `Capacitor_THT:C_Disc_D5.0mm_W2.5mm_P5.00mm` | +15V HF-afkobling (driver) |
| J4 | drive +15V | 2 pol skrueterminal | shop | `TerminalBlock:TerminalBlock_bornier-2_P5.08mm` | jordrefereret driver-forsyning |
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

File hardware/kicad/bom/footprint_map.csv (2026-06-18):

board | schematic_ref | value | chosen_part_number | source | footprint | notes
buck | D1 | 1N5819 | 1N5817 | shop | Diode_THT:D_DO-41_SOD81_P10.16mm_Horizontal | SUBSTITUTION: 1N5819 ikke i shoppen. 1N5817 (Schottky 1A/20V) OK ved 15V bus med marginal - tjek spidsspaending
buck | M1 | IRF530N | IRF530 | shop | energy_system:TO-220-3_Vertical_LaserPads | shoppen har IRF530 (uden N) - samme pinout G-D-S og TO-220
buck | R1 | 330 | 332R (E96) | shop | Resistor_THT:R_Axial_DIN0207_L6.3mm_D2.5mm_P7.62mm_Horizontal | E96: 330 -> 332R (0.6% afvigelse) eller 2x packs - uproblematisk for LED-formodstand
buck | R2 | 10k | 10k0 | shop | Resistor_THT:R_Axial_DIN0207_L6.3mm_D2.5mm_P7.62mm_Horizontal
buck | C1 | 47u | 47uF 50V | shop | Capacitor_THT:CP_Radial_D8.0mm_P3.50mm
buck | U1 | 4N25 | 4N25 | shop | Package_DIP:DIP-6_W7.62mm_LongPads | monter i DIP6-sokkel (shop)
buck | L1 | 470u | toroid (egen-vikling) | egen-vikling | energy_system:L_Toroid_Vertical_L34.5mm_W15.0mm_P28.20mm_LaserPads | Maalt med skydelaere paa den fysiske toroid: OD 34.5mm staaende paa kant; ben-pitch 28.2mm c-c (26.6mm indvendigt + 1.6mm ben); drill 2.0mm. Genberegn ripple med viklet L (Lec 2: dI=Vs*k(1-k)/(2fL))
buck | J1 | V1 ind (15V) | 2 pol skrueterminal | shop | TerminalBlock:TerminalBlock_bornier-2_P5.08mm
buck | J2 | 5V ud | 2 pol skrueterminal | shop | TerminalBlock:TerminalBlock_bornier-2_P5.08mm
buck | J3 | PWM (isoleret) | Header Male | shop | Connector_PinHeader_2.54mm:PinHeader_1x02_P2.54mm_Vertical | PWM + GND_MCU (isoleret jord - maa IKKE forbindes til effekt-GND)
buck | J4 | gate-forsyning | Header Male | shop | Connector_PinHeader_2.54mm:PinHeader_1x02_P2.54mm_Vertical | OBS: +12V_SW refereret til SW-knuden (flydende hjaelpeforsyning) - high-side switch. Se PCB_RESULTS.md
boost | D1 | 1N5819 | 1N5817 | shop | Diode_THT:D_DO-41_SOD81_P10.16mm_Horizontal | SUBSTITUTION: som buck. Boost-udgang ~10V - 20V-rating OK
boost | M1 | IRF530 | IRF530 | shop | energy_system:TO-220-3_Vertical_LaserPads
boost | R1 | 330 | 332R (E96) | shop | Resistor_THT:R_Axial_DIN0207_L6.3mm_D2.5mm_P7.62mm_Horizontal
boost | R2 | 10k | 10k0 | shop | Resistor_THT:R_Axial_DIN0207_L6.3mm_D2.5mm_P7.62mm_Horizontal
boost | C1 | 47u | 47uF 50V | shop | Capacitor_THT:CP_Radial_D8.0mm_P3.50mm
boost | U1 | 4N25 | 4N25 | shop | Package_DIP:DIP-6_W7.62mm_LongPads | DIP6-sokkel
boost | L1 | 470u | toroid (egen-vikling) | egen-vikling | energy_system:L_Toroid_Vertical_L34.5mm_W15.0mm_P28.20mm_LaserPads | som buck L1: maalt toroid OD 34.5mm / pitch 28.2mm / drill 2.0mm
boost | J1 | lager ind (5V) | 2 pol skrueterminal | shop | TerminalBlock:TerminalBlock_bornier-2_P5.08mm
boost | J2 | V2 ud (10V) | 2 pol skrueterminal | shop | TerminalBlock:TerminalBlock_bornier-2_P5.08mm
boost | J3 | PWM (isoleret) | Header Male | shop | Connector_PinHeader_2.54mm:PinHeader_1x02_P2.54mm_Vertical
boost | J4 | gate-forsyning | Header Male | shop | Connector_PinHeader_2.54mm:PinHeader_1x02_P2.54mm_Vertical | +12V/GND (low-side switch - jordrefereret OK)
drive | R1 | 200 | 200R | shop | Resistor_THT:R_Axial_DIN0207_L6.3mm_D2.5mm_P7.62mm_Horizontal
drive | R2 | 10 | 10R0 | shop | Resistor_THT:R_Axial_DIN0207_L6.3mm_D2.5mm_P7.62mm_Horizontal | gate-seriemodstand
drive | R3 | 1k | 1k00 | shop | Resistor_THT:R_Axial_DIN0207_L6.3mm_D2.5mm_P7.62mm_Horizontal
drive | R4 | 1k | 1k00 | shop | Resistor_THT:R_Axial_DIN0207_L6.3mm_D2.5mm_P7.62mm_Horizontal
drive | C1 | 22u | 22uF 50V | shop | Capacitor_THT:CP_Radial_D8.0mm_P3.50mm
drive | C2 | 100n | 100n keramisk | shop | Capacitor_THT:C_Disc_D5.0mm_W2.5mm_P5.00mm
drive | D1 | 1N4007 | 1N4006 | shop | Diode_THT:D_DO-41_SOD81_P10.16mm_Horizontal | SUBSTITUTION: 1N4007 (1000V) ikke i shoppen; 1N4006 (800V) rigelig ved 20V. Friloeb over motor
drive | D2 | 1N4007 | 1N4006 | shop | Diode_THT:D_DO-41_SOD81_P10.16mm_Horizontal | SUBSTITUTION: som D1. Gate-vejs-diode
drive | Q1 | IRF540N | IRF540 | shop | energy_system:TO-220-3_Vertical_LaserPads | kittet har ogsaa IRF540N (datasheet i docs/datasheets) - TO-220AB bekraeftet
drive | U1 | ILD74 | ILD74 | kit | Package_DIP:DIP-8_W7.62mm_LongPads | KIT-DEL - IKKE i shoppen. Dual-kanal opto DIP-8 (datasheet bekraeftet). 4N25 er IKKE drop-in (single + anden pinout). DIP8-sokkel
drive | U2 | IR2110 | IR2110 | kit | Package_DIP:DIP-14_W7.62mm_LongPads | KIT-DEL - IKKE i shoppen. 14-Lead PDIP bekraeftet i datasheet. DIP14-sokkel
drive | M1 | Motor_DC | Motraxx SR555 | kit | TerminalBlock:TerminalBlock_bornier-2_P5.08mm | motor tilsluttes via skrueterminal (ledninger)
drive | J1 | PWM ind | Header Male | shop | Connector_PinHeader_2.54mm:PinHeader_1x02_P2.54mm_Vertical
drive | J2 | forsyning | 3 pol skrueterminal | shop | TerminalBlock:TerminalBlock_bornier-3_P5.08mm | +20V / +15V / GND
feedback | R1 | 10k | 10k0 | shop | Resistor_THT:R_Axial_DIN0207_L6.3mm_D2.5mm_P7.62mm_Horizontal
feedback | R2 | 2k | 2k00 | shop | Resistor_THT:R_Axial_DIN0207_L6.3mm_D2.5mm_P7.62mm_Horizontal
feedback | R3 | 33k | 33k2 (E96) | shop | Resistor_THT:R_Axial_DIN0207_L6.3mm_D2.5mm_P7.62mm_Horizontal | E96: 33k -> 33k2 (0.6%)
feedback | R4 | 200 | 200R | shop | Resistor_THT:R_Axial_DIN0207_L6.3mm_D2.5mm_P7.62mm_Horizontal
feedback | R5 | 33k | 33k2 (E96) | shop | Resistor_THT:R_Axial_DIN0207_L6.3mm_D2.5mm_P7.62mm_Horizontal
feedback | U1 | IL300 | IL300 | kit | Package_DIP:DIP-8_W7.62mm_LongPads | KIT-DEL - IKKE i shoppen og INGEN aekvivalent. Servo-loopet kraever netop IL300. DIP-8 bekraeftet i datasheet. DIP8-sokkel
feedback | U3 | MCP601 | MCP601 | kit | Package_DIP:DIP-8_W7.62mm_LongPads | KIT-DEL. PDIP-8 bekraeftet (DS21314G). Shop-alternativ: MCP6002 (dual - kraever omtegning) eller LM358. DIP8-sokkel
feedback | U4 | MCP601 | MCP601 | kit | Package_DIP:DIP-8_W7.62mm_LongPads | som U3
feedback | J1 | ind + forsyning | Header Male | shop | Connector_PinHeader_2.54mm:PinHeader_1x03_P2.54mm_Vertical | INPUT / +5V / GND
feedback | J2 | FB ud | Header Male | shop | Connector_PinHeader_2.54mm:PinHeader_1x02_P2.54mm_Vertical
rectifier | D1 | 1N4006 | 1N4006 | shop | Diode_THT:D_DO-41_SOD81_P10.16mm_Horizontal | 6-diode 3-faset bro; 1A/800V rigeligt til 300mA / 8x trafo-spaending
rectifier | D2 | 1N4006 | 1N4006 | shop | Diode_THT:D_DO-41_SOD81_P10.16mm_Horizontal
rectifier | D3 | 1N4006 | 1N4006 | shop | Diode_THT:D_DO-41_SOD81_P10.16mm_Horizontal
rectifier | D4 | 1N4006 | 1N4006 | shop | Diode_THT:D_DO-41_SOD81_P10.16mm_Horizontal
rectifier | D5 | 1N4006 | 1N4006 | shop | Diode_THT:D_DO-41_SOD81_P10.16mm_Horizontal
rectifier | D6 | 1N4006 | 1N4006 | shop | Diode_THT:D_DO-41_SOD81_P10.16mm_Horizontal
rectifier | C1 | 4700u/50V | 4700uF 50V | shop | Capacitor_THT:CP_Radial_D18.0mm_P7.50mm | 3x parallel = 14.1mF (~spec'ens 15mF). VERIFICER fysisk diameter/pitch foer bestilling - shoppen angiver ikke dimensioner
rectifier | C2 | 4700u/50V | 4700uF 50V | shop | Capacitor_THT:CP_Radial_D18.0mm_P7.50mm
rectifier | C3 | 4700u/50V | 4700uF 50V | shop | Capacitor_THT:CP_Radial_D18.0mm_P7.50mm
rectifier | R1 | 10k | 10k0 | shop | Resistor_THT:R_Axial_DIN0207_L6.3mm_D2.5mm_P7.62mm_Horizontal | bleeder
rectifier | J1 | 3-fase ind | 3 pol skrueterminal | shop | TerminalBlock:TerminalBlock_bornier-3_P5.08mm | fra trafo-sekundaerer
rectifier | J2 | V1 ud | 2 pol skrueterminal | shop | TerminalBlock:TerminalBlock_bornier-2_P5.08mm
mppt | D1 | 1N5817 | 1N5817 | shop | Diode_THT:D_DO-41_SOD81_P10.16mm_Horizontal | seriediode mod tilbage-stroem i panelet
mppt | DZ1 | BZX55C5V1 | BZX55C5V1 | shop | Diode_THT:D_DO-35_SOD27_P7.62mm_Horizontal | 5.1V reference
mppt | Q1 | TIP41A | TIP41A | shop | energy_system:TO-220-3_Vertical_LaserPads | pass-transistor TO-220 (BD139/TO-126 droppet: 2.28mm pitch kan ikke overholde laserens 0.8mm clearance). SKAL have koeleplade (op til ~7W ved fuld PV-stroem)
mppt | U1 | LM358 | LM358 | shop | Package_DIP:DIP-8_W7.62mm_LongPads | forsynes fra PV-bus (<32V OK). DIP8-sokkel
mppt | C1 | 4700u/50V | 4700uF 50V | shop | Capacitor_THT:CP_Radial_D18.0mm_P7.50mm | MPPT-kondensator 3x parallel = 14.1mF
mppt | C2 | 4700u/50V | 4700uF 50V | shop | Capacitor_THT:CP_Radial_D18.0mm_P7.50mm
mppt | C3 | 4700u/50V | 4700uF 50V | shop | Capacitor_THT:CP_Radial_D18.0mm_P7.50mm
mppt | C4 | 100n | 100n keramisk | shop | Capacitor_THT:C_Disc_D5.0mm_W2.5mm_P5.00mm | LM358 afkobling
mppt | C5 | 47u | 47uF 50V | shop | Capacitor_THT:CP_Radial_D8.0mm_P3.50mm | udgangskondensator V3
mppt | C6 | 100n | 100n keramisk | shop | Capacitor_THT:C_Disc_D5.0mm_W2.5mm_P5.00mm | zener-stoejfilter
mppt | R1 | 100k | 100k | shop | Resistor_THT:R_Axial_DIN0207_L6.3mm_D2.5mm_P7.62mm_Horizontal | PV-spaendingsdeler top
mppt | R2 | 22k6 | 22k6 | shop | Resistor_THT:R_Axial_DIN0207_L6.3mm_D2.5mm_P7.62mm_Horizontal | deler bund: 21V -> 3.9V til ADC
mppt | R3 | 4k75 | 4k75 | shop | Resistor_THT:R_Axial_DIN0207_L6.3mm_D2.5mm_P7.62mm_Horizontal | zener-bias ~2.7mA
mppt | R4 | 1k00 | 1k00 | shop | Resistor_THT:R_Axial_DIN0207_L6.3mm_D2.5mm_P7.62mm_Horizontal | basemodstand
mppt | R5 | 1R00 | 1R00 | shop | Resistor_THT:R_Axial_DIN0207_L6.3mm_D2.5mm_P7.62mm_Horizontal | shunt 2x1R parallel = 0R5 (effekt: 0.6A -> 2x 0.18W i 1/4W-modstande)
mppt | R6 | 1R00 | 1R00 | shop | Resistor_THT:R_Axial_DIN0207_L6.3mm_D2.5mm_P7.62mm_Horizontal
mppt | R7 | 1k00 | 1k00 | shop | Resistor_THT:R_Axial_DIN0207_L6.3mm_D2.5mm_P7.62mm_Horizontal | inverterende indgang
mppt | R8 | 9k09 | 9k09 | shop | Resistor_THT:R_Axial_DIN0207_L6.3mm_D2.5mm_P7.62mm_Horizontal | gain -9.09: 0.6A -> +2.7V
mppt | J1 | PV ind | 2 pol skrueterminal | shop | TerminalBlock:TerminalBlock_bornier-2_P5.08mm
mppt | J2 | til lager (V3) | 2 pol skrueterminal | shop | TerminalBlock:TerminalBlock_bornier-2_P5.08mm
mppt | J3 | sense -> Arduino | Header Male | shop | Connector_PinHeader_2.54mm:PinHeader_1x03_P2.54mm_Vertical | PV_V / PV_I / GND
current_sense | R11 | 1R00 | 1R00 | shop | Resistor_THT:R_Axial_DIN0207_L6.3mm_D2.5mm_P7.62mm_Horizontal | lavside-shunt kanal 1 (V1->buck; 300mA -> 90mW OK i 1/4W)
current_sense | R12 | 1k00 | 1k00 | shop | Resistor_THT:R_Axial_DIN0207_L6.3mm_D2.5mm_P7.62mm_Horizontal | gain-ben
current_sense | R13 | 9k09 | 9k09 | shop | Resistor_THT:R_Axial_DIN0207_L6.3mm_D2.5mm_P7.62mm_Horizontal | gain 10.09: 300mA -> 3.03V
current_sense | R21 | 1R00 | 1R00 | shop | Resistor_THT:R_Axial_DIN0207_L6.3mm_D2.5mm_P7.62mm_Horizontal | kanal 2 (boost->last)
current_sense | R22 | 1k00 | 1k00 | shop | Resistor_THT:R_Axial_DIN0207_L6.3mm_D2.5mm_P7.62mm_Horizontal
current_sense | R23 | 9k09 | 9k09 | shop | Resistor_THT:R_Axial_DIN0207_L6.3mm_D2.5mm_P7.62mm_Horizontal
current_sense | R31 | 1R00 | 1R00 | shop | Resistor_THT:R_Axial_DIN0207_L6.3mm_D2.5mm_P7.62mm_Horizontal | kanal 3 (lager V3)
current_sense | R32 | 1k00 | 1k00 | shop | Resistor_THT:R_Axial_DIN0207_L6.3mm_D2.5mm_P7.62mm_Horizontal
current_sense | R33 | 9k09 | 9k09 | shop | Resistor_THT:R_Axial_DIN0207_L6.3mm_D2.5mm_P7.62mm_Horizontal
current_sense | U1 | LM358 | LM358 | shop | Package_DIP:DIP-8_W7.62mm_LongPads | indgange gaar til GND (derfor ikke TL072). +5V forsyning -> ADC-sikker. DIP8-sokkel
current_sense | U2 | LM358 | LM358 | shop | Package_DIP:DIP-8_W7.62mm_LongPads | B-halvdel = unity-buffer (ubrugt)
current_sense | C1 | 100n | 100n keramisk | shop | Capacitor_THT:C_Disc_D5.0mm_W2.5mm_P5.00mm
current_sense | C2 | 100n | 100n keramisk | shop | Capacitor_THT:C_Disc_D5.0mm_W2.5mm_P5.00mm
current_sense | J1 | kanal 1 retur | 2 pol skrueterminal | shop | TerminalBlock:TerminalBlock_bornier-2_P5.08mm | grenens returledning ind paa pin 1 - system-GND videre fra pin 2
current_sense | J2 | kanal 2 retur | 2 pol skrueterminal | shop | TerminalBlock:TerminalBlock_bornier-2_P5.08mm
current_sense | J3 | kanal 3 retur | 2 pol skrueterminal | shop | TerminalBlock:TerminalBlock_bornier-2_P5.08mm
current_sense | J4 | Arduino | Header Male | shop | Connector_PinHeader_2.54mm:PinHeader_1x05_P2.54mm_Vertical | +5V / I1 / I2 / I3 / GND
buck_v2 | C1 | 22u | 22uF 50V | shop | Capacitor_THT:CP_Radial_D8.0mm_P3.50mm | LM7805 indgangskondensator (fra V1/Rectifier)
buck_v2 | C2 | 22u | 22uF 50V | shop | Capacitor_THT:CP_Radial_D8.0mm_P3.50mm | 5V-skinnens udgangskondensator
buck_v2 | C3 | 100n | 100n keramisk | shop | Capacitor_THT:C_Disc_D5.0mm_W2.5mm_P5.00mm | paa 555-udgangen (teamets valg)
buck_v2 | C6 | 8n2 | 8n2 film (box) | shop | Capacitor_THT:C_Rect_L13.0mm_W6.0mm_P10.00mm_FKS3_FKP3_MKS4 | 555 timing; box film ~9.3mm pitch (maalt)
buck_v2 | C4 | 47u | 47uF 50V | shop | Capacitor_THT:CP_Radial_D8.0mm_P3.50mm | udgangskondensator (var 100n - rettet)
buck_v2 | C5 | 100n | 100n keramisk | shop | Capacitor_THT:C_Disc_D5.0mm_W2.5mm_P5.00mm | 555 CONT
buck_v2 | D1 | 1N4148 | 1N4148 | shop | Diode_THT:D_DO-35_SOD27_P7.62mm_Horizontal | duty-styringsdiode (555)
buck_v2 | D2 | 1N4148 | 1N4148 | shop | Diode_THT:D_DO-35_SOD27_P7.62mm_Horizontal | duty-styringsdiode (555)
buck_v2 | D3 | 1N5817 | 1N5817 | shop | Diode_THT:D_DO-41_SOD81_P10.16mm_Horizontal | friloebsdiode
buck_v2 | J2 | MCP PWM | Header Male | shop | Connector_PinHeader_2.54mm:PinHeader_1x02_P2.54mm_Vertical | ekstern PWM ind (pin 2 = GND)
buck_v2 | J3 | 5V ud | 2 pol skrueterminal | shop | TerminalBlock:TerminalBlock_bornier-2_P5.08mm
buck_v2 | L1 | 121u | toroid (egen-vikling) | egen-vikling | energy_system:L_Toroid_Vertical_L34.5mm_W15.0mm_P28.20mm_LaserPads | 121uH = maalt paa den viklede toroid
buck_v2 | Q1 | IRF530 | IRF530 | shop | energy_system:TO-220-3_Vertical_LaserPads
buck_v2 | R3 | 200R | 200R | shop | Resistor_THT:R_Axial_DIN0207_L6.3mm_D2.5mm_P7.62mm_Horizontal | opto-LED formodstand
buck_v2 | R1 | 10k | 10k0 | shop | Resistor_THT:R_Axial_DIN0207_L6.3mm_D2.5mm_P7.62mm_Horizontal | 555 timing
buck_v2 | R2 | 10k | 10k0 | shop | Resistor_THT:R_Axial_DIN0207_L6.3mm_D2.5mm_P7.62mm_Horizontal | 555 timing
buck_v2 | R4 | 1k | 1k00 | shop | Resistor_THT:R_Axial_DIN0207_L6.3mm_D2.5mm_P7.62mm_Horizontal | gate->source (V_GS=0 ved sluk)
buck_v2 | RV1 | 20k | 20K trimmer | shop | Potentiometer_THT:Potentiometer_Bourns_3296W_Vertical | duty-justering. FOOTPRINT ANTAGET (3296W) - maal den fysiske trimmer
buck_v2 | SW1 | DIP-switch | DIP-Switch | shop | Button_Switch_THT:SW_DIP_SPSTx02_Slide_9.78x7.26mm_W7.62mm_P2.54mm | valg: 555-PWM eller ekstern (J1)
buck_v2 | U1 | LM7805 | LM7805 | shop | energy_system:TO-220-3_Vertical_LaserPads | SUBSTITUTION: LF50 ikke i shoppen - 7805 samme pinout (IN/GND/OUT)
buck_v2 | U3 | 4N25 | 4N25 | shop | Package_DIP:DIP-6_W7.62mm_LongPads | DIP6-sokkel. Symbolben omnummereret til DIP-6 (E=4 C=5; pad 3/6 ubrugt)
buck_v2 | U2 | NE555 | NE555 | shop | Package_DIP:DIP-8_W7.62mm_LongPads | DIP8-sokkel
buck_v2 | U4 | IR2110 | IR2110 | kit | Package_DIP:DIP-14_W7.62mm_LongPads | KIT-DEL - ikke i shoppen. DIP14-sokkel. Gate-driver HIGH-SIDE (HO/pin7; VS->SW; bootstrap)
buck_v2 | D4 | 1N4148 | 1N4148 | shop | Diode_THT:D_DO-35_SOD27_P7.62mm_Horizontal | bootstrap-diode +15V(VCC)->VB
buck_v2 | C7 | 1u | 1uF keramik/film | shop | Capacitor_THT:C_Disc_D5.0mm_W2.5mm_P5.00mm | bootstrap-kondensator VB->VS(SW). Verificer fysisk pitch (film kan vaere 7.5mm)
buck_v2 | R5 | 10 | 10R0 | shop | Resistor_THT:R_Axial_DIN0207_L6.3mm_D2.5mm_P7.62mm_Horizontal | gate-seriemodstand (HO->gate)
buck_v2 | D5 | 1N4148 | 1N4148 | shop | Diode_THT:D_DO-35_SOD27_P7.62mm_Horizontal | anti-parallel over R5 (K=HO; A=GATE) -> hurtig sluk
buck_v2 | R6 | 1k | 1k00 | shop | Resistor_THT:R_Axial_DIN0207_L6.3mm_D2.5mm_P7.62mm_Horizontal | HIN pulldown (opto-emitter -> GND)
buck_v2 | C8 | 22u | 22uF 50V | shop | Capacitor_THT:CP_Radial_D8.0mm_P3.50mm | +15V bulk-afkobling (driver)
buck_v2 | C9 | 100n | 100n keramisk | shop | Capacitor_THT:C_Disc_D5.0mm_W2.5mm_P5.00mm | +15V HF-afkobling (driver)
buck_v2 | J5 | drive +15V | 2 pol skrueterminal | shop | TerminalBlock:TerminalBlock_bornier-2_P5.08mm | jordrefereret driver-forsyning (erstatter det flydende 9V-batteri)
boost_v2 | J1 | lager ind (5V) | 2 pol skrueterminal | shop | TerminalBlock:TerminalBlock_bornier-2_P5.08mm | 5V fra lager-kondensatoren
boost_v2 | L1 | 470u | toroid (egen-vikling) | egen-vikling | energy_system:L_Toroid_Vertical_L34.5mm_W15.0mm_P28.20mm_LaserPads | maalt toroid (som boost v1)
boost_v2 | M1 | IRF530 | IRF530 | shop | energy_system:TO-220-3_Vertical_LaserPads | lavside-switch (kilde = GND)
boost_v2 | D1 | 1N5819 | 1N5817 | shop | Diode_THT:D_DO-41_SOD81_P10.16mm_Horizontal | SUBSTITUTION: 1N5819->1N5817 (Schottky 1A/20V); boost-udgang ~10V OK
boost_v2 | C1 | 47u | 47uF 50V | shop | Capacitor_THT:CP_Radial_D8.0mm_P3.50mm | udgangskondensator V2
boost_v2 | J2 | V2 ud (10V) | 2 pol skrueterminal | shop | TerminalBlock:TerminalBlock_bornier-2_P5.08mm
boost_v2 | J3 | PWM (isoleret) | Header Male | shop | Connector_PinHeader_2.54mm:PinHeader_1x02_P2.54mm_Vertical | PWM + GND_MCU (isoleret jord - maa IKKE forbindes til effekt-GND)
boost_v2 | R1 | 200 | 200R | shop | Resistor_THT:R_Axial_DIN0207_L6.3mm_D2.5mm_P7.62mm_Horizontal | opto-LED formodstand
boost_v2 | U1 | CNY17 | CNY17 | shop | Package_DIP:DIP-6_W7.62mm_LongPads | DIP6-sokkel. Bruger 4N25-symbol (samme 6-bens pinout). Shop: CNY17/MCT5211
boost_v2 | R2 | 1k | 1k00 | shop | Resistor_THT:R_Axial_DIN0207_L6.3mm_D2.5mm_P7.62mm_Horizontal | LIN pulldown (opto-emitter -> GND)
boost_v2 | U2 | IR2110 | IR2110 | kit | Package_DIP:DIP-14_W7.62mm_LongPads | KIT-DEL - ikke i shoppen. DIP14-sokkel. Gate-driver lavside (LO/pin1)
boost_v2 | R3 | 10 | 10R0 | shop | Resistor_THT:R_Axial_DIN0207_L6.3mm_D2.5mm_P7.62mm_Horizontal | gate-seriemodstand
boost_v2 | D2 | 1N4007 | 1N4006 | shop | Diode_THT:D_DO-41_SOD81_P10.16mm_Horizontal | SUBSTITUTION: 1N4007->1N4006 (800V rigeligt). Anti-parallel over R3 -> hurtig sluk
boost_v2 | R4 | 1k | 1k00 | shop | Resistor_THT:R_Axial_DIN0207_L6.3mm_D2.5mm_P7.62mm_Horizontal | gate pulldown
boost_v2 | C2 | 22u | 22uF 50V | shop | Capacitor_THT:CP_Radial_D8.0mm_P3.50mm | +15V bulk-afkobling
boost_v2 | C3 | 100n | 100n keramisk | shop | Capacitor_THT:C_Disc_D5.0mm_W2.5mm_P5.00mm | +15V HF-afkobling
boost_v2 | J4 | drive +15V | 2 pol skrueterminal | shop | TerminalBlock:TerminalBlock_bornier-2_P5.08mm | gate-driver forsyning (jordrefereret - lavside OK)
mppt_buck | J1 | PV ind | 2 pol skrueterminal | shop | TerminalBlock:TerminalBlock_bornier-2_P5.08mm | PV-panel ind (Voc 20.3V)
mppt_buck | C1 | 470u/25V | 470uF 25V | shop | Capacitor_THT:CP_Radial_D8.0mm_P3.50mm | PV-bulk >=25V (Voc 20.3V). MAAL fysisk diameter/pitch foer bestilling
mppt_buck | Q1 | IRF530 | IRF530 | shop | energy_system:TO-220-3_Vertical_LaserPads | high-side switch (100V/14A rigeligt ved 20V/2A)
mppt_buck | D1 | 1N5822 | 1N5822 (BESTIL) | bestil | Diode_THT:D_DO-201AD_P15.24mm_Horizontal | >=3A Schottky friloeb ved ~2A. Shoppen har INGEN >=3A Schottky (kun 1N5817 1A). Bestil 1N5822/SB540 (40V/3A). DO-201AD passer
mppt_buck | L1 | 150u | toroid (egen-vikling) | egen-vikling | energy_system:L_Toroid_Vertical_L34.5mm_W15.0mm_P28.20mm_LaserPads | L=Vout(Vin-Vout)/(dIL*f*Vin); 150u~31kHz. Vikles til faktisk PWM-frekvens. Kerne skal taale >=2.5A peak uden maetning
mppt_buck | C2 | 47u | 47uF 50V | shop | Capacitor_THT:CP_Radial_D8.0mm_P3.50mm | lokal udgangskondensator (1F-lageret er bulk)
mppt_buck | J2 | lager ud (5V) | 2 pol skrueterminal | shop | TerminalBlock:TerminalBlock_bornier-2_P5.08mm | til 1F energilager
mppt_buck | J3 | PWM (Arduino) | Header Male | shop | Connector_PinHeader_2.54mm:PinHeader_1x02_P2.54mm_Vertical | PWM + GND_MCU (P&O duty fra Arduino - D5/Timer3 hvis Arduino-side)
mppt_buck | R1 | 200 | 200R | shop | Resistor_THT:R_Axial_DIN0207_L6.3mm_D2.5mm_P7.62mm_Horizontal | opto-LED formodstand
mppt_buck | U1 | CNY17 | CNY17 | shop | Package_DIP:DIP-6_W7.62mm_LongPads | DIP6-sokkel. 4N25-symbol (samme 6-bens pinout). Shop: CNY17/MCT5211
mppt_buck | R2 | 1k | 1k00 | shop | Resistor_THT:R_Axial_DIN0207_L6.3mm_D2.5mm_P7.62mm_Horizontal | HIN pulldown (opto-emitter -> GND)
mppt_buck | U2 | IR2110 | IR2110 | kit | Package_DIP:DIP-14_W7.62mm_LongPads | KIT-DEL - ikke i shoppen. DIP14-sokkel. Gate-driver HIGH-SIDE (HO/pin7; VS->SW; bootstrap)
mppt_buck | R3 | 10 | 10R0 | shop | Resistor_THT:R_Axial_DIN0207_L6.3mm_D2.5mm_P7.62mm_Horizontal | serie gate-modstand (HO->gate)
mppt_buck | D3 | 1N4148 | 1N4148 | shop | Diode_THT:D_DO-35_SOD27_P7.62mm_Horizontal | anti-parallel over R3 (K=HO; A=GATE) -> hurtig sluk
mppt_buck | R4 | 1k | 1k00 | shop | Resistor_THT:R_Axial_DIN0207_L6.3mm_D2.5mm_P7.62mm_Horizontal | gate pulldown -> SW (high-side ref)
mppt_buck | D2 | 1N4148 | 1N4148 | shop | Diode_THT:D_DO-35_SOD27_P7.62mm_Horizontal | bootstrap-diode +15V(VCC)->VB (K=VB; A=+15V)
mppt_buck | C3 | 1u | 1uF keramik/film | shop | Capacitor_THT:C_Disc_D5.0mm_W2.5mm_P5.00mm | bootstrap-kondensator VB->VS(SW). MAAL fysisk pitch (film kan vaere 7.5mm)
mppt_buck | C4 | 22u | 22uF 50V | shop | Capacitor_THT:CP_Radial_D8.0mm_P3.50mm | +15V bulk-afkobling (driver)
mppt_buck | C5 | 100n | 100n keramisk | shop | Capacitor_THT:C_Disc_D5.0mm_W2.5mm_P5.00mm | +15V HF-afkobling (driver)
mppt_buck | J4 | drive +15V | 2 pol skrueterminal | shop | TerminalBlock:TerminalBlock_bornier-2_P5.08mm | jordrefereret driver-forsyning
c2000_feedback | J1 | V1 in | 2 pol skrueterminal | shop | TerminalBlock:TerminalBlock_bornier-2_P5.08mm | V1-rail (rectifier-bus 15V) ind paa pin1 - GND pin2
c2000_feedback | RV11 | 10k0 | 10k0 | shop | Resistor_THT:R_Axial_DIN0207_L6.3mm_D2.5mm_P7.62mm_Horizontal | V1-deler hoej-ben (/11 med RV12): 15V->1.36V ved ADC
c2000_feedback | RV12 | 1k00 | 1k00 | shop | Resistor_THT:R_Axial_DIN0207_L6.3mm_D2.5mm_P7.62mm_Horizontal | V1-deler lav-ben
c2000_feedback | RV13 | 1k00 | 1k00 | shop | Resistor_THT:R_Axial_DIN0207_L6.3mm_D2.5mm_P7.62mm_Horizontal | serie-R til ADC (med zener+10n = klemme/filter)
c2000_feedback | DV1 | BZX55C3V0 | BZX55C3V0 | shop | Diode_THT:D_DO-35_SOD27_P7.62mm_Horizontal | 3.0V zener-klemme paa ADC-ben (C2000 abs-max 3.3V). Brug evt 3.3V (BZX55C3V3)
c2000_feedback | CV1 | 10n | 10n keramisk | shop | Capacitor_THT:C_Disc_D5.0mm_W2.5mm_P5.00mm | S/H-stabilisering paa ADC-ben
c2000_feedback | J3 | V2 in | 2 pol skrueterminal | shop | TerminalBlock:TerminalBlock_bornier-2_P5.08mm | V2-rail (last ~10V) ind
c2000_feedback | RV21 | 12k0 | 12k0 | shop | Resistor_THT:R_Axial_DIN0207_L6.3mm_D2.5mm_P7.62mm_Horizontal | V2-deler hoej-ben (/7): 10V->1.43V
c2000_feedback | RV22 | 2k00 | 2k00 | shop | Resistor_THT:R_Axial_DIN0207_L6.3mm_D2.5mm_P7.62mm_Horizontal | V2-deler lav-ben
c2000_feedback | RV23 | 1k00 | 1k00 | shop | Resistor_THT:R_Axial_DIN0207_L6.3mm_D2.5mm_P7.62mm_Horizontal | serie-R til ADC
c2000_feedback | DV2 | BZX55C3V0 | BZX55C3V0 | shop | Diode_THT:D_DO-35_SOD27_P7.62mm_Horizontal | 3.0V zener-klemme
c2000_feedback | CV2 | 10n | 10n keramisk | shop | Capacitor_THT:C_Disc_D5.0mm_W2.5mm_P5.00mm
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

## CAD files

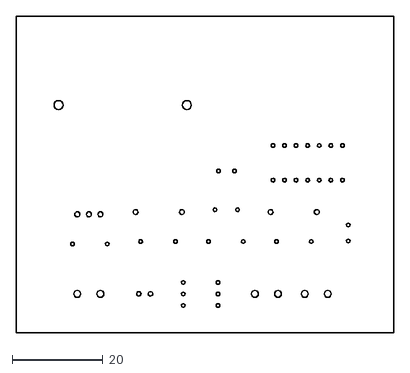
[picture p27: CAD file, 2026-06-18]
hardware/kicad/production/boost_v2/boost_v2_holes.dxf
83.0 x 69.5

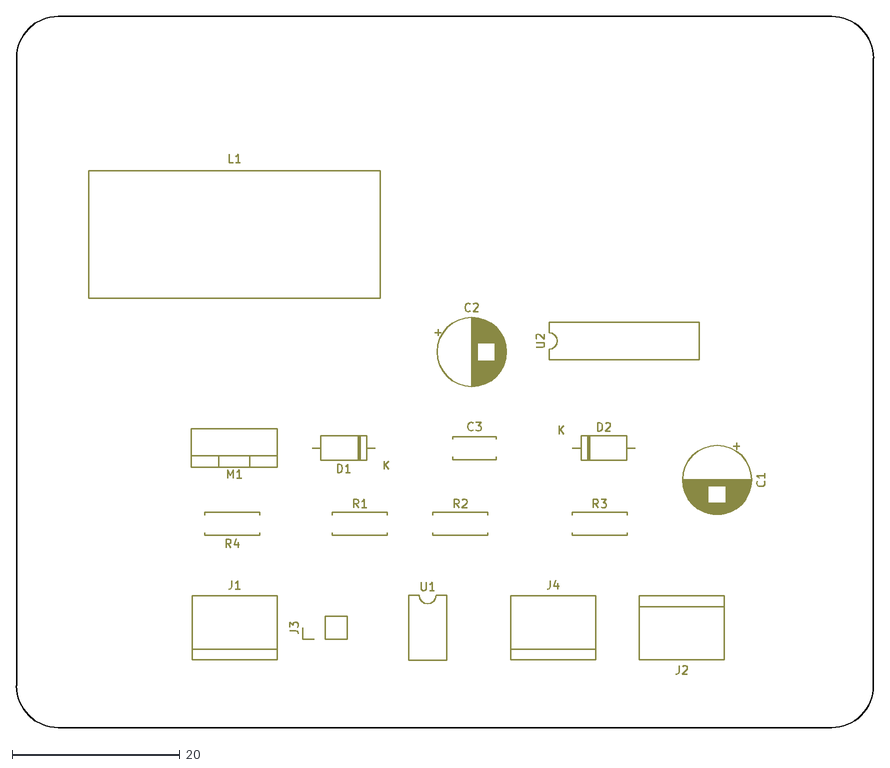
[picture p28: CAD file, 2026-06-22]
hardware/kicad/production/boost_v2_mill/boost_v2_mill_silk_top.dxf
102.1 x 84.8

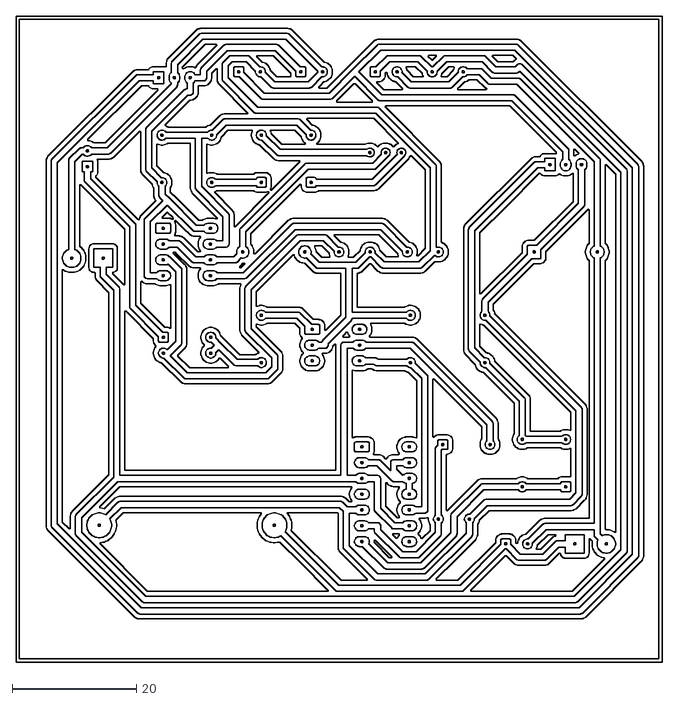
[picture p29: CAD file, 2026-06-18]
hardware/kicad/production/buck_v2/buck_v2.dxf
104.0 x 104.0

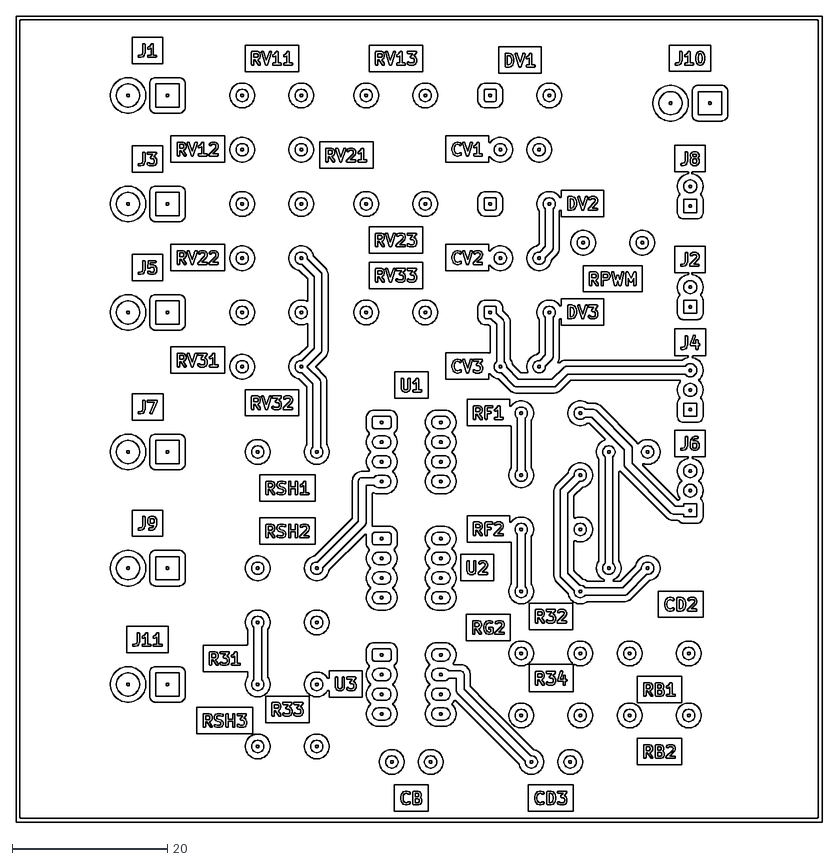
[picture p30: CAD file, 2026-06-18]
hardware/kicad/production/c2000_feedback/c2000_feedback_top_cu.dxf
104.0 x 104.0

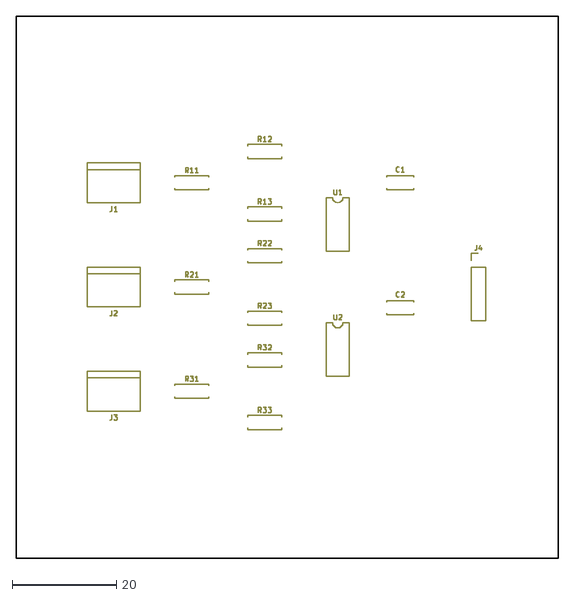
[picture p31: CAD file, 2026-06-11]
hardware/kicad/production/current_sense/current_sense_silk_top.dxf
104.0 x 104.0

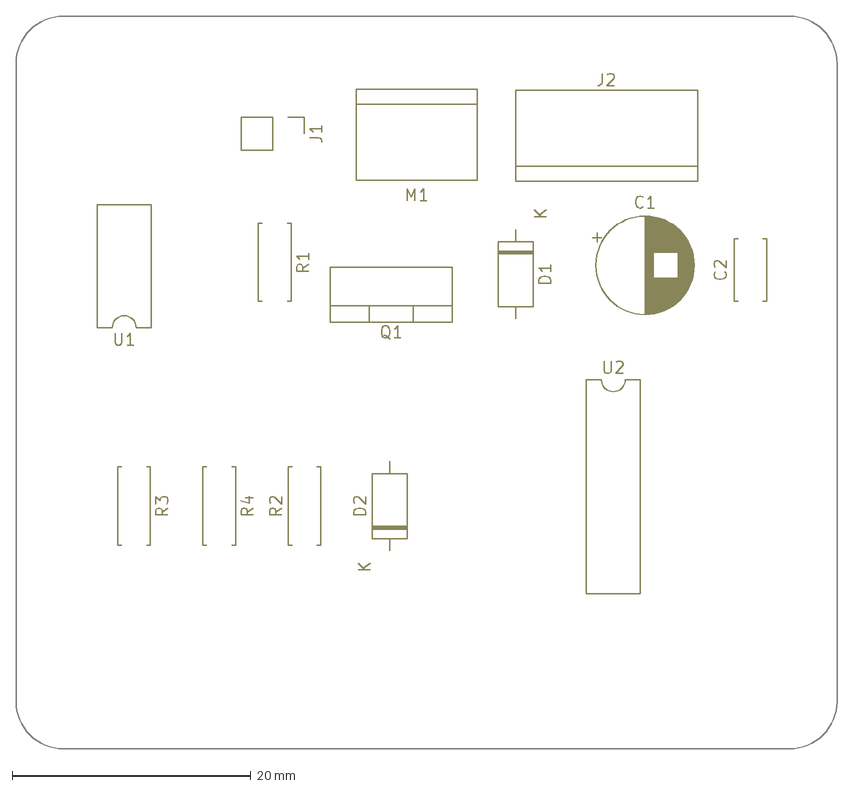
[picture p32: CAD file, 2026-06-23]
hardware/kicad/production/drive_circuit/drive_circuit_silk_top.dxf
68.7 x 61.3 mm

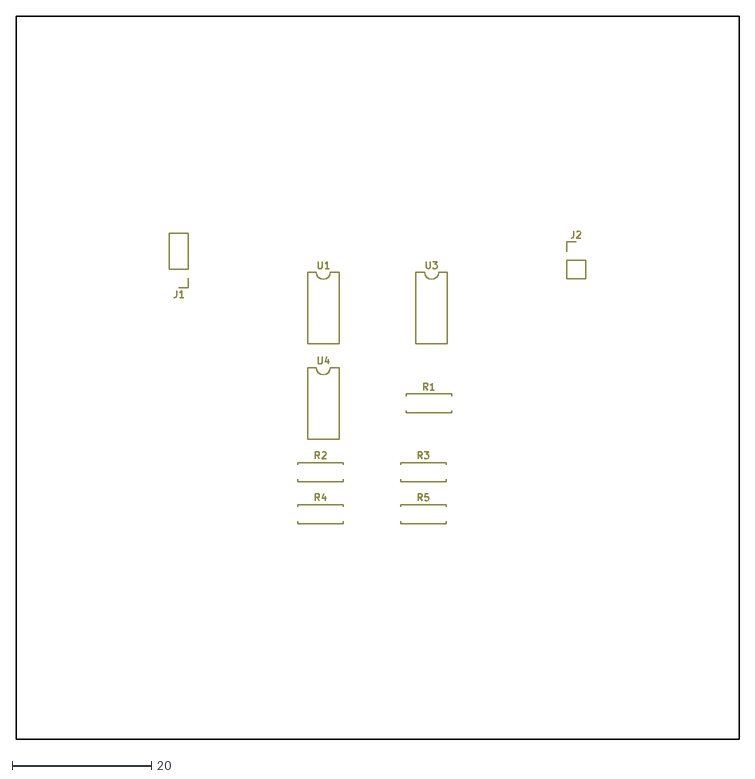
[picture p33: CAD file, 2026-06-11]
hardware/kicad/production/feedback_circuit/feedback_circuit_silk_top.dxf
104.0 x 104.0

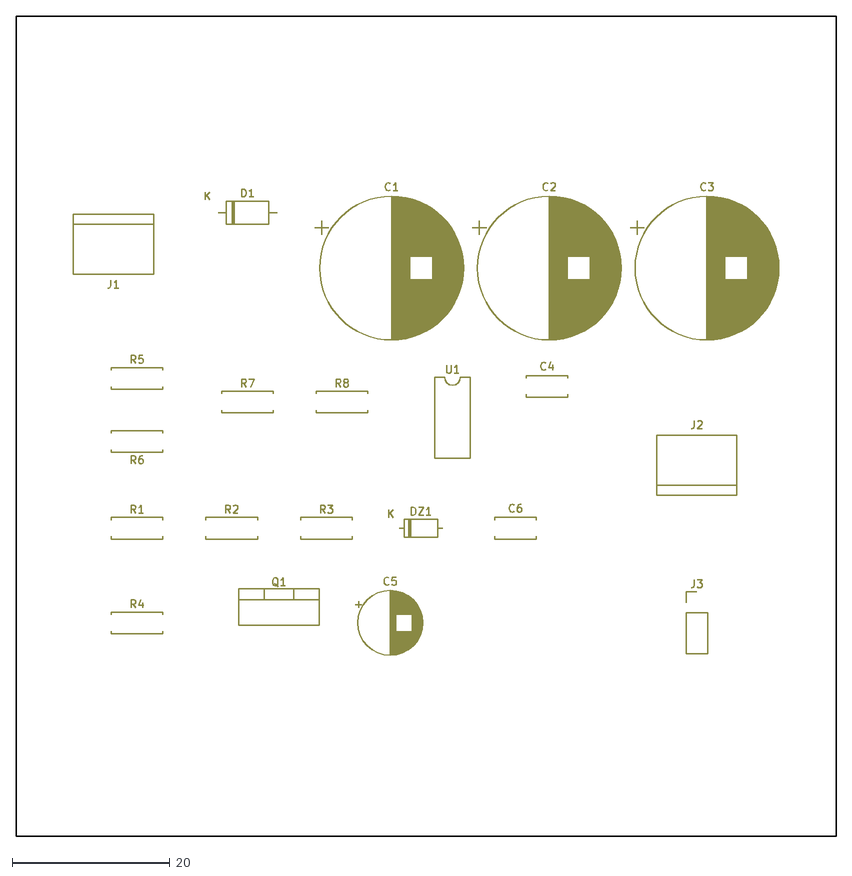
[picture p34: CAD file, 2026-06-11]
hardware/kicad/production/mppt/mppt_silk_top.dxf
104.0 x 104.0

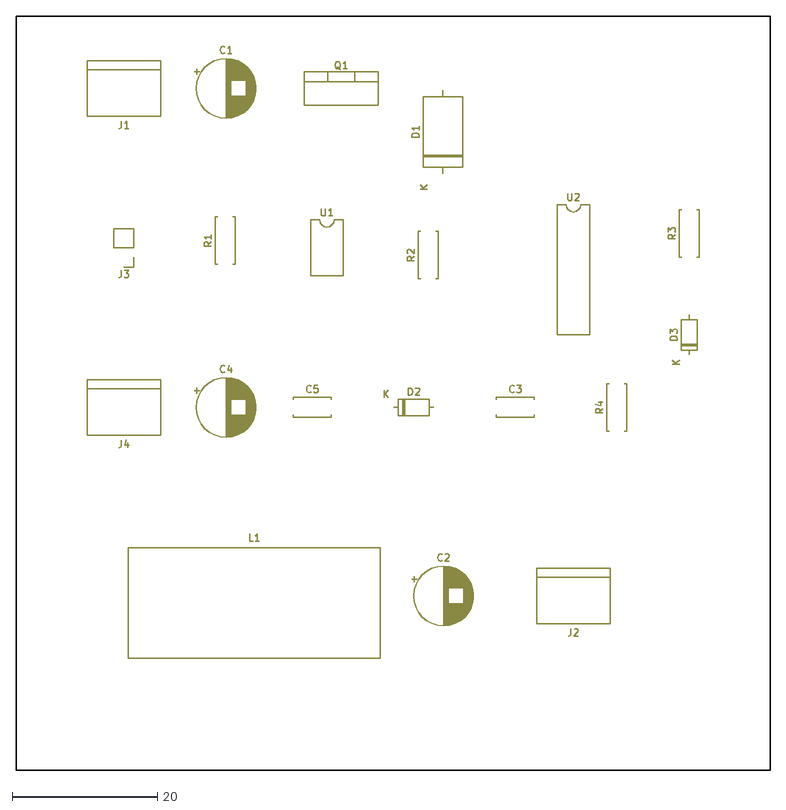
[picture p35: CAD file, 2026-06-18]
hardware/kicad/production/mppt_buck/mppt_buck_silk_top.dxf
104.0 x 104.0

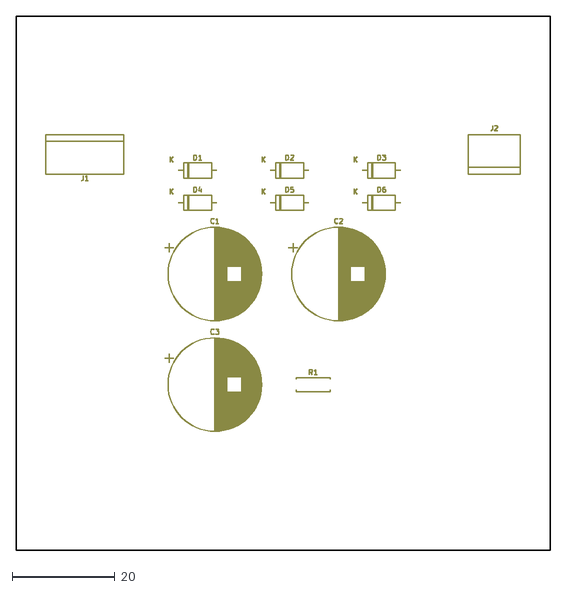
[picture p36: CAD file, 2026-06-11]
hardware/kicad/production/rectifier/rectifier_silk_top.dxf
104.0 x 104.0

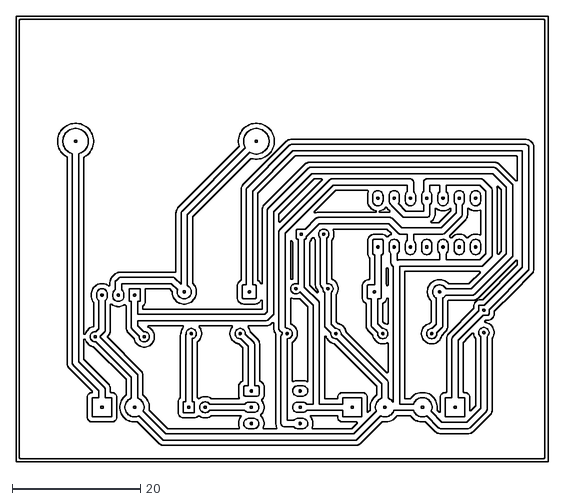
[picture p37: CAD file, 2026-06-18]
hardware/kicad/production/boost_v2/boost_v2.dxf
83.0 x 69.5

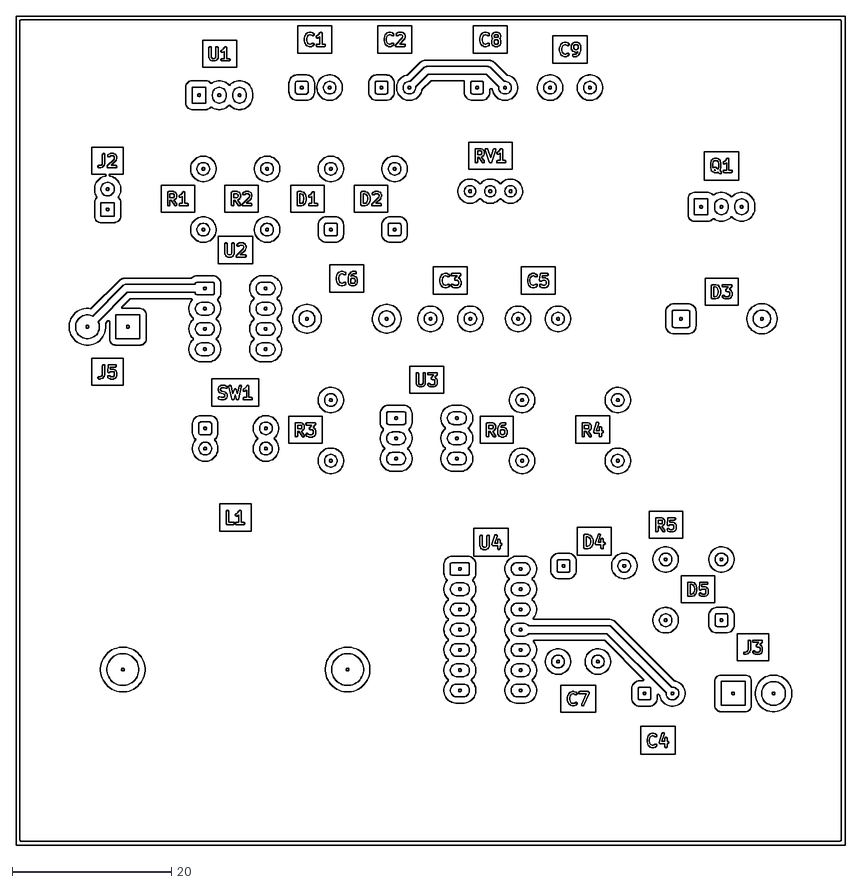
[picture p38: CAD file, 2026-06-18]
hardware/kicad/production/buck_v2/buck_v2_top_cu.dxf
104.0 x 104.0

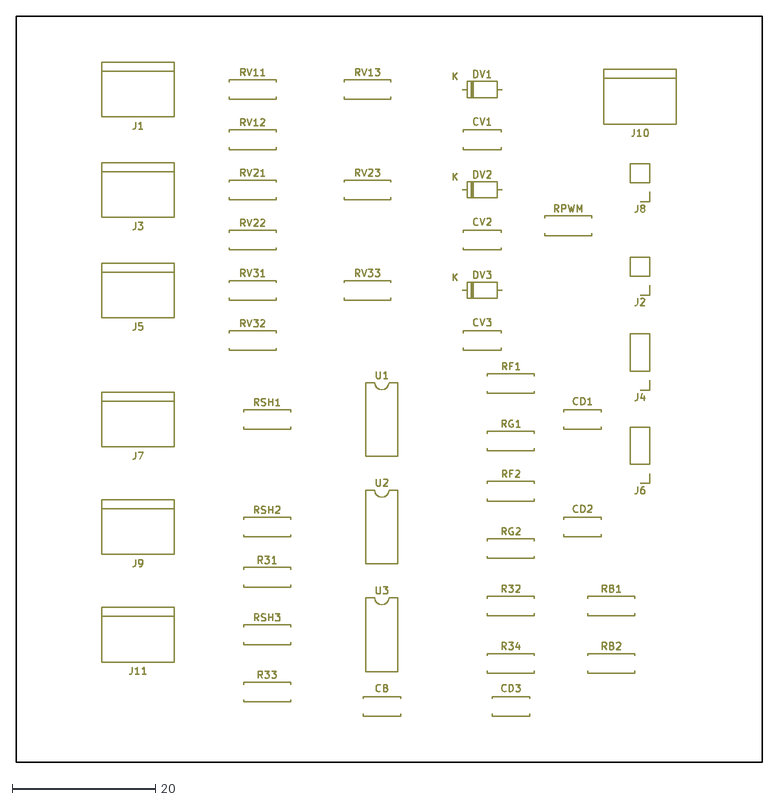
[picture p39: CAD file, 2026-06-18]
hardware/kicad/production/c2000_feedback/c2000_feedback_silk_top.dxf
104.0 x 104.0

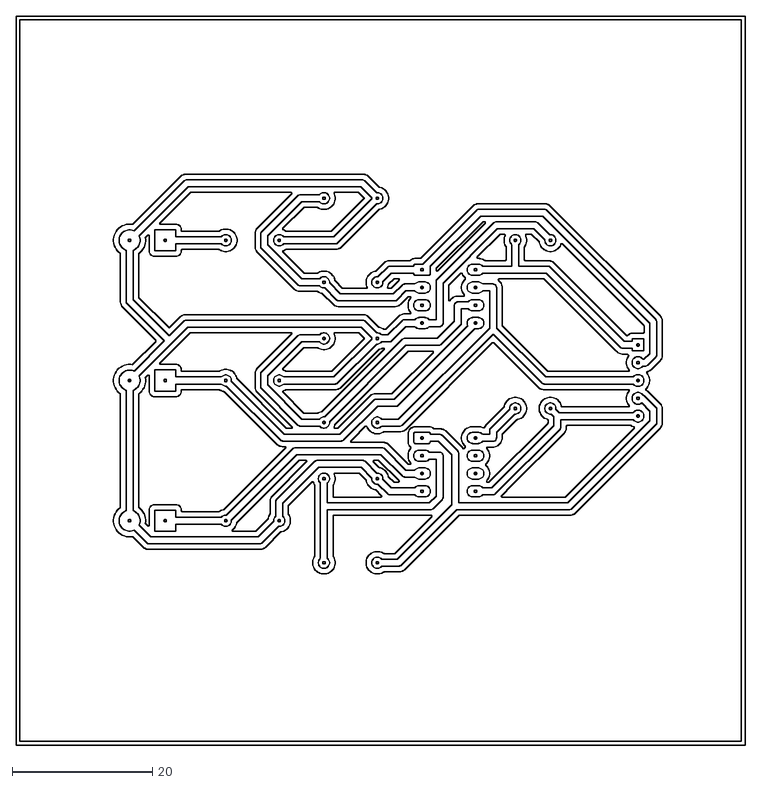
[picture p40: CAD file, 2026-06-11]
hardware/kicad/production/current_sense/current_sense.dxf
104.0 x 104.0

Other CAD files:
hardware/kicad/production/drive_circuit/drive_circuit.dxf
hardware/kicad/production/feedback_circuit/feedback_circuit.dxf
hardware/kicad/production/mppt/mppt.dxf
hardware/kicad/production/mppt_buck/mppt_buck.dxf
hardware/kicad/production/buck/buck.dxf
hardware/kicad/production/buck/buck_silk_top.dxf
hardware/kicad/production/buck/buck_top_cu.dxf
hardware/kicad/production/buck_v2/buck_v2_holes.dxf
hardware/kicad/production/buck_v2/buck_v2_silk_top.dxf
hardware/kicad/production/c2000_feedback/c2000_feedback.dxf
hardware/kicad/production/current_sense/current_sense_top_cu.dxf
hardware/kicad/production/drive_circuit/drive_circuit_top_cu.dxf
hardware/kicad/production/feedback_circuit/feedback_circuit_top_cu.dxf
hardware/kicad/production/mppt/mppt_top_cu.dxf
hardware/kicad/production/mppt_buck/mppt_buck_top_cu.dxf
hardware/kicad/production/rectifier/rectifier.dxf
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

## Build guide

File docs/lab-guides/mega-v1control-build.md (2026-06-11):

# Lab guide — building `MegaV1Control.slx`

Extends the verified PI loop (`MegaPI.slx`) into its firmware shape:
**control @ 1 kHz + heartbeat LED + 1 Hz serial monitoring** — still running
against the RC bench plant.

> [!NOTE]
> **Measurement roles:** 🔬 = **you** measure (WaveForms / eyes) · 🤖 = **Claude**
> measures (close WaveForms, say *"check"* — only one app can own the AD3 at a time).
> The AD3 probe is **10×** — keep the channel attenuation at 10× in WaveForms.

## The target — what you're building

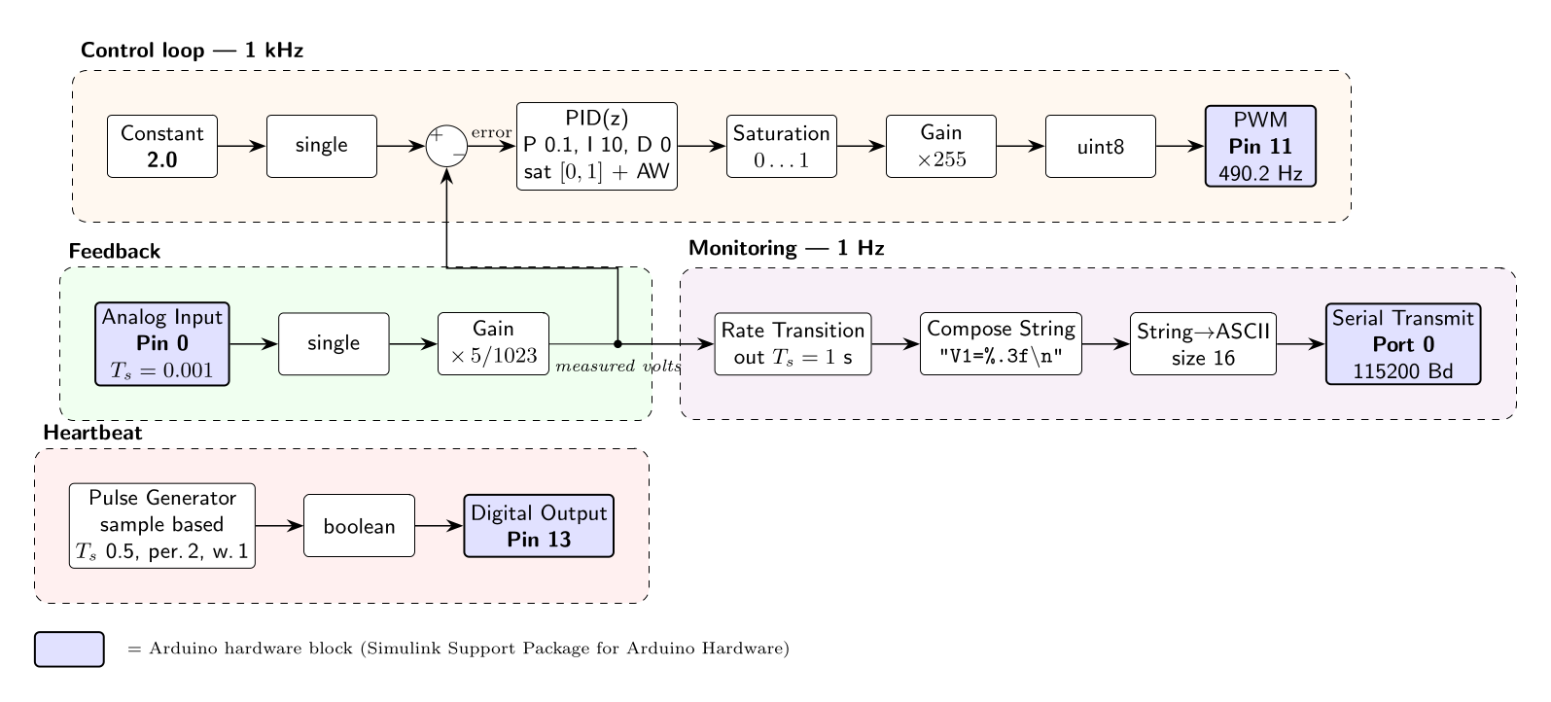
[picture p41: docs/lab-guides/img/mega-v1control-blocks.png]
MegaV1Control block diagram


Four islands on one canvas: the control loop (the verified `MegaPI` chain), the
feedback path it shares with the new monitoring branch, and the heartbeat.
Blue blocks come from *Simulink Support Package for Arduino Hardware → Common*.

## The bench plant (already wired)

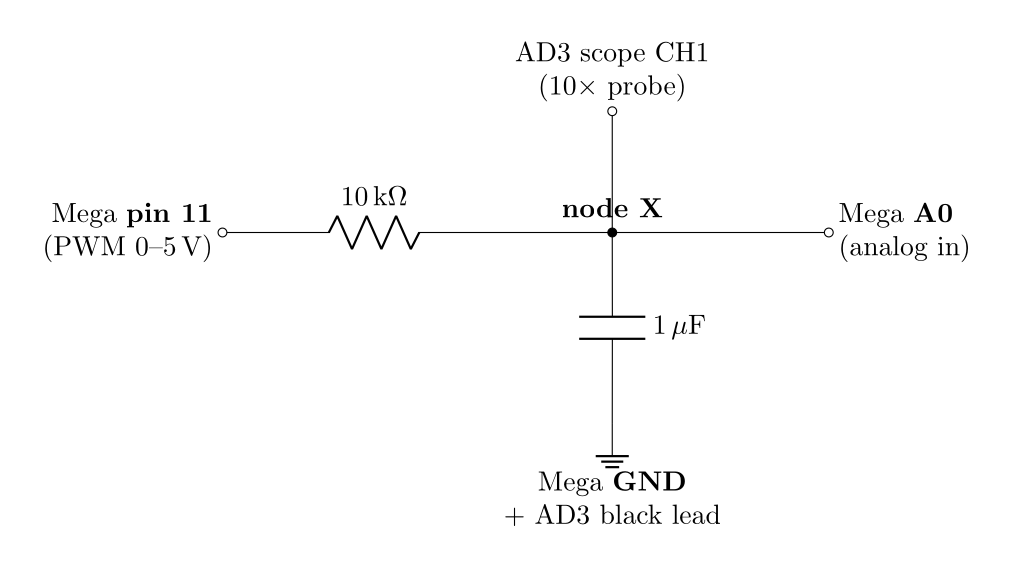
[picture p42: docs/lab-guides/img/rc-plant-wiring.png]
RC plant wiring


> [!WARNING]
> If you rebuild the breadboard: re-verify **open-loop first** (fixed duty 128 →
> node X ≈ 2.5 V) before trusting any closed-loop result. An open resistor link cost
> us an evening on the C2000 — the ADC happily reads a *very* convincing phantom
> voltage on a floating pin.

---

## ✅ Checkpoint 0 — starting state

- [ ] Board on COM9, RC plant wired, probe on **node X**, AD3 GND on Mega GND
- [ ] 🔬 *or* 🤖: node X reads the last deployed setpoint (2.0 or 3.5 V) — loop alive

---

## Step 0 — Save As

- [ ] Open `MegaPI.slx` → **Save As** → `MegaV1Control.slx` (same `MEGA/` folder)

> [!TIP]
> `MegaPI.slx` stays untouched as the known-good fallback. If tonight goes sideways,
> you can always redeploy it and be back at a working loop in 30 seconds.

## Step 1 — Heartbeat (bottom of the canvas — it's infrastructure)

- [ ] **Pulse Generator**: *Sample based*, Sample time `0.5`, Period `2`, Pulse width `1`
- [ ] → **Data Type Conversion** to `boolean` → **Digital Output** (Arduino lib), Pin **13**

> [!TIP]
> From now on: dark LED = scheduler dead. The cheapest diagnostic of the whole project.

## Step 2 — Serial speed

- [ ] Ctrl+E → Hardware Implementation → Target hardware resources →
  **Serial port properties → Serial 0 baud rate = 115200**

## Step 3 — Monitoring branch (the 1 kHz → 1 Hz boundary + strings)

Branch off the **measured volts** signal (output of the 5/1023 gain, see diagram):

- [ ] **Rate Transition** (Signal Attributes): ✔ deterministic, **Output sample time = 1**
- [ ] → **Compose String** (Simulink → String): format `"V1=%.3f\n"`, 1 input
- [ ] → **String to ASCII**: output vector size **16**
- [ ] → **Serial Transmit** (Arduino lib): **Port 0**

> [!IMPORTANT]
> The control loop must never wait for printing — that is exactly what the Rate
> Transition guarantees. Without it, Simulink would either error on mixed rates or,
> worse, drag string formatting into the 1 ms control task on an 8-bit CPU.

> [!NOTE]
> String-to-ASCII pads its fixed 16-byte output with `NUL`s, so the stream carries a
> few zero bytes between lines. Terminals hide them; parsers strip them. Cosmetic.

## Step 4 — Pre-deploy sanity

- [ ] Ref constant = **2.0**
- [ ] PID: P `0.1`, I `10`, D `0` — Saturation tab: **output [0,1] AND integrator [0,1]**, clamping
- [ ] **Ctrl+D** (Update Diagram) runs clean — fix sample-time complaints with `-1` on the
  offending block; the Rate Transition rules the monitoring branch
- [ ] **Build, Deploy & Start**

> [!CAUTION]
> Watch the diagnostics pane for **red** before celebrating. A failed build leaves the
> *previous* firmware running — you'll be debugging a ghost. (Learned twice today.)

---

## ✅ Checkpoint 1 — life signs (free, instant)

- [ ] 🔬 Heartbeat LED on pin 13 blinks at 1 Hz
- [ ] 🔬 RX/TX LEDs flicker briefly every second (the serial transmit firing)

## ✅ Checkpoint 2 — control + monitoring together

- [ ] **Close WaveForms**, don't open any serial monitor (COM9 belongs to Claude now)
- [ ] 🤖 say **"check"** → Claude verifies *simultaneously*:
  - node X = **2.000 V** on the AD3 (discard-first-capture rule applies)
  - COM9 streams `V1=2.00x` once per second at 115200

Both green = the Mega's entire project job description, working in miniature.

## ✅ Checkpoint 3 — step response (the report figure)

- [ ] Change ref to **3.5**, redeploy
- [ ] 🔬 WaveForms: trigger **Normal / rising / level 1 V**, ~50 ms/div — the deploy reset
  makes the node climb 0 → 3.5 V right after flashing; **screenshot the transient** →
  `measurements/`
- [ ] Expect a smooth ~100 ms rise, no overshoot (P=0.1 / I=10 → ~8 Hz crossover, ~90° PM)

## ✅ Checkpoint 4 (bonus) — disturbance rejection

- [ ] 🔬 While regulating: clip a second **10 kΩ from node X to GND** — the node dips and
  the integrator drags it back. Capture it; classic PI demo for the report.

---

## Wrap-up

- [ ] Commit `MegaV1Control.slx` + screenshots (Claude does the log + commit)
- [ ] Next model: MPPT P&O skeleton (A6/A7 → D5) once the supervisor answers the
  *discrete vs Arduino MPPT* question — see [mega-pinmap.md](../mega-pinmap.md) open questions

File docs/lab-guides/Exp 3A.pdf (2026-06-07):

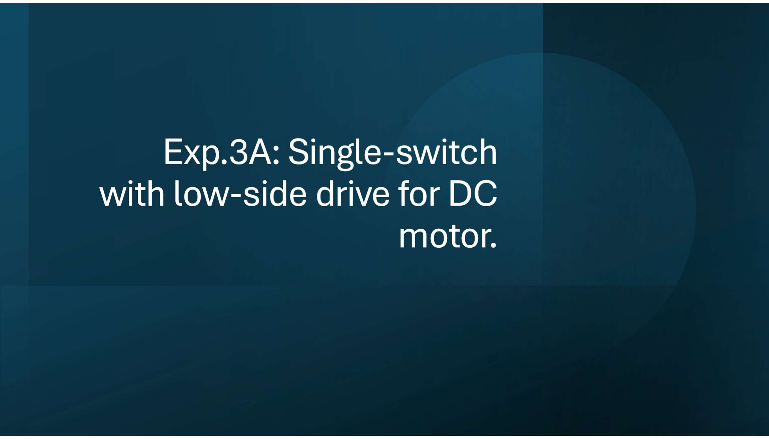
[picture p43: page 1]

# Exp.3A: Single-switch with low-side drive for DC

motor.

# Tasks

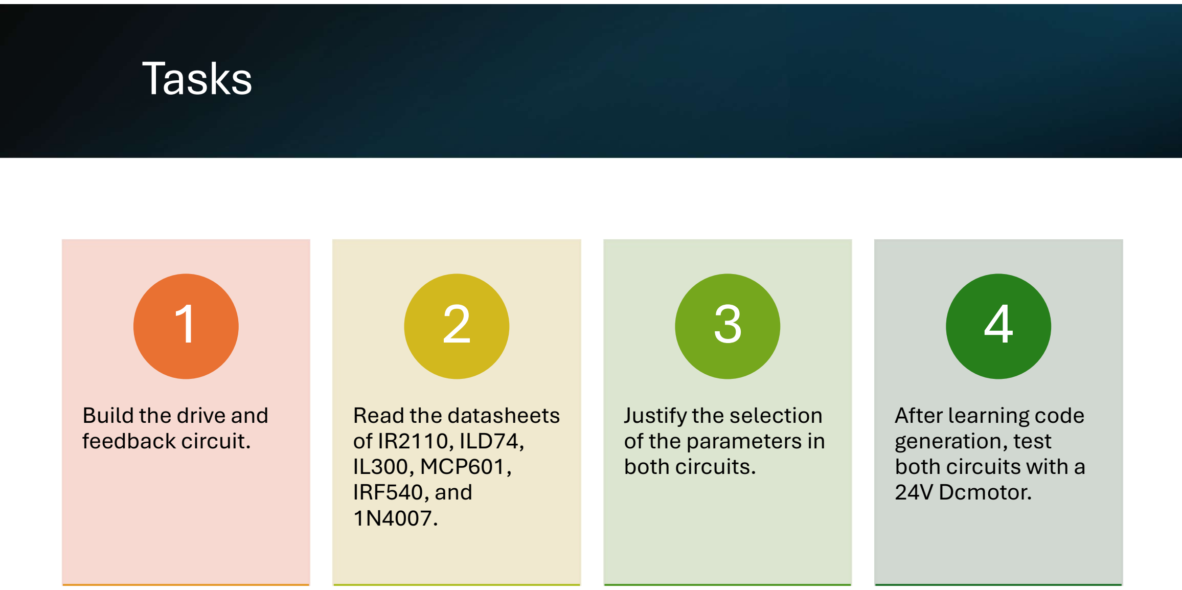
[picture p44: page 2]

Build the drive and
feedback circuit.

1

Read the datasheets
of IR2110, ILD74,
IL300, MCP601,
IRF540, and
1N4007.

2

Justify the selection
of the parameters in
both circuits.

3

After learning code
generation, test
both circuits with a
24V Dcmotor.

4

# Drive Circuit

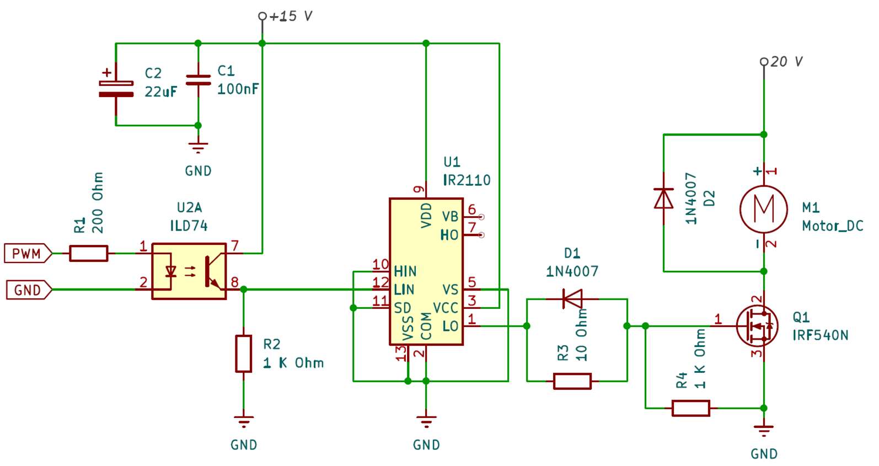
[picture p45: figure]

# Feedback Circuit

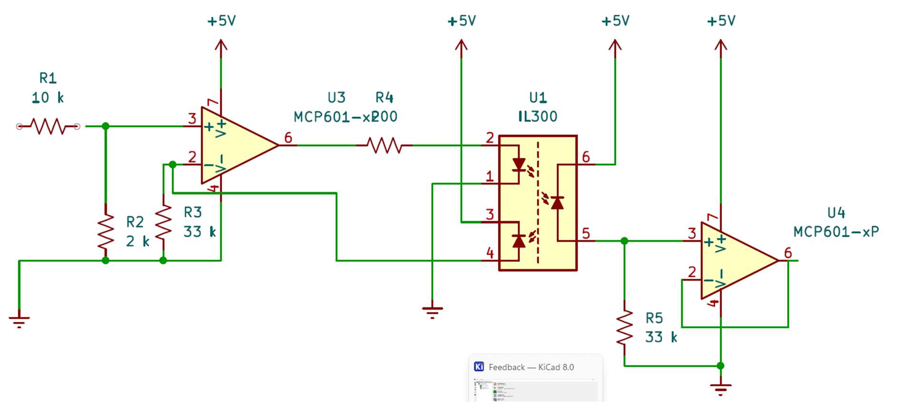
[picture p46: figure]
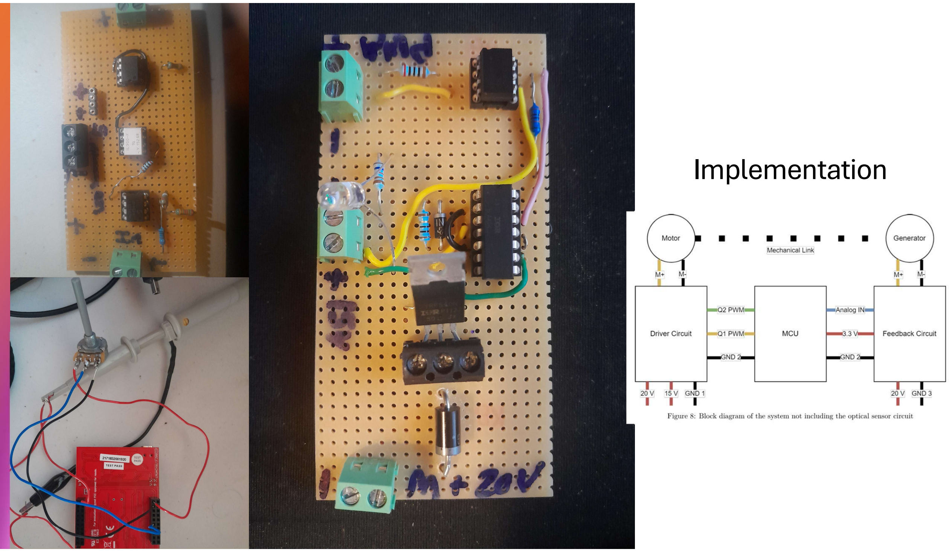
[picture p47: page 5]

## Implementation

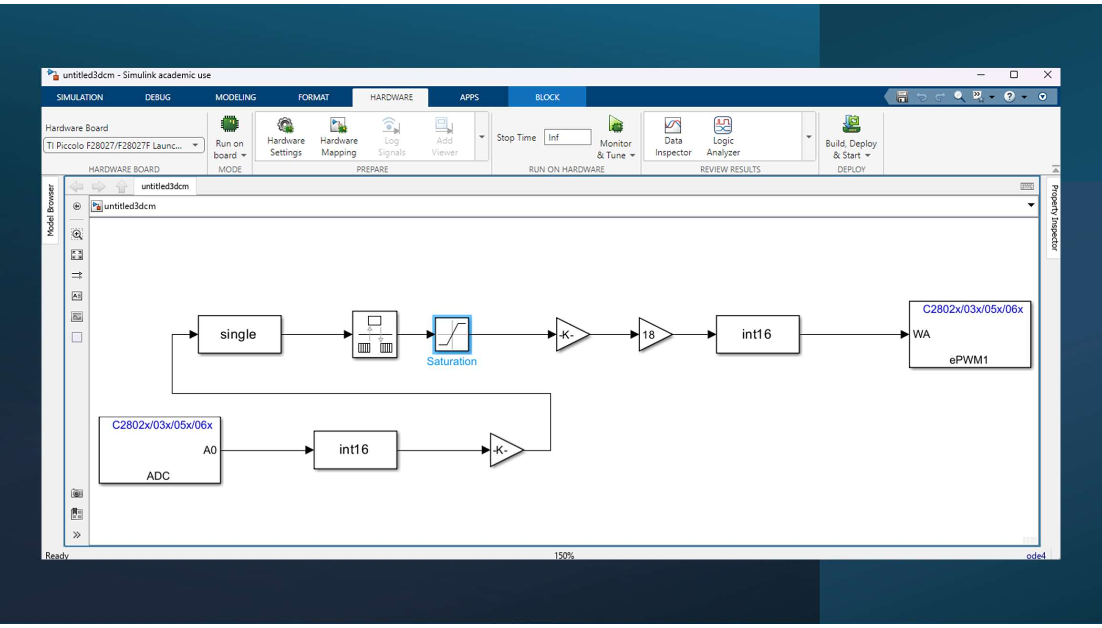
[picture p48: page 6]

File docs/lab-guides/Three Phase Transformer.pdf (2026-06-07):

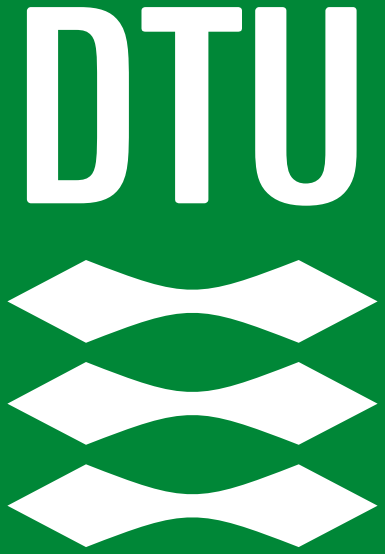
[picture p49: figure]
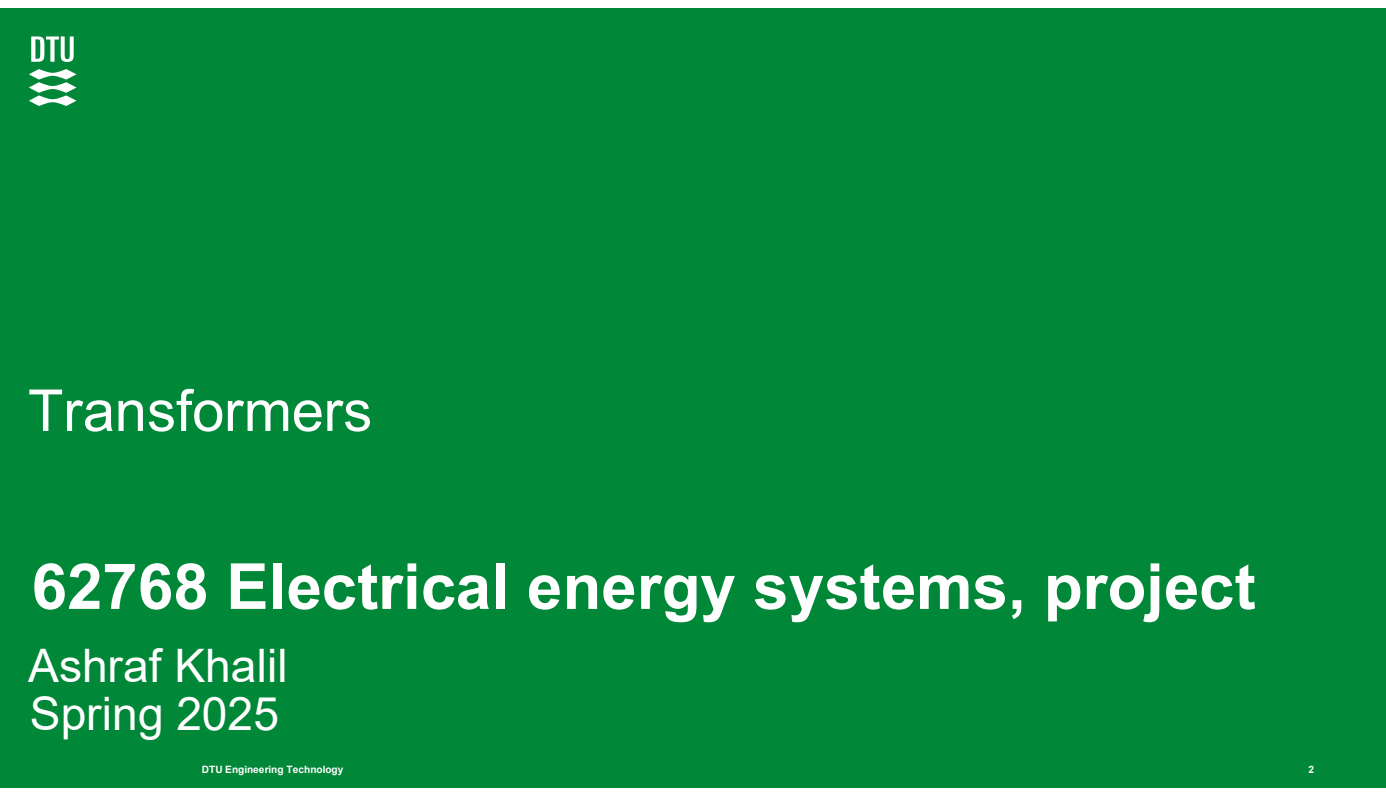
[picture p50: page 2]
7 April 2022; DTU Engineering Technology; Transformers

62768 Electrical energy systems, project
Ashraf Khalil
Spring 2025

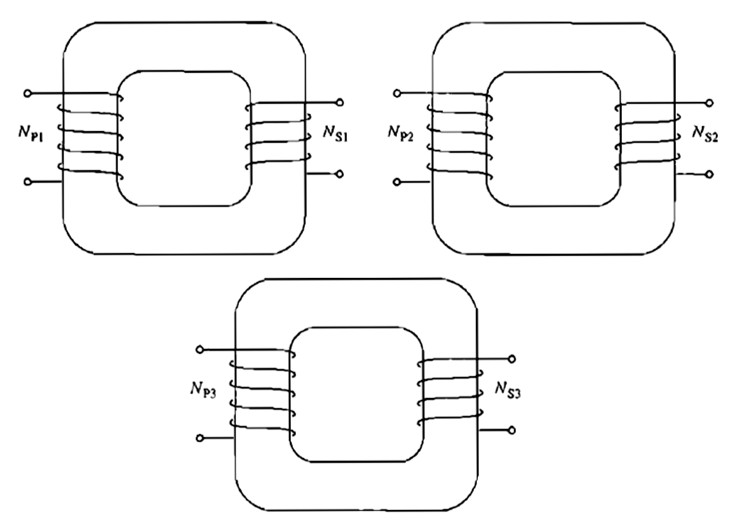
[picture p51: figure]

7 April 2022 | DTU Engineering Technology

## THREE-PHASE TRANSFORMERS

- A single three-phase transformer is lighter, smaller, cheaper, and slightly more efficient, but using three separate single-phase transformers has the advantage that each unit in the bank could be replaced individually in the event of trouble.
- A utility would only need to stock a single spare single-phase transformer to back up all three phases, potentially saving money.

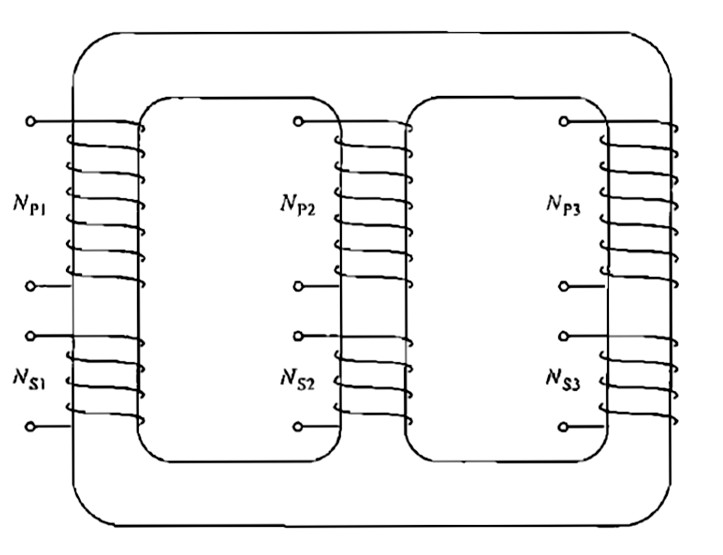
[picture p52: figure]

Three single-phase transformers Three sets of windings wrapped on a common core. 3

7 April 2022 | DTU Engineering Technology

## Three-Phase Transformer Connections

### - 1. Wye- wye (Y - Y) - 2. Wye-delta (Y -∆) - 3. Delta-wye (∆ -Y) - 4. Delta-delta (∆ - ∆)

### - Any single transformer in the bank behaves exactly like the single-

phase transformers already studied.

### - The impedance, voltage regulation, efficiency, and similar calculations for three-phase transformers are done on a per-phase basis, using exactly the same techniques already developed for

single-phase transformers. | 4

# WYE-WYE CONNECTION

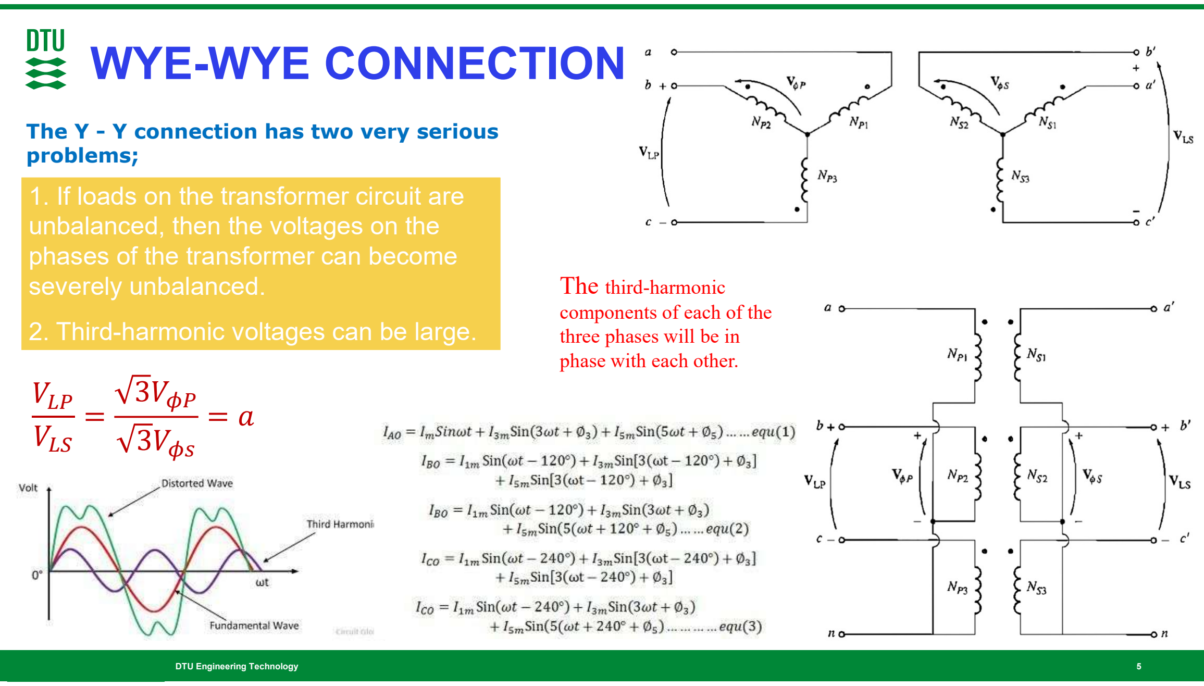
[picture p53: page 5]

7 April 2022 | DTU Engineering Technology

The Y - Y connection has two very serious problems;

### 1. If loads on the transformer circuit are

unbalanced, then the voltages on the phases of the transformer can become severely unbalanced.
2. Third-harmonic voltages can be large.

The third-harmonic
components of each of the
three phases will be in
phase with each other.
V
V

=

3V
3V

= a

5

7 April 2022 | DTU Engineering Technology

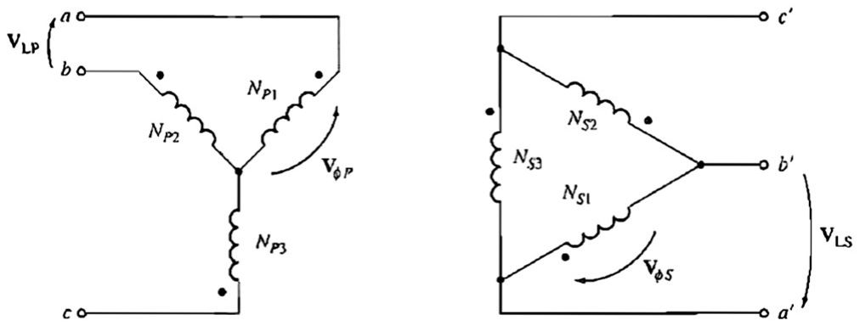
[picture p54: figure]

## WYE-DELTA CONNECTION

The Y - ∆ connection has no problem with third-harmonic components in its voltages, since they are consumed in a circulating current on the a side. This connection is also more stable with respect to unbalanced loads, since the a partially redistributes any imbalance that occurs. V V

= a V V =

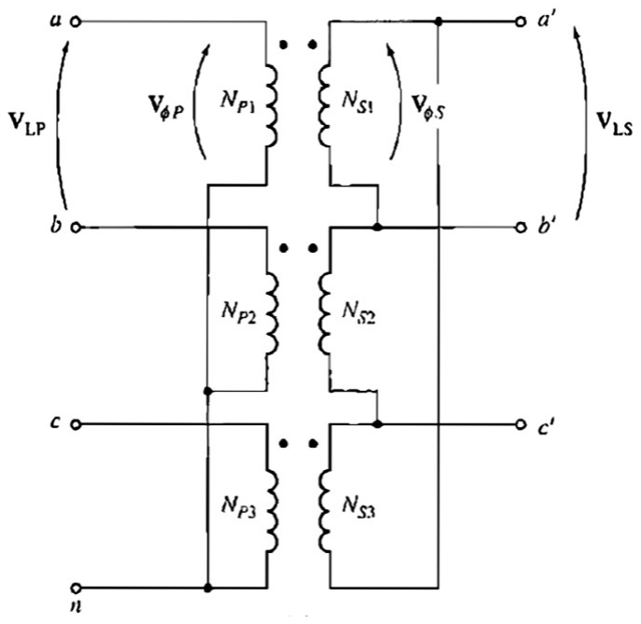
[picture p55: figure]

3V V | V V = 3 a | 6

7 April 2022 | DTU Engineering Technology

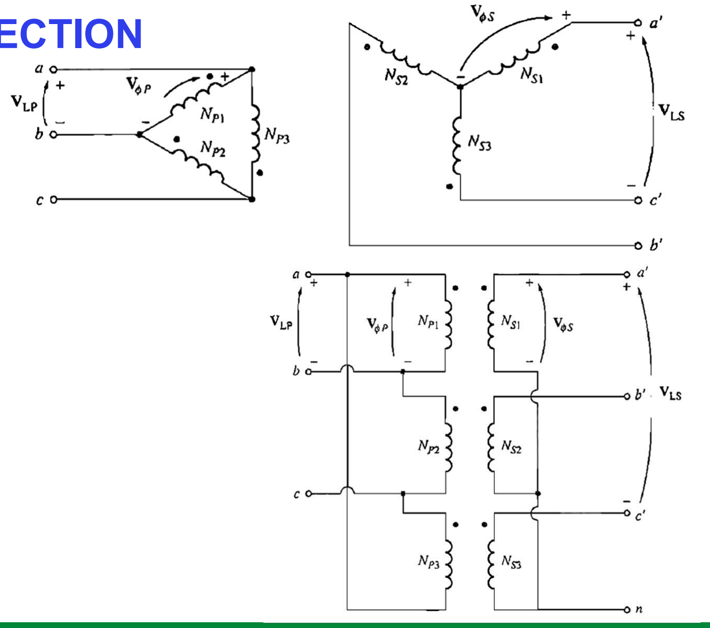
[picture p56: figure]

## DELTA-WYE CONNECTION

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
## DELTA-DELTA CONNECTION

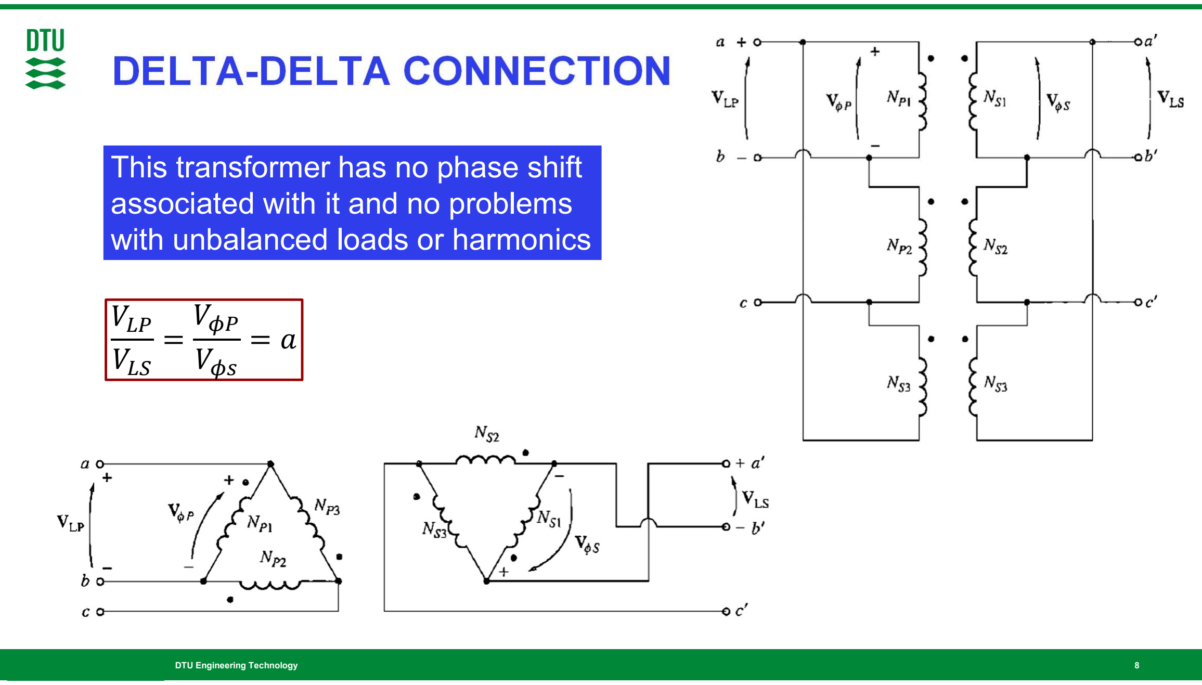
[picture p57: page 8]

7 April 2022 | DTU Engineering Technology

### This transformer has no phase shift associated with it and no problems with unbalanced loads or harmonics

V
V

=

V
V

= a

8

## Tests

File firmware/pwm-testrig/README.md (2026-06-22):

# PWM-testrig — Arduino Nano

Lille bench-instrument: to potmetre sætter **frekvens** og **duty cycle** på en
PWM-udgang (D9), og de faktiske værdier vises på en SSD1306 OLED. Tænkt som
stimulus/testkilde sammen med AD3'en, fx til gate-drev og konverter-test.

Bare-metal AVR C (ingen Arduino-framework), samme stil som resten af `firmware/`.

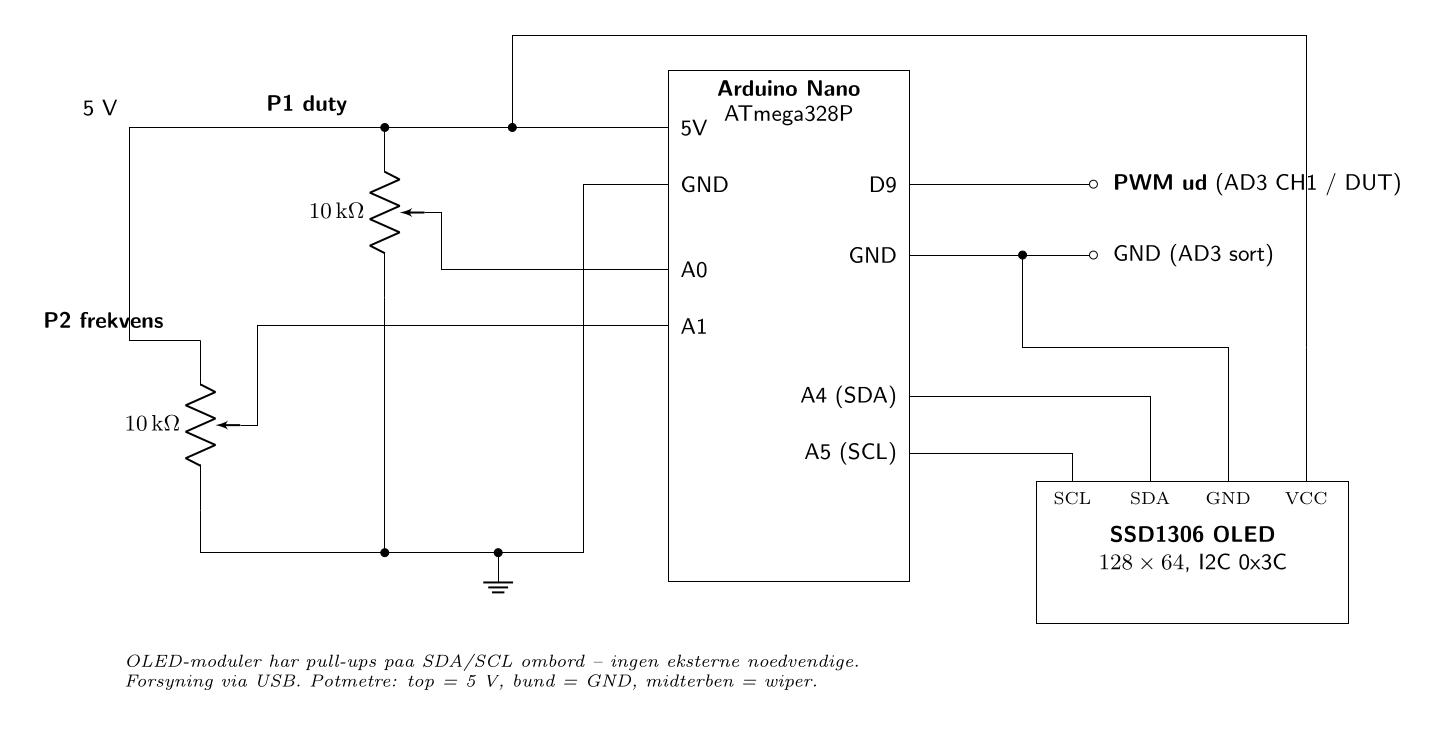
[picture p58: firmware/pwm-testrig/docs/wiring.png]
Forbindelsesdiagram


## Specifikationer

| Ting | Værdi |
| --- | --- |
| PWM-udgang | **D9** (OC1A, Timer1, 16-bit) — 0–5 V logik |
| Frekvens (P2 → A1) | **100 Hz – 50 kHz**, pseudo-logaritmisk (tre dekade-segmenter) |
| Duty (P1 → A0) | **0–100 %** (0 % og 100 % giver ægte konstant lav/høj) |
| Display | SSD1306 128×64, I2C adresse **0x3C** (0x3D: ret `config.h`) |
| Opdatering | ~10 Hz, med dødbånd så ADC-støj ikke flimrer |

Displayet viser den **faktiske** (timer-kvantiserede) frekvens — ikke ønskeværdien.
Riggen kører videre uden display (I2C-laget har timeout).

## Byg & flash (PlatformIO)

```bash
cd firmware/pwm-testrig
pio run                       # byg (klon-Nano = default)
pio run -t upload             # flash via USB (CH340, gammel bootloader)
pio run -e nano_new -t upload # original Nano / ny bootloader
```

> **Klon-note:** CH340-kloner bruger næsten altid den gamle bootloader (57600
> baud) = `nano_old` (default). Fejler upload med sync-fejl, så prøv `nano_new`.

## Filer

| Fil | Rolle |
|---|---|
| `include/config.h` | Pins, frekvensområde, I2C-adresse, dødbånd |
| `src/pwm.c` | Timer1 Fast PWM (mode 14): ICR1 = frekvens, OCR1A = duty, auto-prescaler |
| `src/adc.c` | Polled ADC med 8× midling |
| `src/i2c.c` | Minimal TWI-master (400 kHz, write-only, med timeout) |
| `src/ssd1306.c` | OLED-driver uden framebuffer (window + stream), 1× og 2× font |
| `src/main.c` | Pot-mapping, hysterese, displaylayout |

## Verifikation med AD3

Sæt scope CH1 på **PWM ud** og sort til **GND**-bøsningen, og sammenlign
WaveForms' frekvens/duty-måling med displayet. Husk 10×-probe-indstillingen.
Automatiseret: `python tools/ad3/ad3_check.py measure --attenuation 10
--expect-freq <displayværdi> --expect-duty <displayværdi>`.

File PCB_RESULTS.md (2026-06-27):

# PCB & footprint results — 62768 energy system

Status efter hardware/PCB-fasen (jf. `PCB_HANDOFF.md`). Alt ligger i `hardware/kicad/`.

## Hvad der er lavet

1. **3 nye system-skemaer** i `hardware/kicad/system/` (ERC: 0 fejl):
   - `rectifier.kicad_sch` — 3-faset 6-diode bro (1N4006) + 3×4700 µF ≈ 14.1 mF → V1 (Krav 1–3)
   - `mppt.kicad_sch` — PV → 1N5817 → 14.1 mF MPPT-cap → **diskret** 5 V-regulator
     (LM358 + BZX55C5V1 + BD139) → lager, + PV-V/I-sense til Arduino (Krav 9, 11)
   - `current_sense.kicad_sch` — 3 kanaler lavside 1 Ω-shunt + LM358 ×10.09 → ADC (Krav 10)
2. **Alle 7 skemaer har footprints** (KiCad stock, verificeret mod datablade) og
   **PCB-stik** (skrueterminaler til effekt, headers til signal). Sim-artefakterne
   `V_in`/`Rload` i buck/boost er erstattet af terminaler.
3. **BOM:** `hardware/kicad/bom/footprint_map.csv` — ref → indkøbsdel (shop/kit) →
   footprint → noter. **Alle substitutioner er flagget der.**
4. **7 PCB'er, alle net routet** (komponenter på top; B.Cu er hoved-etchen, F.Cu kun de få nødvendige kryds = trådbroer/side 2), autoroutet med Freerouting i to trin, **DRC: 0 fejl og 0 uroutede på alle**, render + DRC-rapport pr. board.

## ⚠️ To wiring-fejl FUNDET OG RETTET i drive_circuit (GUI-redigeringen d07ce2a)

1. **Friløbsdioden D1 lå med begge ben på +20 V** (motor+ er +20V-skinnen) — den
   beskyttede ingenting; induktiv kickback ville ramme Q1 uhindret. Anoden er
   flyttet til switch-knuden (M1.2/Q1.D), så D1 nu ligger over motoren.
2. **IR2110'ens HIN/SD/VSS/VS-ø var koblet sammen men IKKE til GND** (flydende
   logikreference + udefineret shutdown). Øen er lagt på GND.

Begge rettelser er lavet direkte i `.kicad_sch` (skemaet er fortsat source of truth);
`retrofit_pcb.py` dokumenterer indgrebet.

## Boards — PRODUKTIONSKLAR til XTool fiberlaser (DRC 0 fejl på alle 7)

Designreglerne fra [SimsesLab/DTU-PCB-prototyping](https://github.com/SimsesLab/DTU-PCB-prototyping)
er anvendt: bane 1.0 mm, clearance 0.8 mm, solid no-net laser-zone på B.Cu,
DIP **LongPads**, TO-220 med 1.7 mm pads (`energy_system:*_LaserPads`, luft 0.84 mm).
**Laser-filer (DXF) + Gerbers + udskæringsmål + jumperliste + xTool-tjekliste:**
→ `hardware/kicad/production/` (README dér er køreplanen).

Komponentnavnene (refdes) er graveret som **kobber-tekst på OVERSIDEN (F.Cu)** ved hver komponent — de følger med i `<board>_top_cu.dxf` (ætses ved dobbeltsidet, eller graveres på toppen sammen med trådbro-planen ved enkeltsidet).

Hvert board er nu et **KiCad-projekt**: `.kicad_pro` + `.kicad_sch` + `.kicad_pcb`
ligger sammen med samme basenavn — åbn `.kicad_pro`-filen, så er skema og PCB
linket (skift editor med knappen). Projektfilen indeholder laser-netclassen
(0.8/1.0 mm), så manuel routing i GUI'en bruger de rigtige regler. Ved *Update
PCB from Schematic*: sæt flueben i **"Re-link footprints to schematic symbols
based on their reference designators"** (boardene er bygget scriptet, så
UUID-links findes ikke første gang).

**ALLE boards er 104×104 mm** (positionerings-jiggens format: kobberplade skæres
til præcis 109×109, edge cuts 104×104 = 2.5 mm rand). Kompakt placering (5 mm
komponent-gab), klyngen **centreret** i omridset — ingen komponenter klods op
ad edge cuts. drive_circuit er håndplaceret (GUI) og derefter to-trins-routet.

| Board | Projekt | Top-baner (trådbroer/side 2) |
|---|---|---|
| Buck | `boards/buck/buck.kicad_pro` | **0 — helt enkeltsidet** |
| **Buck v2 (IR2110 high-side)** | `boards/buck/buck_v2/buck_v2.kicad_pro` | 21 (116 mm) |
| Boost | `boards/boost/boost.kicad_pro` | 2 (35 mm) |
| **Boost v2 (IR2110)** | `boards/boost/boost_v2/boost_v2.kicad_pro` | 17 (255 mm) |
| Motor-drive | `boards/drive_circuit/drive_circuit.kicad_pro` | 20 (135 mm) |
| Feedback | `boards/feedback_circuit/feedback_circuit.kicad_pro` | 15 (73 mm) |
| Rectifier | `boards/rectifier/rectifier.kicad_pro` | 7 (60 mm) |
| MPPT/PV (lineær) | `boards/mppt/mppt.kicad_pro` | 15 (77 mm) |
| **MPPT buck (IR2110 high-side)** | `boards/mppt_buck/mppt_buck.kicad_pro` | 8 (65 mm) |
| Current sense | `boards/current_sense/current_sense.kicad_pro` | 8 (68 mm) |
| **C2000 feedback (TI-port, 3.3 V)** | `boards/c2000_feedback/c2000_feedback.kicad_pro` | 12 trådbroer |

Ingen vias på nogen boards (kvadrat-formatet + kompakt placering routede
bedre end de gamle aflange boards).

**Status:** ALLE net er routet (0 uroutede, DRC 0 fejl). To-trins-routing: bunden (B.Cu) er hoved-etchen; toppen (F.Cu) indeholder kun de kryds der er umulige enkeltsidet — byg dem som trådbroer (anbefalet) eller ets toppen som side 2. Se `hardware/kicad/production/README.md`.

**To fejl mere fanget i produktions-passet:**
- Buck/boost brugte det generiske `Device:Q_NMOS`-symbol med **bogstav-pinnumre
  (G/D/S)** — TO-220-footprintens pads hedder 1/2/3, så MOSFET'ens pads fik ALDRIG
  net i de første board-versioner (no-net pads tæller ikke som "unconnected"!).
  Fixet med G/D/S→1/2/3-mapping + en fail-hard kontrol i `pcb_build.py`.
- MPPT'ens pass-transistor er skiftet **BD139 → TIP41A** (shoppen har den):
  TO-126's 2.28 mm pitch kan fysisk ikke overholde 0.8 mm clearance, og TO-220
  er alligevel bedre til de ~7 W.

## Substitutioner (fra footprint_map.csv — bestil efter den)

| Skema-del | Køb i stedet | Note |
|---|---|---|
| 1N5819 | **1N5817** | shoppen har kun 5817; OK ved 15 V bus |
| 1N4007 | **1N4006** | 800 V rigeligt ved 20 V |
| IRF530N/IRF540N | **IRF530/IRF540** | samme die/pinout, uden N-suffix i shoppen |
| 330 Ω / 33 k | **332R / 33k2** | E96-shop; 0.6 % afvigelse |
| **L 470 µH** | **egen-viklet toroid** | målt med skydelære: OD 34.5 mm stående på kant, ben-pitch 28.2 mm c-c, ben Ø1.6 → footprint `energy_system:L_Toroid_Vertical_L34.5mm_W15.0mm_P28.20mm_LaserPads` (buck+boost re-routet, boards nu 145×72). **Genberegn ripple** (Lec 2) med den viklede L |
| 15 mF | **3× 4700 µF/50 V** | = 14.1 mF |

**Kit-dele uden shop-ækvivalent (flagget, IKKE substitueret):** IR2110 (DIP-14),
IL300 (DIP-8, **ingen erstatning** — servoloopet kræver den), ILD74 (DIP-8; 4N25 er
IKKE drop-in), MCP601 (PDIP-8). Alle pakker er verificeret i `docs/datasheets/`.
Brug DIP-sokler fra shoppen til alle IC'er.

## Vigtige el-noter

- **Buck J4 (+12V_SW) er refereret til SW-knuden**, ikke GND — high-side switch
  kræver flydende/bootstrap gate-forsyning. Sådan er teamets opto-gate-drive tegnet;
  overvej IR2110-løsningen fra drive-kredsen, jf. `docs/system-architecture.md`.
- **Boost v2 = boost med rigtig IR2110 gate-driver** (`boards/boost/boost_v2/`).
  Den gamle boost drev MOSFET-gaten direkte fra en 4N25-opto; optoens ~20 µs
  sluk-tid strakte dutyen voldsomt (20 % → 65 % @ 10 kHz), så boardet kun duede ved
  1–2 kHz med stor ripple. v2 indsætter kæden **opto (CNY17) → IR2110 LO → R3‖D2 →
  gate** (lavside, ingen bootstrap), så gaten slås hårdt høj *og* lav på ns — duelig
  ved 20–50 kHz med ren duty. Effekttrinet (L1/M1/D1/C1) er uændret. Separat **+15 V**
  drive-forsyning (J4), isoleret PWM-jord (GND_MCU) bevaret. ERC 0 fejl, netliste
  verificeret pin-for-pin, DRC 0 fejl/0 uroutede (1 benign track_dangling-stump).
  Genereres med `tools/generators/build_boost_v2.py` (schbuild). Production-DXF +
  Gerbers i `production/boost_v2/`.
- **Buck v2 = buck med IR2110 HIGH-SIDE driver** (`boards/buck/buck_v2/`). Den gamle
  high-side-drive var en 4N25-opto med et 9V-batteri flydende paa SW-knuden — langsom og
  klodset. v2 beholder hele front-enden (LM7805 -> NE555 + RV1/trimmer timing, SW1 valg
  555/ekstern PWM, opto-LED) og effekttrinet, men erstatter selve gate-driveren:
  opto (5V PWM, level-shiftet til ~15V) -> **IR2110 HIN** ; **HO -> R5(10)||D5 -> gate** ;
  **VS -> SW** ; bootstrap **D4(+15V->VB) + C7(VB->VS)** ; LIN/SD til GND. 9V-batteriet er
  fjernet, +15V driver-forsyning via J5 (jordrefereret). R4 = gate->SW pulldown.
  Skemaet er **GUI-lavet** (source of truth) og redigeret kirurgisk med
  `tools/generators/patch_buck_v2_ir2110.py` (sexpdata) — front-enden er uroert.
  ERC 0 fejl, netliste verificeret pin-for-pin, DRC 0 fejl/0 uroutede (4 benigne
  track_dangling-stumper). 31 dele, haandplaceret (toroiden L1 fylder ~35x35 mm =
  egen kvadrant). Production-DXF + Gerbers i `production/buck_v2/`.
- **MPPT buck = switching buck der erstatter den lineaere MPPT** (`boards/mppt_buck/`).
  Den gamle MPPT var lineaer (TIP41A pass-transistor + LM358-servo) og braendte op til
  ~7 W af; rapporten (`solcelle-mppt.tex`) beskriver i forvejen en **buck styret af
  Arduino P&O**. Dette board er den buck: PV (MPP 17.6 V / 0.57 A / ~10 W) → high-side
  IRF530 → friloeb → L → 5 V-lager (1 F). **Samme IR2110 high-side driver som buck_v2,
  men UDEN 555** — dutyen kommer 100 % fra Arduinoens PWM gennem opto → IR2110 HIN.
  Strøm/spaendingsmaaling er **eksternt** (INA219). **Effekt dimensioneret til ~2 A**
  (Vout 5 V): friloebsdioden er opgraderet fra 1N5819 (1 A) til en **≥3 A Schottky**
  (1N5822 paa DO-201AD — **shoppen har ingen ≥3 A Schottky, bestil 1N5822/SB540**), og
  L1 = 150 µH ≈ 31 kHz (vikles til den faktiske PWM-frekvens; kerne skal taale ≥2.5 A
  peak). ERC 0 fejl, netliste verificeret mod high-side-acceptkriterierne, DRC 0 fejl/
  0 uroutede/**0 vias** (2 benigne track_dangling), 8 traadbroer/65 mm. Genereres med
  `tools/generators/build_mppt_buck.py`. Production-DXF + Gerbers i `production/mppt_buck/`.
  **Verificer foer aetsning:** PWM-frekvens (saetter L), de fysiske kondensator-pitch
  (PV-bulk, boot-cap), og toroidens strømrating — se `AUDIT_buck_boost_ir2110.md` §8.
- **C2000 feedback/sensorprint (TI-port)** (`boards/c2000_feedback/`). **NB (2026-06-27):
  revideret til det integrerede system-board** — nu KUN 3 spændingskanaler (V1/LOAD/STORE →
  ADC); strømkanalerne I1/I2/I3 og PWM-pass er FJERNET (strøm måles af current_sense → Arduino;
  C2000 EPWM går direkte til konverter-optoerne). ERC 0. Se
  `docs/superpowers/specs/2026-06-27-system-integrated-pcb-interface-contract.md`.
  Den oprindelige 6-kanals standalone-beskrivelse herunder er historik. Front-end mellem
  effektsystemet og LAUNCHXL-F28027 — **alt skaleret til 0–3.3 V** (C2000 ADC abs-max 3.3 V,
  modsat de 5 V-skalerede current_sense/feedback-print). 6 kanaler + PWM-pass:
  V1/V2/V3-delere (÷11 / ÷7 / ÷3) med 1k serie + **3.0 V zener-klemme** + 10n;
  I1/I2 lavside 1R-shunt + **MCP601 ikke-inv.** (gain 7.5 / 10), I3 bidir 1R-shunt +
  MCP601 **differensforstærker** (gain 5, 1.65 V midt-skala); EPWM1A → 220R → drivkreds-opto.
  **MCP601 valgt frem for LM358:** ved 3V3-forsyning når LM358 kun ~1.8 V ud, MCP601 ~3.3 V.
  Skrueterminaler (effekt/retur) på venstre kant, korte 1×2/1×3-headers til LaunchPad på
  højre. Genereres med `tools/generators/build_c2000_feedback.py`. ERC 0 fejl, netliste
  verificeret pin-for-pin mod `docs/c2000-pinmap.md`, **DRC 0 fejl / 0 uroutede / 0 vias**,
  **12 trådbroer**. NB: boardet er for tæt til auto-placeringen (autoroutede 1–5 uroutede,
  ikke-deterministisk) — det bruger en **håndlavet signalflow-placering** i `PLACE`-dicten
  i `tools/pcb_build.py` (og skill-kopien), så routingen er stabil. Production-DXF + Gerbers i
  `production/c2000_feedback/`.
  **Verificér før ætsning:** delere/gains mod de faktiske rails, og at EPWM1A/ADC-ben matcher
  `c2000-pinmap.md` (header-rækkefølgen J2/J4/J6/J8 = +3V3·GND / V1·V2·V3 / I1·I2·I3 / PWM).
- **MPPT: BD139 afsætter op til ~7 W** ved fuld PV-strøm (lineær 17→5 V) —
  **køleplade påkrævet**, eller erstat med buck (Krav 17 tillader det).
- Current-sense er **lavside**: grenens returledning ind på J*k* pin 1, system-GND
  videre fra pin 2. PV-strømkanalen på MPPT-boardet er inverterende (gain −9.09).
- Feedback-boardet deler +5 V/GND på begge sider af IL300 — som teamets sim;
  galvanisk isolation er der ikke (bevidst valg, bare vid det).

## Værktøjskæde (reproducérbart)

```
.\tools\pcb_make_all.ps1 [-Jar <sti>\freerouting-1.9.0.jar] [-Boards buck,...]
```
netliste → pcb_netlist_json.py → pcb_build.py (placering, omrids, .kicad_pro) →
TRIN 1: DSN med F.Cu maskeret som power-lag → Freerouting 1.9.0 (Java 21) → import →
TRIN 2: bagside-kobberet låses (type fix) → Freerouting med toppen tilladt →
merge-import + refdes-kobbertekst + laser-zoner (pcb_route.py) → DRC + render.
NB: KiCad-stable popper en harmløs debug-assert-dialog under DSN-eksport
("non-closed outline") — klik **No**; `pcb_make_all` kører videre.

## Hvad I selv skal gøre

1. **Produktion på fiberlaseren:** følg `hardware/kicad/production/README.md` —
   DXF-filerne ligger klar pr. board, med udskæringsmål og xTool-tjekliste.
2. **Bestil efter `bom/footprint_map.csv`** + afklar spolen (470 µH-flaget).
3. Loddejumpere: træk de listede luftledninger som trådbroer på toppen (åbn boardet
   i KiCad og se ratsnest). MPPT/current-sense: overvej 30 min manuel omroute først.
4. **Mål de fysiske 4700 µF-kolber** (diameter/pitch) — footprintet antager D18/P7.5.
5. Verificér drive-rettelserne mod Exp 3A-sliden (D1-friløb + IR2110-ø på GND).
6. Efter gravering: bor hullerne (drill marks er små centreringsmærker), skær til mål.

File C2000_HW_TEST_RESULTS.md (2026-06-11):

# C2000 hardware bring-up — test results

Board: LAUNCHXL-F28027 (XDS100v2, COM16). Instrument: Digilent Analog Discovery 3,
scope probe **10x** (pass `--attenuation 10` to `tools/ad3/ad3_check.py`).
Toolchain: MATLAB R2025a + C2000 Microcontroller Blockset 25.1, TI cgt 22.6.0.LTS,
CCS 20.0.1 (DSS scripting), controlSUITE f2802x v230. Date: 2026-06-11.

## Toolchain fixes needed before anything built (step 3.0)

- **Simulink Coder + Embedded Coder were missing** from R2025a — only MATLAB Coder
  was installed. Installed both (25.1) headlessly with MathWorks Package Manager:
  `mpm install --release=R2025a --destination="C:\Program Files\MATLAB\R2025a"
  --products Simulink_Coder Embedded_Coder` (needs elevation). The Add-On GUI
  errors if you try to install them there afterwards — they're already present.
- `c2000setup` had already been run (third-party registry populated: TI cgt under
  `C:\ProgramData\MATLAB\tic2000\3P.instrset\...`, DSS from `C:\ti\ccs2001`).
- Verified end-to-end by building `PulseGenerator.slx` headlessly: codegen + cl2000
  compile + link OK (`PulseGenerator.out`).

## Test 3.1 — GPIO blink (`PulseGenerator.slx`) — **PASS**

- Model: Pulse Generator (period 1 ms, 50 %) → GPIO Digital Output, **GPIO0**
  (= LED LD2 = J6 pin 1). Board target was already `TI Piccolo F28027/F28027F LaunchPad`.
- Flashed via DSS:
  `dss.bat .../tic2000/CCS_Config/runProgram.js .../CCS_Config/f28027.ccxml PulseGenerator.out`
- AD3 scope on J6-1 (GND on J2-1), `ad3_check.py measure --attenuation 10
  --expect-freq 1000 --expect-duty 50`:

  | Measured | Expected | Verdict |
  |---|---|---|
  | 1000.61 Hz | 1000 Hz ±2 % | PASS |
  | 50.2 % duty | 50 % ±3 | PASS |
  | 0.04–3.23 V swing | 3.3 V logic | PASS |

- LED LD2 glows at half brightness (1 kHz is too fast to see blinking).

### Gotchas found (read before repeating)

1. **Boot switch S1 must be all-UP** (switch 3 = TRSTn up) or JTAG fails with
   `Error -1015: Device is not responding`. Demo position (UP-UP-DOWN) blocks the
   debugger. Power-cycle after changing.
2. **Flash with the device-specific `f28027.ccxml`**, not `f28x_generic.ccxml` —
   the generic config has no flash programmer ("flash is not available on this
   device", verify fails at 0x3F001F).
3. **10x probe**: AD3 reads 0–0.33 V unless attenuation is configured — looks like
   a floating-pin ghost signal. Set 10x in software (or flip probe to 1x).
4. Measured base frequency is +0.06 % off nominal — internal 10 MHz oscillator
   (no crystal fitted), well within tolerance.
5. (For step 3.3) **ADCINA5 is not on any LaunchPad header** — J1/J5/J2 carry
   A0–A4/A6/A7 and B1–B4/B6/B7 only. The lecture's `ADC.slx` channel must be
   remapped to e.g. ADCINA0 (J5-6) or ADCINA4 (J1-6).

## Test 3.2 — ePWM (`SliderPWM.slx`) — **PASS**

- Model: Slider → Constant → ePWM1 `WA` input (CMPA in %, source = input port).
  ePWM1: TBPRD = 10000 clock cycles, counting mode **Up-Down** → f = 60 MHz / (2·10000)
  = **3 kHz** (not the 5 kHz the handoff guessed). ePWM1A = GPIO0 = J6-1, same probe
  point as test 3.1.
- Static check (flashed binary, slider snapshot 15.28 %), AD3 `measure --attenuation 10`:

  | Measured | Expected | Verdict |
  |---|---|---|
  | 3014.32 Hz | 3000 Hz ±2 % | PASS |
  | 15.2 % duty | 15.28 % ±3 | PASS |

- Live check: deployed from the Simulink GUI with **Monitor & Tune**, duty tracked the
  slider in real time on the WaveForms scope (frequency constant at 3 kHz). Works as
  intended.

### Gotchas found

1. **External mode serial port is saved inside the model** — the lecture model shipped
   with COM9 and connect fails with `XCP serial port error ... cannot find the file
   specified`. Set Ctrl+E → Hardware Implementation → Target hardware resources →
   External mode → Serial port = **COM16** (this PC's XDS100 UART), then just
   Monitor & Tune → Connect (no rebuild needed — the binary is already running).
2. **S4 (serial switch) must be UP** for External mode — it routes the Piccolo SCI to
   the XDS100 USB-UART.
3. Monitor & Tune builds with `EXT_MODE=1` (XCP-on-serial, 3.75 Mbaud) baked into the
   binary — the standalone DSS-flash path and the Monitor & Tune path produce different
   executables from the same model.

## Test 3.3 — ADC (`ADC.slx`) — **PASS**

- Model samples **ADCINA1** (not ADCINA5 as the lecture quick-start suggested — and
  conveniently A1 *is* broken out: **J5 pin 5**). SOC0, acquisition window 7, trigger =
  CPU Timer0 (`CPU0_TINT0n`), Ts = 1 ms, uint16 out → gain 3.3/4095 → volts on
  Display/Gauge blocks.
- Stimulus: AD3 Wavegen W1 DC level (verified on the scope **before** wiring to the
  pin, never above 3.3 V) → J5-5. GND common on J2-1.
- Deployed via Monitor & Tune (COM16); count and reconstructed voltage tracked the
  applied DC level across a 0.5–3.0 V sweep, matching `count ≈ V·4095/3.3`
  (1.65 V → ~2048). Linearity good, works as intended.

## Test 3.4 — closed loop (`MotorControl2026.slx`) — attempted, instructive failure

RC fake plant (ePWM1A/J6-1 → 10 kΩ → node → 1 µF → GND → ADCINA1/J5-5). The loop
never regulated; the post-mortem found **three independent problems**, all worth knowing:

1. **Model bug — PID saturation limits don't match the actuator scaling.** The Discrete
   PID limits output *and* integrator to **[0, 99.9]**, but the external "Extra clamping"
   is [0, 1] before the ×3000 → int16 → CMPA path. Consequence: the integrator legally
   winds to ~100; CMPA = 99.9·3000 saturates int16 at 32767 > TBPRD (15000), so the ePWM
   **never fires a compare event and the output freezes** at its last level. Unwinding
   would need error < −5, impossible on a 3.3 V plant. Fix: PID limits [0, 1].
2. **Lecture-rig tuning doesn't transfer.** P=20, I·Ts=2, D=0.6 (unfiltered) are for the
   lecturer's motor rig — on a 10 ms RC they're wildly hot, and unfiltered D amplifies
   ADC ripple into output noise.
3. **The breadboard link (pin → 10 kΩ → node) was open the whole time.** The ADC read a
   floating pin (~2.4 V — held *very* convincingly stable by S&H charge-injection into
   the 1 µF cap), so every "measurement" was fiction. Lesson now baked into the workflow:
   **verify the plant open-loop (fixed duty → expected node voltage) before closing any
   loop.**

Abandoned in favour of the ATmega2560 (the project's actual MCU) — see below.

### Instrument gotcha (AD3)
The **first capture after opening the AD3 from the SDK shows a phantom transient**
(auto-configure relay glitch). Discard capture #1, trust capture #2 onwards.

---

# ATmega2560 (Arduino Mega) bring-up — the project MCU

Same ladder, ported per the Obsidian note *Code Generation — ATmega2560 (Arduino Mega)
Workflow*. Board: Mega 2560 **clone (CH340, COM9)**. Toolchain installed headlessly:
`mpm install --release=R2025a --products Simulink_Support_Package_for_Arduino_Hardware
MATLAB_Support_Package_for_Arduino_Hardware` (bundles AVR-GCC — no TI-style version
matching). Date: 2026-06-11.

## M1 — GPIO blink — **PASS**
Pulse Generator (0.2 s / 50 %) → Digital Output pin 13, *Build Deploy & Start* via COM9.
LED blinks; chain proven.

## M2/M3 — PWM + ADC (folded into the plant check) — **PASS**
- PWM block pin 11 @ 490.2 Hz default, fixed duty 128/255 → RC plant
  (pin 11 → 10 kΩ → node X → 1 µF → GND, node → A0).
- AD3 on node X: **2.489 V** vs 2.510 V predicted (128/255·5 V) — plant + ADC wiring
  verified open-loop *first* this time.

## M4 — closed-loop PI — **PASS** ✅
Loop: ref → Sum → Discrete PID (P=0.1, I=10, D=0, **limits [0,1] + clamping AW**) →
×255 → uint8 → PWM pin 11; feedback A0 → single → ×(5/1023). Ts = 1 ms.

| Ref | Node X (AD3) | Error |
|---|---|---|
| 2.0 V | ≈ 2.0 V (user-observed in WaveForms) | ~0 |
| 3.5 V | **3.4973 V** | **3 mV** |

Ripple ±0.14 V = the 490 Hz PWM triangle through τ=10 ms at d≈0.7, as predicted.
Integrator erases the offset; smooth ~100 ms settle (P=0.1/I=10 → ~8 Hz crossover,
~90° PM against the 16 Hz RC pole).

### Mega gotchas (read before repeating)
1. **Use the standard `Analog Input` block** (Simulink Support Package for Arduino →
   Common). A lookalike **"ADC Read" block (port `ADC_Ch1(A0)`)** from a bundled
   non-standard library builds fine but feeds the loop garbage — this single block swap
   took the loop from dead-at-0 V to regulating.
2. **External Mode (XCP serial) never connected through the CH340 clone** — `timeout
   expired, in response to XCP CONNECT` despite manual COM9 + 115200 baud. Workflow used
   instead: edit → *Build Deploy & Start* (~30 s) → verify on the AD3. Try a genuine
   Mega (16U2) before debugging this further.
3. Capacitor code **105K = 1 µF ±10 %** (10·10⁵ pF) — not 105 kΩ-anything.
4. PWM frequency choices on pin 11 (Timer1) are the AVR prescaler steps only (490.2 /
   3921.16 / 31372 Hz…). Never re-clock pins 4/13 (Timer0 = Arduino timekeeping).
5. Deploys auto-reset the board (DTR) — the pin idles low for ~2 s during flashing;
   don't scope-diagnose mid-flash.

### Division of labour that worked
Hands/GUIs (Simulink deploys, WaveForms) = Mads; remote AD3 verification via
`tools/ad3/ad3_check.py` (pydwf) when WaveForms is closed — only one app can own the AD3.

### Next (project work proper)
`MegaPI` is the template for the real controllers: V1 motor PID, MPPT (P&O), 1 s serial
monitoring. Next session: pick ADC pins + divider ratios for V1/V2/V3 (`g_v,adc` =
(5/1023)·R_low/(R_high+R_low)), assign the motor-drive PWM pin, move the model into
`firmware/`.

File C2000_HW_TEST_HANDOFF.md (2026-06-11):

# C2000 Code-Gen Hardware Bring-Up & Test — Handoff

**You are a fresh Claude Code session.** Goal: **get MATLAB/Simulink automatic code
generation actually running on the real TI C2000 F28027 LaunchPad**, and **verify each step
on hardware using a Digilent Analog Discovery 3 (AD3)** as the measurement + stimulus
instrument.

This is hands-on hardware work — you'll guide the user through Simulink deploy + WaveForms,
**and** you can script the AD3 yourself via its SDK to automate the verification. Work
**incrementally**: get the simplest thing blinking before touching the closed loop.

> Read first: the study note `Obsidian/Courses/62768 Electrical Energy Systems/Lecture
> Notes/Code Generation — C2000 Workflow.md` (the full workflow this deploys) and the four
> example models in `simulation/Code Generation/`.

---

## 0. Win condition

By the end you can demonstrate, on the physical board, with AD3 evidence:
1. **GPIO blink** deployed and toggling (LED + AD3 logic capture).
2. **ePWM** out at the right **frequency + duty** (AD3 scope: 5 kHz / 200 µs, duty tracks the slider).
3. **ADC** reading a **known AD3-supplied voltage** correctly (Monitor & Tune live value vs `count ≈ V·4095/3.3`).
4. (stretch) **MotorControl2026** closed loop responding to a reference.

Capture results in a test log → `C2000_HW_TEST_RESULTS.md` (per test: setup, AD3 numbers/screenshots, pass/fail, issues).

---

## 1. Hardware on the bench

| Item | Notes |
|---|---|
| **TI LAUNCHXL-F28027** | C2000 Piccolo F28027 LaunchPad, USB (XDS100v2 onboard debugger). Pinout: `docs/datasheets/Texas_Instruments-LAUNCHXL-F28027-datasheet.pdf` |
| **Digilent Analog Discovery 3** | USB. 2× scope (±25 V diff, 14-bit), 16× DIO (logic analyzer + pattern gen), 2× AWG (W1/W2, ±5 V), supplies. Host app **WaveForms 3**. |
| (optional) NI USB-6008 | also installed on this PC — alternative DAQ, but use the AD3 as asked. |

### ⚠️⚠️ SAFETY — read before wiring anything
- **Every F28027 pin is 3.3 V max.** The ADC inputs are **absolute-max 3.3 V** — overvoltage
  **kills the chip**.
- The **AD3 AWG can output ±5 V** → it *will* exceed 3.3 V if you're careless. When driving an
  ADC pin: set the AWG to **offset 1.65 V, amplitude ≤ 1.65 V** (so it swings 0–3.3 V), or add
  a divider/clamp. **Verify on the scope before connecting to the board.**
- **Common ground:** tie AD3 GND (⊥) to a LaunchPad **GND** pin, always.
- GPIO/ePWM outputs are 3.3 V logic — safe for the AD3 scope/logic inputs.

---

## 2. Software status (already installed — verify, don't reinstall)

| Tool | Where | Status |
|---|---|---|
| Code Composer Studio | `C:\ti\ccs2001` (v20.0.1) | installed. Also `CCS_20.5.1` installer in Downloads if a version bump is needed. |
| C2000Ware | `C:\ti\c2000` | installed |
| controlSUITE | `C:\ti\controlSUITE` | installed |
| WaveForms 3 + **SDK** | `C:\Program Files (x86)\Digilent\WaveForms3` + `…\WaveFormsSDK` | installed (`dwf` DLL present) |
| MATLAB | R2025a (+ R2024b) | Simulink + Embedded Coder present |
| **C2000 Microcontroller Blockset** | MATLAB Add-On | **VERIFY first** (see step 3) |

> Ignore `Downloads/sprc097` — those are **DSP281x** (older F281x) headers, **wrong chip**.
> The F28027 uses **C2000Ware**, already installed.

---

## 3. Bring-up plan (do these in order)

### Step 3.0 — verify the toolchain
- In MATLAB: `>> ver` (or Add-On Manager) → confirm **C2000 Microcontroller Blockset** is
  installed. If missing: Add-Ons → search `C2000` → install (MATLAB restarts). See the study
  note §3.
- Run **`c2000setup`** → it should **auto-detect** CCS `C:\ti\ccs2001`, C2000Ware `C:\ti\c2000`,
  controlSUITE. ⚠️ **Check the version it wants** — if it flags CCS 20.0.1 as untested for
  R2025a, point it at the **CCS 20.5.1** in Downloads (install first) or whichever it asks for.
  Version-mismatch is the #1 codegen failure.
- Plug in the LaunchPad → confirm Windows enumerates the XDS100v2 COM port (Device Manager),
  and `c2000setup`/CCS can see the target.

### Step 3.1 — GPIO blink (`PulseGenerator.slx`)  ← prove the chain end-to-end
- Open the model, Ctrl+E → Hardware board = **TI Piccolo F28027/F28027F LaunchPad**.
- **Build, Deploy & Start**. On-board LED should blink.
- **AD3 check:** probe the driven **GPIO pin** (find it from the model + LaunchPad pinout) with
  the AD3 **Logic analyzer** (or Scope). Confirm the toggle period matches the Pulse
  Generator. → first hardware evidence the codegen path works.

### Step 3.2 — ePWM (`SliderPWM.slx`)  ← verify the actuator
- Deploy. Probe the **ePWM1A output pin** with the **AD3 Scope**.
- Verify **frequency** (5 kHz → 200 µs period) using the scope's Measurements, and that moving
  the **slider changes the duty cycle** (AD3 duty measurement 0–100 %).
- Cross-check against the note's `TBPRD ≈ 11999 @ 60 MHz` maths.

### Step 3.3 — ADC (`ADC.slx`)  ← verify the sensor  ⚠️ 3.3 V SAFETY
- **AD3 AWG (W1)** → ADC input pin (`ADCINA5`, find the physical pin from the pinout).
  **Set W1 to a DC or slow ramp constrained to 0–3.3 V** (offset 1.65 V, amp ≤ 1.65 V). Verify
  on AD3 scope **before** connecting to the board.
- Run **Monitor & Tune (External Mode)** → read the ADC count live. Confirm
  **`count ≈ V_in · 4095 / 3.3`** (e.g. 1.65 V → ~2048). Sweep W1 and confirm linearity.
- This validates the sensing chain (`g_v,adc`) on real silicon.

### Step 3.4 — closed loop (`MotorControl2026.slx`)  ← stretch
- Needs a plant or an emulated feedback. Options: feed a known AD3 voltage as the "measured
  output" into the ADC and watch the PI drive the ePWM duty to regulate; or wire a simple RC
  as a fake plant. Verify the loop reacts to the reference. Keep it qualitative unless a real
  converter is on the bench.

---

## 4. Driving the Analog Discovery 3

Two ways — use both:

**A) WaveForms 3 GUI** (manual, fast to eyeball): Scope, Logic, Wavegen, Voltmeter tabs.
Good for first looks and screenshots for the log.

**B) Script it via the SDK** (automate verification — *this is the powerful part*):
- The `dwf` library lives in `C:\Program Files (x86)\Digilent\WaveFormsSDK`. Python binding:
  `pip install pydwf` (preferred), or call `dwf.dll` via `ctypes`. The SDK also ships C/Python
  samples under the install dir.
- With it you can, from a script: set **W1** to a precise 0–3.3 V level/ramp, capture **Scope
  CH1/CH2**, measure **frequency/duty** of the ePWM, and **sweep the ADC input while logging**
  — i.e. produce an automated PASS/FAIL for steps 3.2 and 3.3 instead of hand-reading the GUI.
- ⚠️ Enforce the **0–3.3 V clamp in code** before any AWG output reaches an ADC pin.

Close WaveForms 3 (GUI) before scripting — only one app can own the AD3 at a time.

---

## 5. Tooling / workflow notes

- **Builds** can run headless: `matlab -batch "..."` (open_system, set_param, `slbuild`/
  `rtwbuild`). But **Deploy + Monitor&Tune are interactive** — guide the user in the Simulink
  GUI (like prior sessions), and you handle the **AD3 side by script**.
- **Research hard:** the LaunchPad datasheet (pin map: which header pin = ePWM1A, ADCINA5,
  the LED GPIO), MathWorks "Get Started with C2000 Microcontroller Blockset", and the
  Digilent AD3 reference manual / WaveForms SDK docs. Clone repos / fetch examples as useful.
- Shell is **PowerShell on Windows**; quote paths with spaces.
- This is the **team repo** (`MadsRudolph/62768-energy-system`) — commit the results log with
  developer-voice messages, **no AI attribution** (global rule).

---

## 6. Likely gotchas

- **MATLAB↔CCS version mismatch** → build fails cryptically. Trust `c2000setup`'s required
  version; CCS 20.0.1 *and* 20.5.1 are available — use the one it asks for.
- **Wrong COM/driver** → install the XDS100v2 / FTDI driver if the target isn't seen.
- **AD3 + board ground not common** → garbage scope traces.
- **Over-voltage on ADC** → dead chip. Re-read §1 safety every time you touch an ADC pin.
- **Pin identification** — don't guess which physical pin is ePWM1A / ADCINA5; confirm from the
  datasheet pinout before probing/driving.
- `sprc097` in Downloads is the wrong chip's headers — ignore it.

---

## 7. Definition of done

- [ ] C2000 Blockset verified, `c2000setup` happy with CCS/C2000Ware/controlSUITE, target seen.
- [ ] `PulseGenerator` deployed; LED blinks; AD3 logic confirms timing.
- [ ] `SliderPWM` deployed; AD3 scope confirms 5 kHz + duty tracks the slider.
- [ ] `ADC` deployed; AD3 AWG (0–3.3 V) → Monitor&Tune count matches `V·4095/3.3`, linear sweep.
- [ ] (stretch) `MotorControl2026` loop responds to reference.
- [ ] `C2000_HW_TEST_RESULTS.md` written (per-test evidence + issues), committed + pushed.
- [ ] (nice) an AD3 SDK script that automates the PWM/ADC verification, committed.

Go incrementally, keep the 3.3 V rule sacred, and capture evidence at every step.

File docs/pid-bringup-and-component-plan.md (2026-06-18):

# PID bring-up + component plan — what we actually need to close the V1 loop

Working doc for finishing the system. Two goals:

1. **Finish the untested perfboard circuits** (buck, current-sense, MPPT hardware).
2. **Get the V1 motor PID running on the C2000** so we can tune it with Ziegler–Nichols.

Decisions this doc is built on (locked 18 June):
- **PCBs = perfboard ("hulprint") prototypes**, not the KiCad laser boards. The
  `hardware/kicad/` laser pipeline is a parallel/optional track — not on the critical path.
- **Control split:** **C2000 LAUNCHXL-F28027 = V1 motor PID** (3.3 V I/O, Simulink codegen);
  **Arduino Nano = MPPT** (P&O + INA219). The two MCUs are independent.

> ⚠️ Because the PID brain is the **C2000, every signal into it is 0–3.3 V max**, not 5 V.
> The dividers/gains in [`mega-pinmap.md`](mega-pinmap.md) are sized for a 5 V Arduino and
> are **wrong for this target** — see §4 for the 3.3 V versions.

---

## 1. Where we are right now (what's built and tested)

| Block | Physical state | Tested? | Evidence |
|---|---|---|---|
| DC motor (SR555) → A20 generator → Y‑Δ transformer → 3φ rectifier → **V1** | Built | ✅ **Yes** | Full sweep table: 7.5 V motor in → **15.23 V** out; 12.5 V → 26.4 V (`report/sections/generator-transformer.tex`) |
| **Drive circuit** (CNY17 → IR2110 → IRF540N, low-side) | Perfboard | ✅ ran the motor for the rectifier sweep | `report/images/DriveCircuit/DriveCircuit-Hulprint.jpg` |
| **Boost** (store 5 V → load) | Perfboard | ✅ **Yes** | 10.1 V out, 56 mVpp ripple @ 10 kHz / 48 % duty (`report/sections/boost.tex`) |
| **Feedback / IL300 iso-amp** | Perfboard | ⚠️ built, no measurement written up | `report/images/Feedback-circuit/…` |
| **Buck** (V1 → 5 V store) | **Not built** | ❌ **No** | `buck.tex` is design-only, "TODO … måleresultater" |
| **Current sensing** (discrete shunt + op-amp) | **Not built** | ❌ **No** | `stroemmaaling.tex` is a TODO stub |
| **MPPT power stage** (PV → buck → store) | PV characterised only | ❌ hardware not built | PV I–V/P–V measured directly; buck-MPPT only simulated (`test.tex`, `styring.tex`) |
| **C2000 codegen chain** (GPIO/PWM/ADC) | — | ✅ all PASS | `C2000_HW_TEST_RESULTS.md` |
| **C2000 closed loop** (MotorControl2026) | — | ❌ "instructive failure" | bugs found + fixed on paper, see §5 |

**Bottom line:** the *plant for the V1 PID is already finished and measured.* The boost is
done. The pieces that are genuinely missing are the **buck**, the **current-sense**, the
**MPPT power stage**, and — for the PID specifically — a **V1 voltage-sense scaled to 3.3 V**.

---

## 2. Answering the four questions (for the PID, what do we actually need?)

The V1 PID loop is: **C2000 PWM → drive circuit → motor → generator → transformer →
rectifier → V1 → sense → back into C2000 ADC.** Everything else hangs *off* V1 or is a
*separate branch*. So:

| Question | For the V1 PID / Ziegler–Nichols? | Why |
|---|---|---|
| **Do we need the motor?** | ✅ **Yes — non-negotiable** | The motor+generator **is the plant** the PID controls. No motor = no V1 to regulate. |
| **Do we need the buck?** | ❌ **No** | The buck is a *load on V1* (it charges the 5 V store), not part of the V1 loop. For ZN tuning you want a **simple, known load** on V1 (a power resistor), not the buck. Buck is needed for the *full system* (Krav 8/9/12) and to prove the 100→300 mA V1 step — but **not to get the loop running**. |
| **Do we need the boost?** | ❌ **No** | Boost is `store (5 V) → load (V2)`, downstream of the store. Independent of V1. Already tested anyway. |
| **Do we need MPPT?** | ❌ **No** | MPPT is the *parallel PV source*, runs on the **Arduino**, feeds the store. Nothing to do with the V1 loop. |

**So the minimum hardware to start tuning the PID = motor-drive chain (have it) + a V1→3.3 V
sense divider (build it, ~10 min) + the C2000 + a power-resistor load on V1.** That's it.

The buck / current-sense / MPPT are needed to **complete the system and the report**, just
not to *start* closing the loop. Build them in parallel; they don't block the PID.

---

## 3. The concrete wiring plan for the V1 PID (C2000)

```
                         3.3 V logic                       12 V motor rail
   C2000 ePWM1A  ──Rs──▶ CNY17 LED  ══(opto)══▶ IR2110 ──▶ IRF540N ──▶ DC motor
   (GPIO0 / J6-1)        [drive circuit, already built]                  │
                                                                         ▼
                                                          A20 gen → Y‑Δ xfmr → 3φ rect
                                                                         │
                                                                        V1  (≈15 V reg,
                                                                         │   ≤~27 V open-loop)
   C2000 ADC  ◀── 10nF ──┬───[ R_low 1k ]── GND          ┌──────────────┤
   ADCINA1 / J5-5        │                                │   load: 150 Ω power resistor
        ▲          3.0 V zener to GND (clamp)        [ R_high 10k ]      (known load for tuning)
        └── series 1k ───┘                                │
                                                          └── (later: buck taps here)
   GND: tie C2000 J2-1  ──  drive-circuit GND  ──  rectifier/V1 GND  (one common ground)
```

### Pin assignment (from `C2000_HW_TEST_RESULTS.md` — these are verified-present pins)

| Signal | C2000 pin | Note |
|---|---|---|
| **PWM → drive circuit** | **ePWM1A = GPIO0 = J6 pin 1** | the pin used in the PWM PASS test; 3.3 V logic |
| **V1 sense → ADC** | **ADCINA1 = J5 pin 5** | the pin used in the ADC PASS test (A5 is **not** on any header) |
| **GND** | **J2 pin 1** | common with drive circuit + rectifier |
| (optional) heartbeat | GPIO (LED LD2 = GPIO0 is taken by PWM) | use another free GPIO if wanted |
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

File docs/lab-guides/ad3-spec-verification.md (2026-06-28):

# AD3 spec-verification guide — remaining Pri-1 requirements

Measurement protocol for closing the six unverified Priority-1 requirements using the
**Analog Discovery 3 (AD3)** + WaveForms. The AD3 is the *instrument*; the rails are
powered by the actual energy system (generator / solar), not by the AD3 supplies.

Covers reqs **2, 3, 5, 6, 7, 16**. Each test lists the load setup, the WaveForms
instrument settings, the pass criteria (tied to the spec tolerance), and the report
section the capture belongs in.

> Workflow: Mads drives WaveForms and takes the measurements; this guide is the
> reference. Export each capture as PNG (WaveForms: *File → Export*) into the
> matching `report/images/...` folder and reference it in the listed section.

---
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

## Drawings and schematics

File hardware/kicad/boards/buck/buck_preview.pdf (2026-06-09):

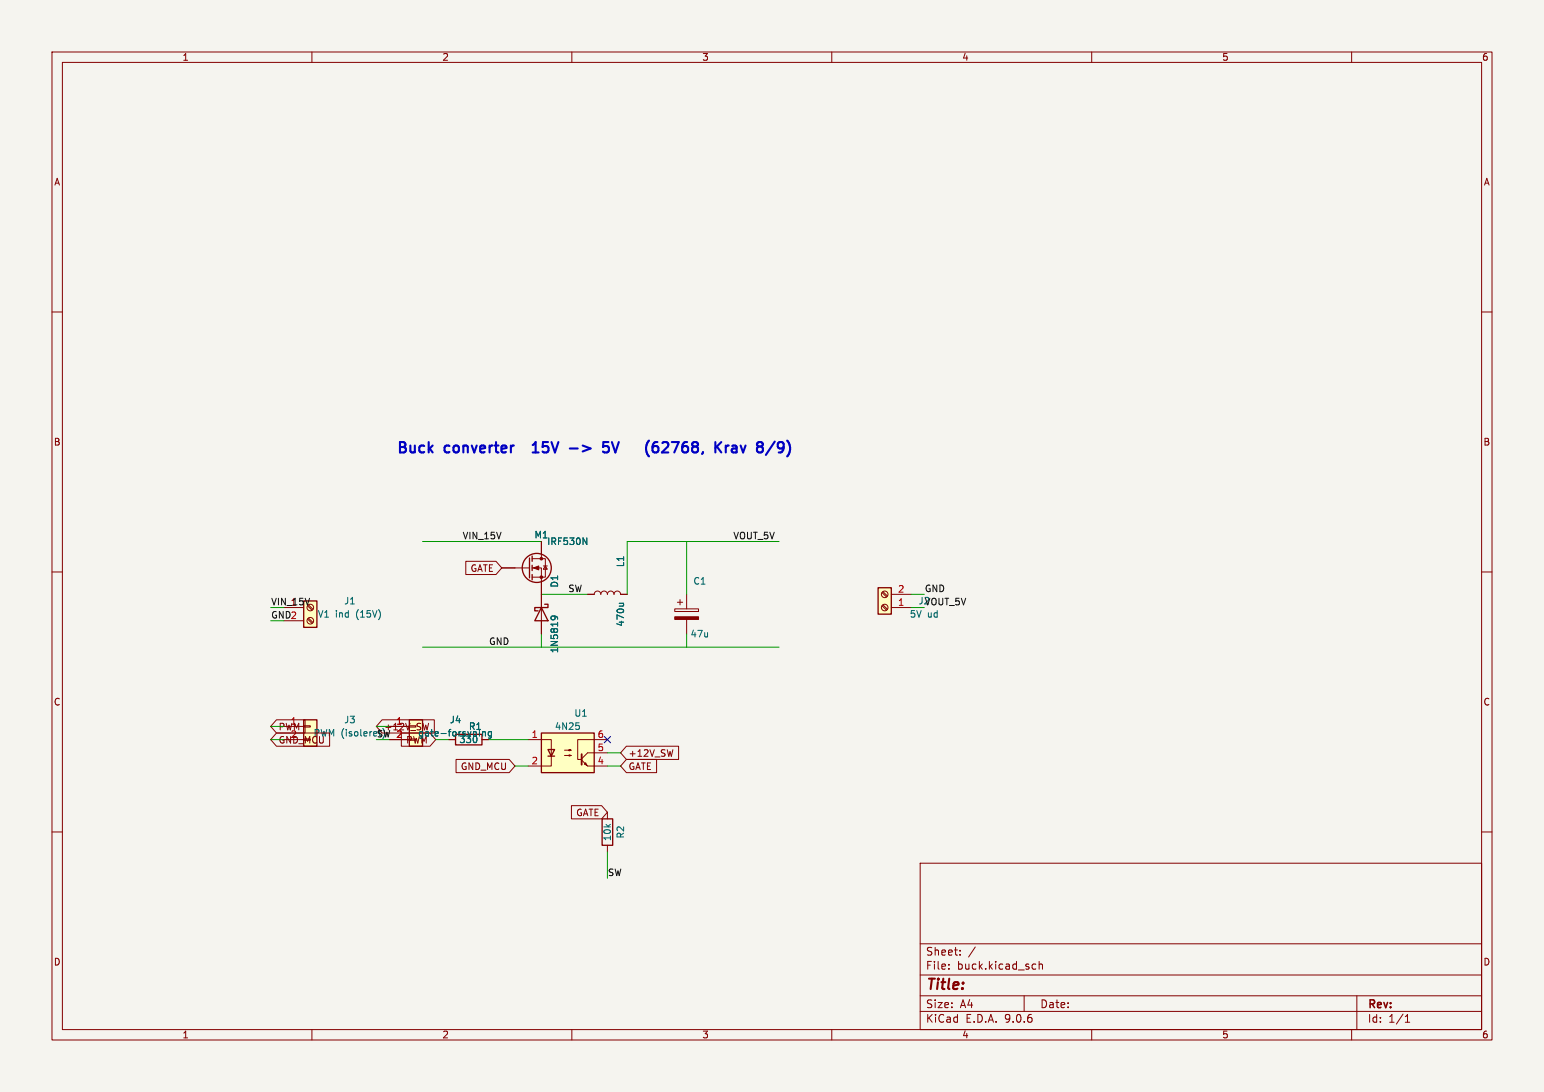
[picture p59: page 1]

Id: 1/1 Title: File: buck.kicad_sch Sheet: / 1

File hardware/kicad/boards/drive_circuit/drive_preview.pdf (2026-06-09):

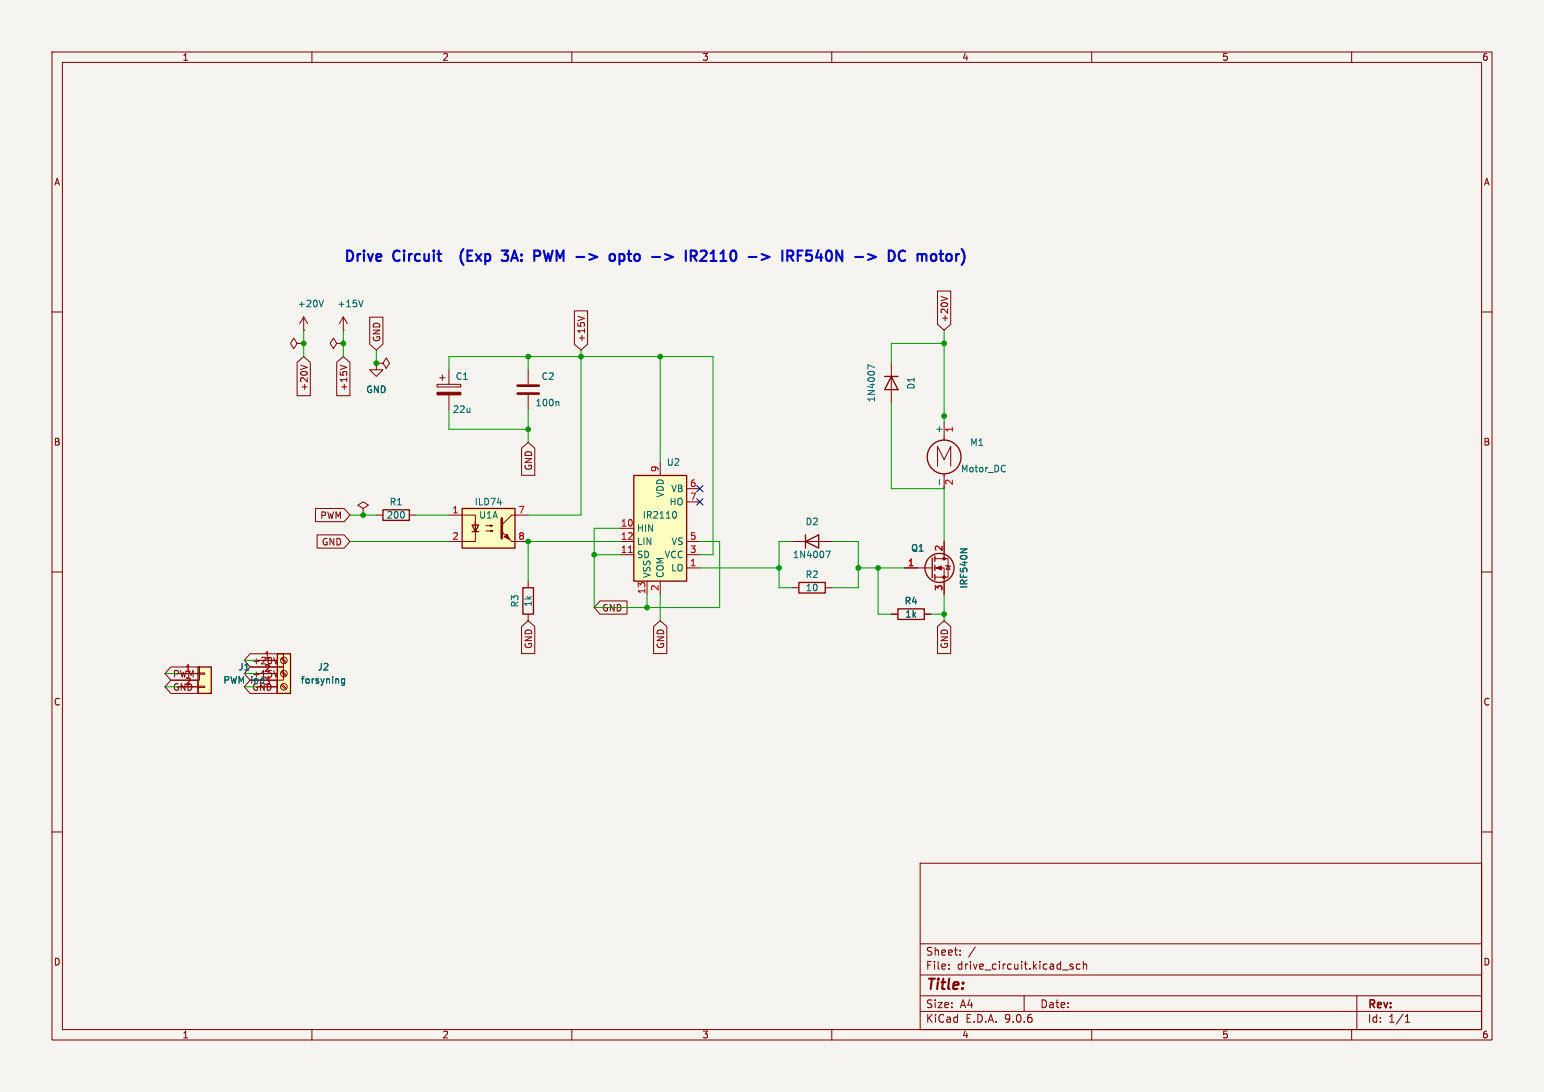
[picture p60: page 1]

2 VB 6 HO 7 VS 5 VCC 3

Id: 1/1 Title: File: drive_circuit.kicad_sch Sheet: /

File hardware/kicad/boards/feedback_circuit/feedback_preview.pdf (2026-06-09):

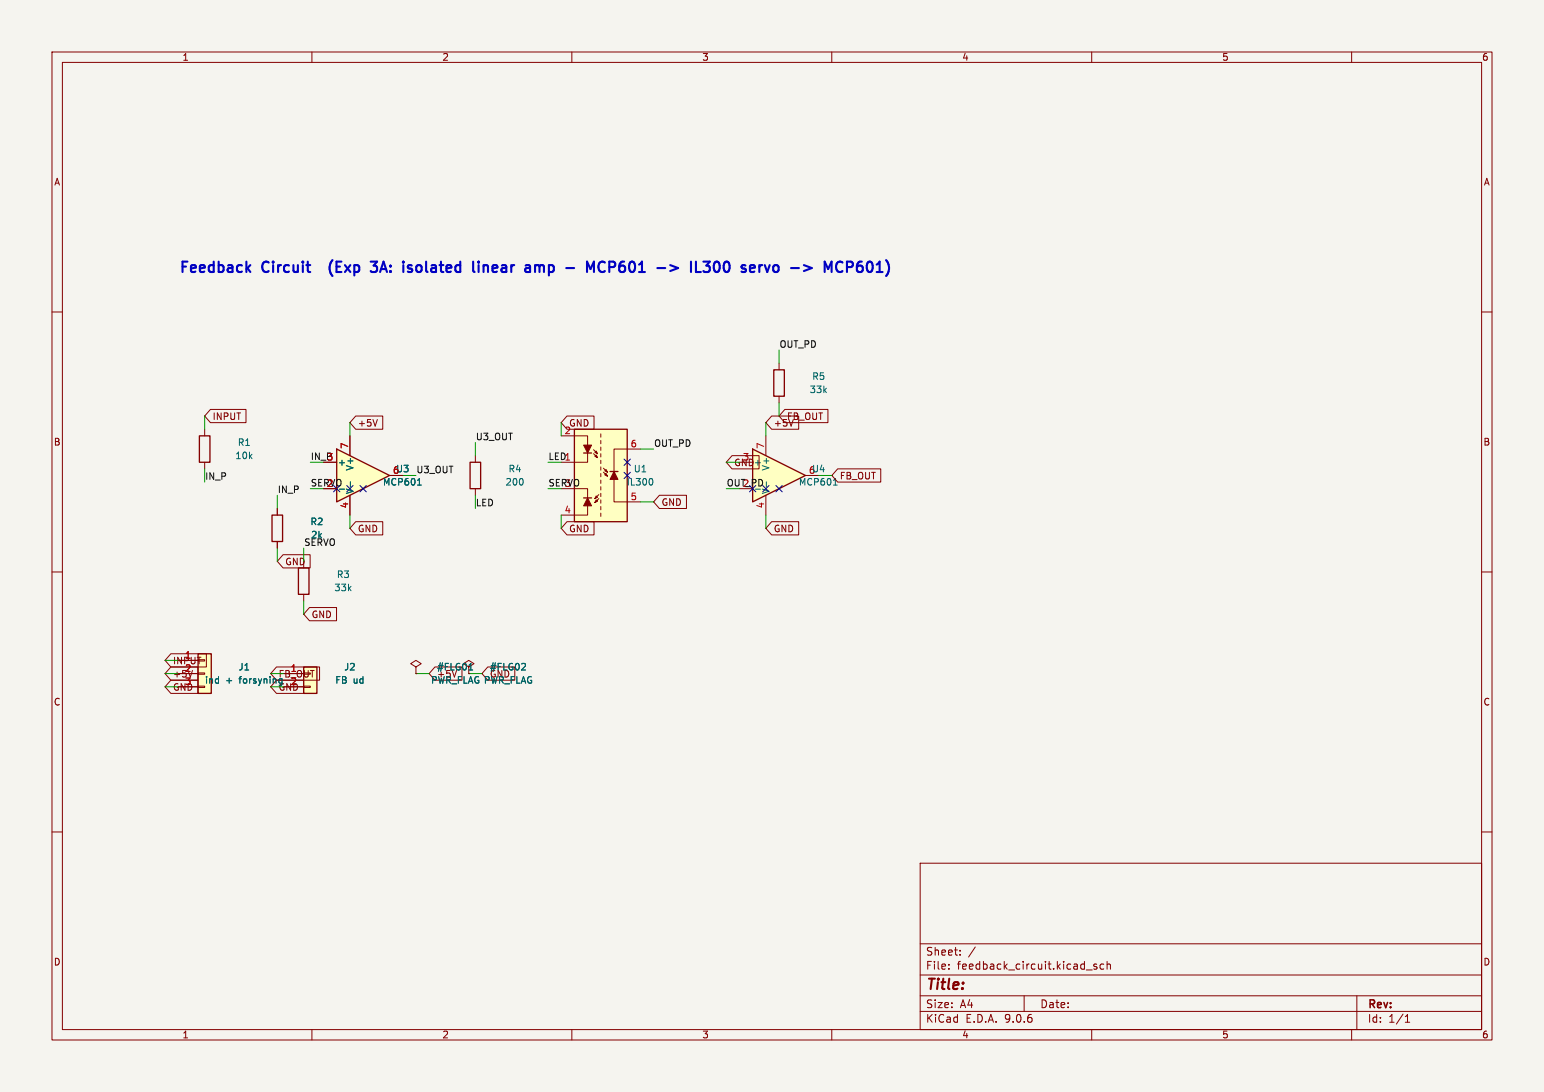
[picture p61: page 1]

Id: 1/1 Title: File: feedback_circuit.kicad_sch Sheet: /

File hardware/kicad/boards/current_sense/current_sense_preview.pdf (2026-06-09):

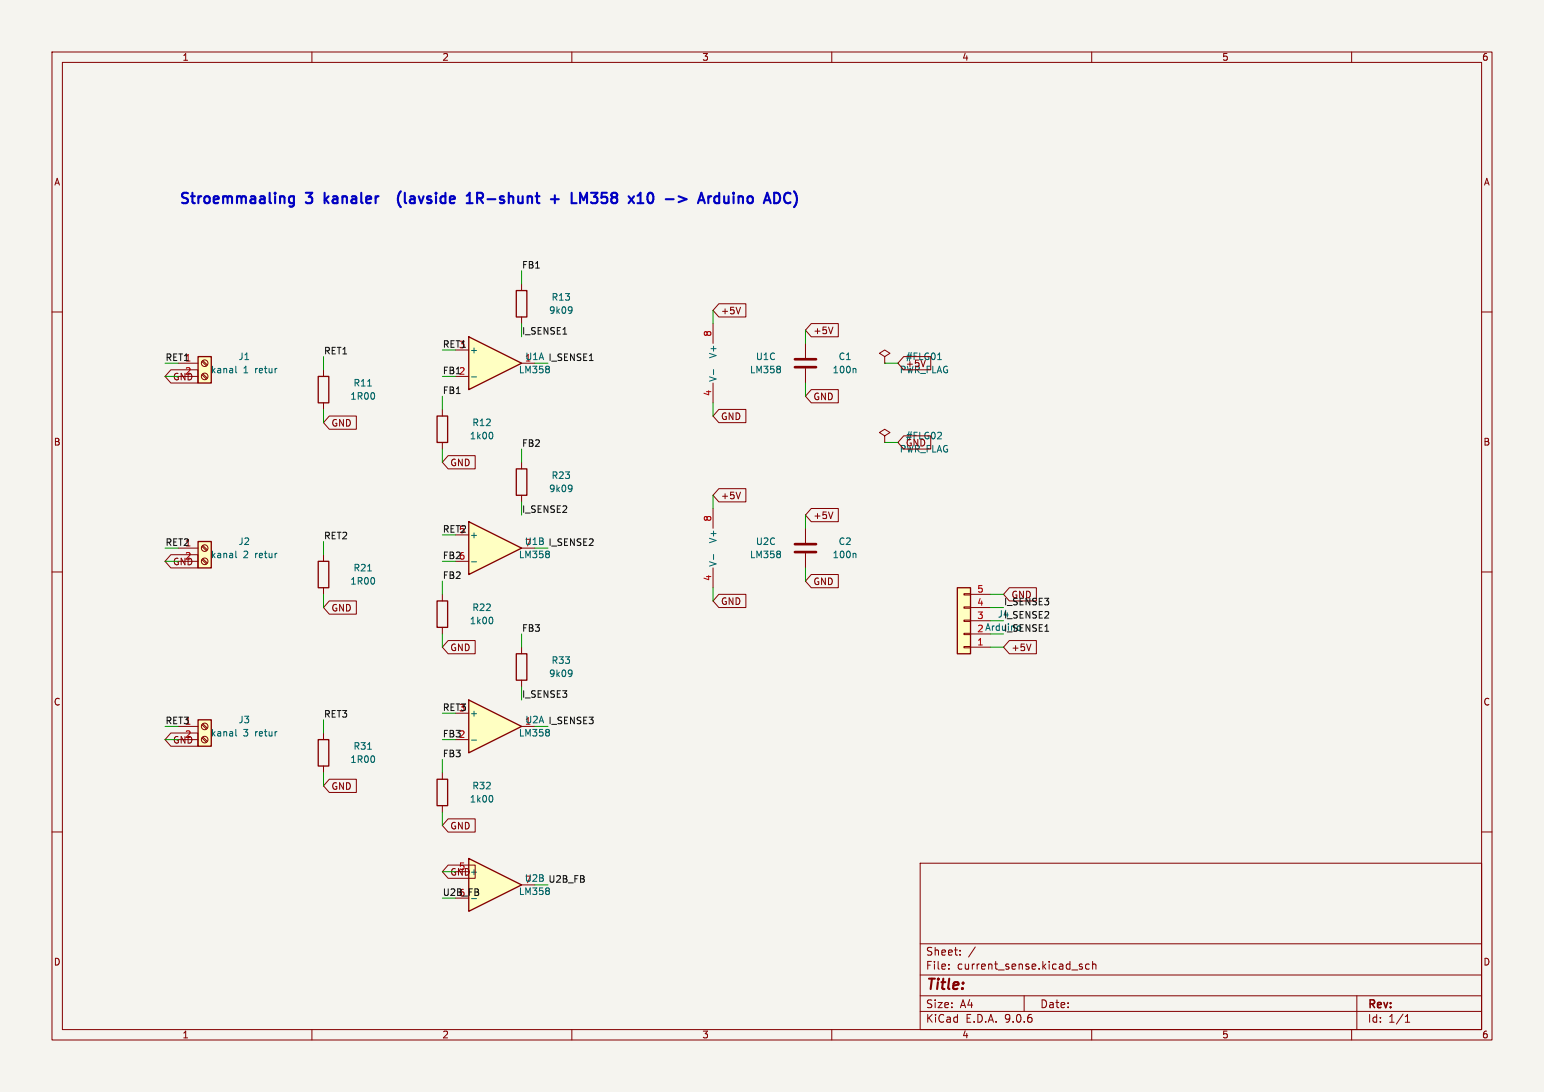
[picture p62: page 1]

Id: 1/1 Title: File: current_sense.kicad_sch Sheet: / V+

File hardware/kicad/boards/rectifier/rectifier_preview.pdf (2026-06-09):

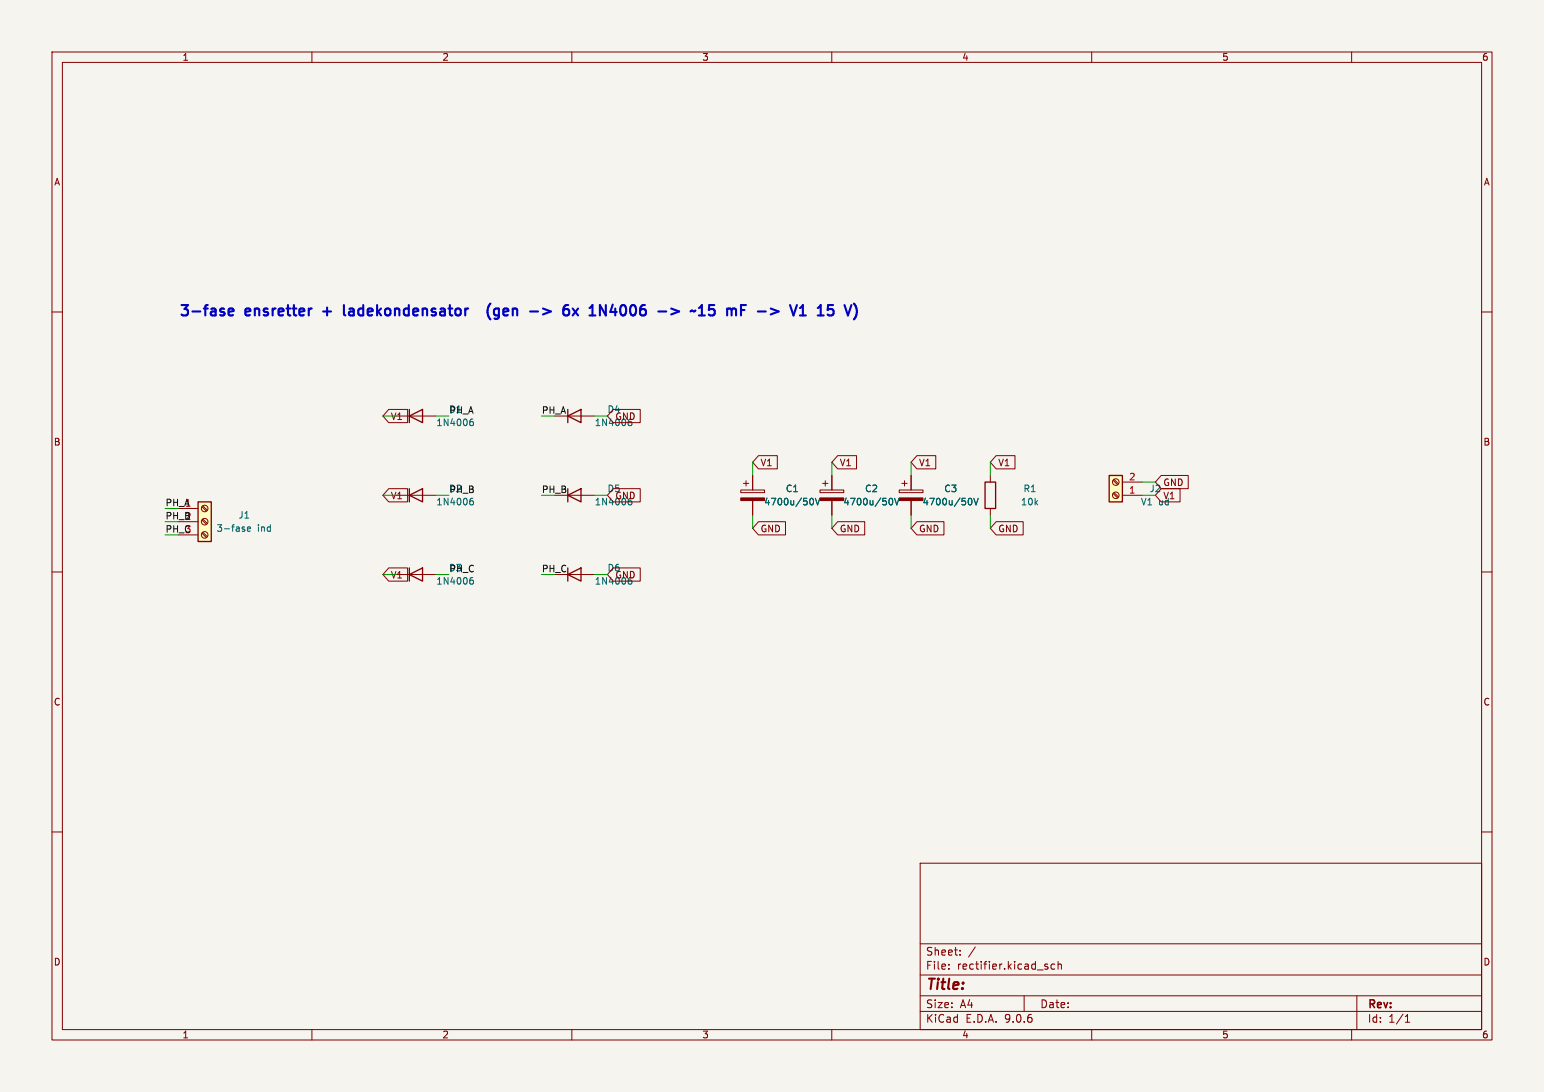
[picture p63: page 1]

Id: 1/1 Title: File: rectifier.kicad_sch Sheet: /

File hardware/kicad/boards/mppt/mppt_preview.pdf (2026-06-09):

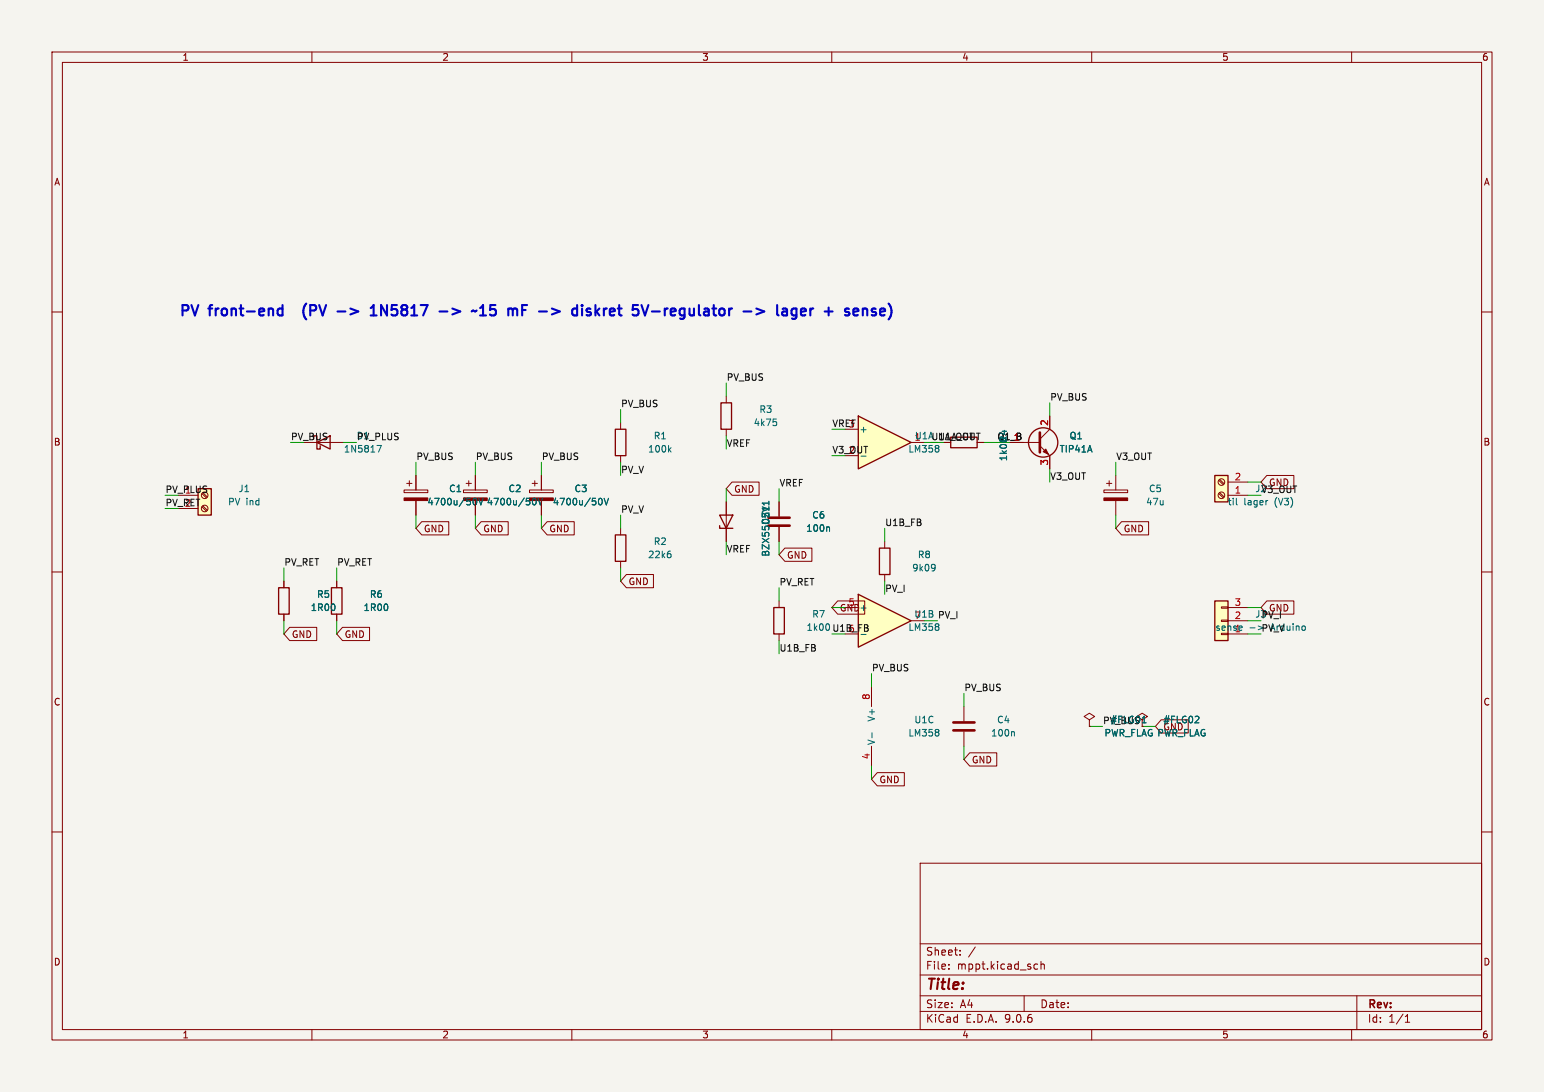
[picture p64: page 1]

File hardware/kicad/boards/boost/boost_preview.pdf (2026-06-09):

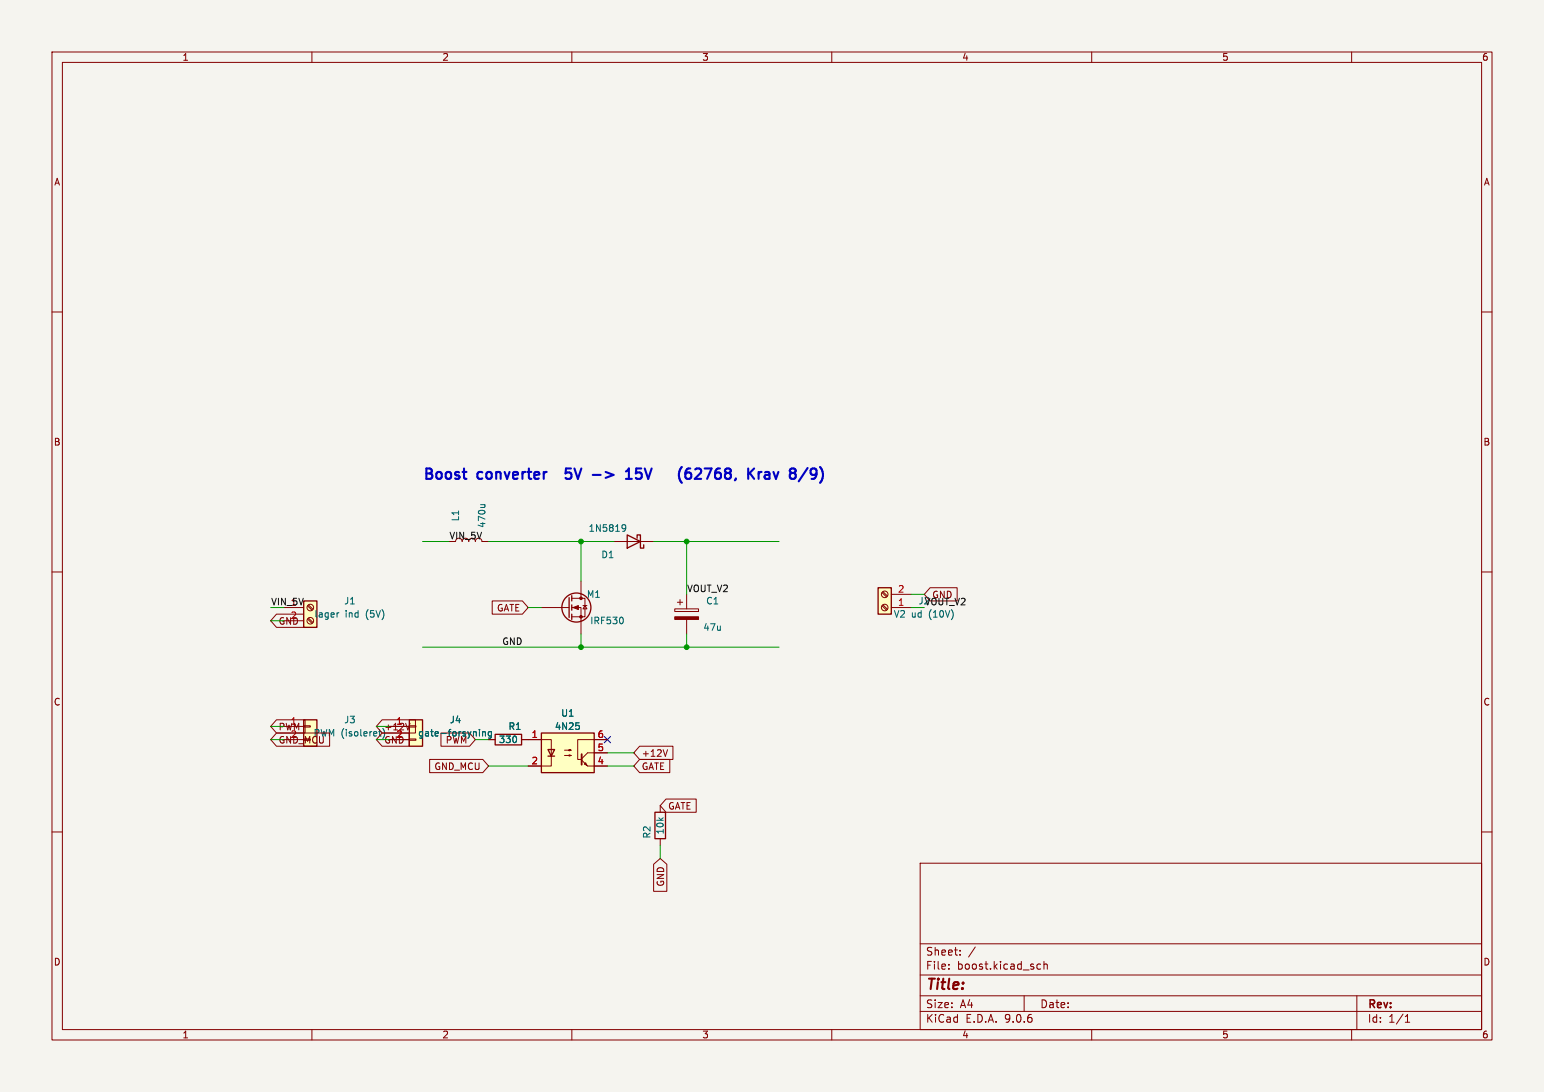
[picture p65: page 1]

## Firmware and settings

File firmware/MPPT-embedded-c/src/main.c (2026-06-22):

#define F_CPU 16000000UL

#include <avr/io.h>
#include <util/delay.h>
#include <avr/interrupt.h>
#include <stdio.h>

#include "ina219.h"
#include "twi.h"

/*
=============================================================
                  HARDWARE CONNECTIONS
=============================================================

MCU: ATmega328P (Arduino Nano, 16 MHz)

-------------------- I2C (INA219) --------------------
INA219 VCC   -> 5V
INA219 GND   -> GND
INA219 SDA   -> PC4 (Arduino A4)
INA219 SCL   -> PC5 (Arduino A5)

NOTE:
- SDA and SCL MUST have pull-up resistors (~4.7kΩ) to 5V

-------------------- PWM OUTPUT ----------------------
PD6 (OC0A)   -> PWM output signal
               -> connected to gate driver / converter control

PWM SETTINGS:
- Timer0 Fast PWM
- Non-inverting mode
- Prescaler = 8
- Approx. PWM frequency ≈ 7.8 kHz

-------------------- POWER MEASUREMENT ----------------
INA219 measures:
- Bus voltage (V)
- Current (I)

Power is calculated in software:
    P = V * I

-------------------- SYSTEM FUNCTION ------------------
1. MCU reads V(k) and I(k) via INA219 (I2C)
2. Computes power: P(k)
3. Calculates:
       ΔP = P(k) - P(k-1)
       ΔV = V(k) - V(k-1)
4. Applies Perturb & Observe (MPPT algorithm)
5. Adjusts PWM duty cycle to track max power point

=============================================================
*/

// ===================== ADDED: UART / Serial output =====================
#define BAUD 9600UL
#define UBRR_VALUE ((F_CPU / (16UL * BAUD)) - 1)

static void UART_init(void)
{
    UBRR0H = (uint8_t)(UBRR_VALUE >> 8);
    UBRR0L = (uint8_t)(UBRR_VALUE);

    UCSR0B = (1 << TXEN0);                          // Enable transmitter
    UCSR0C = (1 << UCSZ01) | (1 << UCSZ00);         // 8 data bits, 1 stop bit, no parity
}

static void UART_tx(char c)
{
    while (!(UCSR0A & (1 << UDRE0))) {
        ; // wait
    }
    UDR0 = c;
}

static int UART_putchar(char c, FILE *stream)
{
    if (c == '\n') {
        UART_tx('\r');
    }
    UART_tx(c);
    return 0;
}

static FILE uart_stdout = FDEV_SETUP_STREAM(UART_putchar, NULL, _FDEV_SETUP_WRITE);
// ======================================================================

volatile float V_old = 0.0f;
volatile float V_new = 0.0f;

volatile float I_new = 0.0f;
volatile float I_old = 0.0f;

volatile float P_new = 0.0f;
volatile float P_old = 0.0f;

volatile int16_t duty = 128; // Initial PWM value (50% duty cycle)

// ///////////////////////// Initialize Timer /////////////////////////
void Timer_init(void) { // Page 84 in datasheet
    DDRD |= (1 << PD6); // Set PD6 as output for PWM signal
    TCCR0A |= (1 << COM0A1) | (1 << WGM01) | (1 << WGM00); // Fast PWM mode with 0xFF as top
    TCCR0B |= (1 << CS01) | (1 << CS00); // Prescaler of 64

    OCR0A = duty; // Set compare match value for PWM
}

// ///////////////////////// Initialize ADC /////////////////////////
void ADC_init(void) { // Page 217 in datasheet
    ADMUX = (1 << REFS0); // AVcc reference voltage, ADC0 as input

    ADCSRA |= (1 << ADEN) // Enable ADC
           | (1 << ADIE)  // Enable ADC interrupt
           | (1 << ADPS2) | (1 << ADPS1) | (1 << ADPS0); // prescaler of 128

    sei(); // enable global interrupts
}

// ///////////////////////// Start ADC Conversion /////////////////////////
void ADC_start(void) {
    ADCSRA |= (1 << ADSC); // Enable ADC
}

int main(void)
{
    // ===================== ADDED: UART init for printing =====================
    UART_init();
    stdout = &uart_stdout;
    // ========================================================================

    TWI_init();   // Initialize TWI for INA219 communication
    INA219_init(); // Initialize INA219 sensor
    ADC_init();   // Initialize ADC
    Timer_init();  // Initialize Timer for PWM

    while (1) {
        V_old = V_new;
        V_new = INA219_getVoltage();

        I_old = I_new;
        I_new = INA219_getCurrent();

        P_old = P_new;
        P_new = V_new * I_new;

        // ===================== ADDED: Serial print =====================
        char vStr[12];
        char iStr[12];
        char pStr[12];

        dtostrf(V_new, 6, 3, vStr);
        dtostrf(I_new * 1000.0f, 7, 1, iStr); // amps -> mA (LSB = 0.1 mA, 10x the resolution of "A")
        dtostrf(P_new, 6, 3, pStr);

        printf("Voltage: %s V | Current: %s mA | Power: %s W\n", vStr, iStr, pStr);
        // ===============================================================

        float deltaP = P_new - P_old;
        float deltaV = V_new - V_old;

        if (deltaP > 0) {
            if (deltaV > 0) duty++;
            else duty--;
        } else {
            if (deltaV > 0) duty--;
            else duty++;
        }

        if (duty > 255) duty = 255;
        if (duty < 0) duty = 0;


        OCR0A = duty;
        _delay_ms(100);
    }
}

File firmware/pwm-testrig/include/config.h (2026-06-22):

#ifndef CONFIG_H
#define CONFIG_H

/*
 * config.h - Pins og parametre for PWM-testriggen
 *
 * Arduino Nano (ATmega328P @ 16 MHz). PWM ud paa D9 (OC1A/Timer1),
 * to potmetre paa A0/A1, SSD1306 OLED paa I2C (A4/A5).
 */

/* ============ DEFINITIONER ============ */

// PWM-udgang: D9 = PB1 = OC1A (Timer1, 16-bit -> fin oploesning)
#define PWM_PIN             PB1     // Arduino D9
#define PWM_DDR             DDRB
#define PWM_PORT            PORTB

// Potmetre (ADC-kanaler)
#define POT_DUTY_CHANNEL    0       // Arduino A0: duty cycle 0-100 %
#define POT_FREQ_CHANNEL    1       // Arduino A1: frekvens

// Frekvensomraade - pseudo-logaritmisk i tre dekade-segmenter,
// saa der baade er fin oploesning ved 100 Hz og raekkevidde til 50 kHz
#define FREQ_MIN_HZ         100UL
#define FREQ_SEG1_HZ        1000UL      // pot 1/3:  100 Hz -> 1 kHz
#define FREQ_SEG2_HZ        10000UL     // pot 2/3:  1 kHz -> 10 kHz
#define FREQ_MAX_HZ         50000UL     // pot 3/3:  10 kHz -> 50 kHz

// Potmeter-hysterese: ignorer aendringer mindre end dette (ADC-counts),
// ellers flimrer display/PWM af stoej paa skyderen
#define POT_DEADBAND        3

// SSD1306: de fleste moduler svarer paa 0x3C - proev 0x3D hvis displayet er dødt
#define SSD1306_ADDR        0x3C

// Display-opdatering (ms mellem hver gennemloeb af main-loop)
#define LOOP_PERIOD_MS      100

// Fejlfinding: saet til 1 for at vise RAA ADC-counts (A0/A1) i stedet for
// den normale visning. Drej hvert potmeter og se hvilken linje reagerer.
// Saet tilbage til 0 naar potmeter-ledningerne er verificeret.
#define DIAG_RAW_ADC        1

#endif /* CONFIG_H */

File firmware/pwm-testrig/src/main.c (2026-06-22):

/*
 * main.c - PWM-testrig paa Arduino Nano
 *
 * To potmetre styrer PWM-udgangen paa D9:
 *   A0: duty cycle 0-100 %
 *   A1: frekvens 100 Hz - 50 kHz (pseudo-logaritmisk)
 *
 * Den faktiske (timer-kvantiserede) frekvens og duty vises paa en
 * SSD1306 OLED. Riggen er taenkt som stimulus/maaleobjekt sammen
 * med AD3'en naar konverter-gatedrev mv. skal testes.
 *
 * Afhaengigheder: adc.h, pwm.h, i2c.h, ssd1306.h, config.h
 */

/* ============ INCLUDES ============ */
#include <avr/io.h>
#include <stdint.h>
#include <stdio.h>
#include <util/delay.h>

#include "adc.h"
#include "config.h"
#include "i2c.h"
#include "pwm.h"
#include "ssd1306.h"

/* ============ PRIVATE FUNKTIONER ============ */

// Potmeter (0-1023) -> frekvens i Hz. Tre lineaere segmenter pr.
// dekade giver baade fin oploesning i bunden og raekkevidde i toppen:
//   [0..341]    -> 100 Hz  .. 1 kHz
//   [342..682]  -> 1 kHz   .. 10 kHz
//   [683..1023] -> 10 kHz  .. 50 kHz
static uint32_t map_potTilFrekvens(uint16_t pot) {
    if (pot <= 341) {
        return FREQ_MIN_HZ + ((FREQ_SEG1_HZ - FREQ_MIN_HZ) * (uint32_t)pot) / 341UL;
    }
    if (pot <= 682) {
        return FREQ_SEG1_HZ + ((FREQ_SEG2_HZ - FREQ_SEG1_HZ) * (uint32_t)(pot - 342)) / 340UL;
    }
    return FREQ_SEG2_HZ + ((FREQ_MAX_HZ - FREQ_SEG2_HZ) * (uint32_t)(pot - 683)) / 340UL;
}

// Opdater kun ved reel drejning - undgaa display/PWM-flimmer fra ADC-stoej
static uint8_t pot_harAendretSig(uint16_t ny, uint16_t gammel) {
    int16_t diff = (int16_t)ny - (int16_t)gammel;
    if (diff < 0) diff = -diff;
    return diff > POT_DEADBAND;
}

static void display_visStatisk(void) {
    ssd1306_print(0, 16, "PWM TESTRIG (D9)");
    ssd1306_print2x(2, 0, "f");
    ssd1306_print2x(5, 0, "D");
}

static void display_visVaerdier(uint32_t freq_hz, uint8_t duty_pct) {
    char buf[12];

    // Frekvens: hoejrestillet, heltal Hz (op til 5 cifre)
    snprintf(buf, sizeof(buf), "%5lu", (unsigned long)freq_hz);
    ssd1306_print2x(2, 18, buf);
    ssd1306_print(3, 102, "Hz");

    // Duty i procent
    snprintf(buf, sizeof(buf), "%3u", duty_pct);
    ssd1306_print2x(5, 18, buf);
    ssd1306_print(6, 66, "%");
}

/* ============ MAIN ============ */
int main(void) {
    adc_init();
    pwm_init();
    i2c_init();

    // Display er valgfrit: timeout i I2C-laget goer at riggen koerer
    // videre med PWM alene hvis modulet mangler/er forkert forbundet
    uint8_t display_ok = (ssd1306_init() == I2C_OK);

#if DIAG_RAW_ADC
    // Fejlfindings-tilstand: vis raa ADC-counts (0-1023) for begge kanaler.
    // Drej duty-potmeteret -> kun A0 skal aendre sig; drej frekvens -> kun A1.
    // Reagerer A0 ikke (eller foelger A1), er duty-wiren ikke forbundet til A0.
    ssd1306_clear();
    ssd1306_print(0, 0, "DIAG raa ADC counts");
    while (1) {
        char b[12];
        snprintf(b, sizeof(b), "A0:%4u", adc_readAveraged(POT_DUTY_CHANNEL));
        ssd1306_print2x(2, 6, b);
        snprintf(b, sizeof(b), "A1:%4u", adc_readAveraged(POT_FREQ_CHANNEL));
        ssd1306_print2x(5, 6, b);
        _delay_ms(120);
    }
#endif

    if (display_ok) display_visStatisk();

    uint16_t pot_duty = adc_readAveraged(POT_DUTY_CHANNEL);
    uint16_t pot_freq = adc_readAveraged(POT_FREQ_CHANNEL);
    uint32_t freq_faktisk = pwm_set(map_potTilFrekvens(pot_freq), pot_duty);
    uint8_t foerste_visning = 1;

    while (1) {
        uint16_t ny_duty = adc_readAveraged(POT_DUTY_CHANNEL);
        uint16_t ny_freq = adc_readAveraged(POT_FREQ_CHANNEL);

        uint8_t aendret = 0;
        if (pot_harAendretSig(ny_duty, pot_duty)) { pot_duty = ny_duty; aendret = 1; }
        if (pot_harAendretSig(ny_freq, pot_freq)) { pot_freq = ny_freq; aendret = 1; }

        if (aendret || foerste_visning) {
            freq_faktisk = pwm_set(map_potTilFrekvens(pot_freq), pot_duty);

            if (display_ok) {
                // Afrundet procent af 1023 til visning
                uint8_t pct = (uint8_t)(((uint32_t)pot_duty * 100UL + 511UL) / 1023UL);
                display_visVaerdier(freq_faktisk, pct);
            }
            foerste_visning = 0;
        }

        _delay_ms(LOOP_PERIOD_MS);
    }
}

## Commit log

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2026-06-07 Firmware: convert to bare-metal C (main.c, pid.c, sensors.c)
    Drop the Arduino framework; register-level ADC/Timer1/Timer2/UART in C.
    Per-chip motor PWM on Timer2 OC2B (Uno D3 / Mega D9). PID stays pure C,
    ready to be replaced by Simulink/Embedded Coder output. Builds clean
    (no warnings) for uno and mega.
    [config.h, main.c, main.cpp]
2026-06-07 Firmware: reset to empty skeletons for the team to write
    Strip implementation from main.c/pid.c/sensors.c + headers, leaving Danish
    file headers + section markers ready to fill in. platformio.ini (uno+mega)
    and README kept.
    [config.h, main.c]
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2026-06-09 Fix converter ripple formulas and correct lecture mapping
    - load_parameters.m: align buck/boost/buck-boost ripple to Lec 2 (Erickson)
    amplitude convention (the missing factor of 2: 2fL / 16 / 2fC)
    - project-overview.md: verified lecture map against the slide PDFs
    (Lec 2 = buck/boost, Lec 3 = PMSM, Lec 4 = rectifiers, Lec 5 = choppers;
    motor/PID/MPPT live in the Lec 1 Modeling companion deck)
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2026-06-09 Add KiCad 9 buck & boost converter schematics
    Generated with sexpdata (kicad-skip pattern) since spicepilot-kicad auto-layout
    collapses converter topologies. Real N-MOSFET (IRF540N) + Schottky (1N5819),
    matching the LTspice models. Internal nets ERC-clean; only external-interface
    notes remain (VIN/GATE ports, gate driven by Arduino). Includes generator script
    and rendered PDF figures.
    [boost.kicad_sch, buck.kicad_sch]
2026-06-09 Add isolated optocoupler gate drive to buck & boost converters
    - 4N25 opto isolates Arduino PWM from the power stage (non-inverting)
    - boost (low-side): gate pulldown to GND, +12V supply
    - buck rebuilt in wired style with high-side switch: pulldown to SW,
    floating +12V_SW (gate referenced to the MOSFET source)
    - new helpers: buck_build.py, add_optocoupler.py; README documents the
    drive and the 4N25 drive-strength caveat (needs a BJT buffer at 50 kHz)
    [boost.kicad_sch, buck.kicad_sch]
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2026-06-09 Save working KiCad ngspice sim setups for buck & boost
    - buck_sim: PULSE gate drive (GATE->SW, D=0.333), opto excluded, IRF530N
    model, diode pin order fixed; settles ~4.7 V
    - boost_sim: PULSE gate drive (GATE->GND, D=0.667), 25 ms transient;
    settles ~14.4 V
    - include .wbk workbooks (transient command + plotted signals) for reproducibility
    - both agree with LTspice and hand calc
    [boost_sim.kicad_sch, buck_sim.kicad_sch]
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2026-06-09 Add behavioral sim of Exp 3A feedback amp (IL300 servo)
    PySpice/ngspice behavioral model (generic op-amps + IL300 matched-photodiode
    model). DC sweep confirms a clean isolated linear transfer FB_OUT = INPUT/6
    (15 V -> 2.5 V), with the servo node tracking the input. Sim also surfaced that
    the schematic's LED/op-amp polarity as drawn is positive feedback and latches;
    sim README documents the two fixes. Includes fb_transfer.png + fb_sweep.csv.
    [fb_sweep.csv]
2026-06-09 Fix feedback servo polarity: drive IL300 LED anode-side from U3
    Sim showed the as-drawn LED orientation (anode->+5V, cathode sunk by U3 with
    +in=IN_P) is positive feedback and latches. Flip to anode<-R4<-U3, cathode->GND
    so U3 sources the LED current -> negative feedback. Matches the validated
    behavioral sim (FB_OUT = INPUT/6, linear).
    [feedback_circuit.kicad_sch]
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2026-06-09 Fix dcdc120_cl Run error: define C0 (initial cap voltage) in load_parameters
    The closed-loop model's RLC branches use 'InitialVoltage = C0', but load_parameters
    never set C0 -> 'Error evaluating parameter InitialVoltage' on Run. Add C0 = 0 to
    the common section so dcdc120_cl runs after load_parameters like the other models.
2026-06-09 Add PCB & footprint handoff brief for the hardware phase
    Self-contained brief for a session working the PCB/footprint phase: current
    schematic inventory, the two component sources (shop CSV + course-kit ICs),
    part-substitution flags (IR2110/IL300/ILD74 not in shop), footprint mapping to
    KiCad stock + when to use SnapEDA into energy_system.pretty, the remaining
    schematics to generate (rectifier/MPPT/current-sense), and a realistic
    single-layer PCB plan via pcbnew + Freerouting.
2026-06-09 Save GUI edits to drive circuit + run-state of buck/closed-loop models
    drive_circuit.kicad_sch: in-progress KiCad edits (BUZ11, PWR_FLAGs, 1N4001,
    rewiring). Buck_converter_Lab.slx + dcdc120_cl.slx: current state after running
    them (scope setup, C0 closed-loop fix verified).
    [drive_circuit.kicad_sch]
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2026-06-09 Add system schematics: 3-phase rectifier, PV front-end and current sense
    The three remaining blocks from the spec (krav 1-3, 9-11):
    - rectifier: 6x 1N4006 bridge + 3x 4700u (~15 mF) -> V1
    - mppt: PV -> 1N5817 -> 15 mF cap -> discrete 5V linear reg (LM358 +
    BZX55C5V1 + BD139) -> store, with PV V/I sense outputs for the Arduino
    - current_sense: 3x low-side 1R shunt + LM358 gain 10 -> ADC
    Generated with the same sexpdata pattern as exp3a, but pin coordinates
    are read from the KiCad symbol libs (schbuild.py) instead of hand-coded
    tables. Footprints assigned at generation. ERC: 0 errors on all three.
    [current_sense.kicad_pcb, current_sense.kicad_sch, mppt.kicad_pcb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]
2026-06-09 Fix drive circuit wiring and make all four schematics PCB-ready
    Two bugs from the GUI editing session fixed in drive_circuit:
    - D1 (freewheel) had both pins on +20V (motor+ IS the +20V rail), so the
    motor had no flyback path at all. Anode moved to the switch node.
    - The IR2110 HIN/SD/VSS/VS island was tied together but never reached
    GND - floating logic reference and undefined shutdown. Now grounded.
    PCB-readiness for all four:
    - buck/boost: removed the simulation-only V_in (SPICE VDC) and Rload,
    added screw terminals for power in/out plus headers for PWM (isolated
    GND_MCU) and the gate-drive rail. NOTE: buck's +12V_SW is referenced
    to the SW node (high-side switch -> floating sup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
    [boost.kicad_sch, buck.kicad_sch, drive_circuit.kicad_sch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]
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2026-06-09 Apply fiber-laser design rules from the DTU-PCB-prototyping guide
    All seven boards rebuilt to meet the XTool fiber laser workflow
    (SimsesLab/DTU-PCB-prototyping): 1.0 mm tracks, 0.8 mm clearance, solid
    no-net fill zone on B.Cu (pad connection: none) so the laser only
    engraves the isolation channels, DIP footprints switched to the
    _LongPads variants from the guide's shop table.
    TO packages cannot meet 0.8 mm pad-to-pad at stock sizes, so
    energy_system.pretty now has TO-220-3_Vertical_LaserPads (pads narrowed
    to 1.7 mm -> 0.84 mm gap; make_laserpads.py regenerates). The MPPT pass
    transistor moves BD139 -> TIP41A (shop part): TO-126's 2.28 mm pitch can
    never satisfy the rule, and TO-220 handle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
    [boost.kicad_pcb, boost.kicad_sch, buck.kicad_pcb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]
2026-06-09 Add production exports for the fiber laser: DXF + gerbers per board
    production/<board>/<board>.dxf is the file to import in xTool Creative
    Space (B.Cu + Edge.Cuts single file, drill marks small, mm - the guide's
    plot settings). gerbers/ holds the standard fabrication set + Excellon
    drill as documentation/fallback.
    production/README.md is the run plan: cut sizes (+2 mm), per-board
    jumper lists, and the step-by-step xTool checklist (flip/mirror, make
    compound, delete holes to engrave them, PCB preset). PCB_RESULTS.md
    updated to point there. Regenerate with pcb_export_production.ps1.
    [boost.dxf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]
2026-06-09 Engrave component references into the copper on all boards
    The fiber laser has no silkscreen step, so the refdes (R1, U1, ...) are
    placed as mirrored copper text on B.Cu next to each component - they
    engrave in the same run as the traces and read correctly from the
    solder side. Placement is collision-checked against tracks/pads/other
    text (copper text over a track would short or sever it); tracks are
    sampled into small boxes so diagonal runs don't false-positive. 86 of
    96 labels fit; the handful dropped in dense spots are listed in
    production/README.md and still appear on the F_Fab plots.
    Also exports <board>_silk_top.dxf (F.Silkscreen + outline) per board as
    an optional top-side engraving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
    [boost.dxf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]
2026-06-10 Link each PCB to its schematic as a proper KiCad project
    The boards lived in pcb/ subfolders, so opening a schematic gave no
    linked PCB editor. Each board file now sits next to its schematic with
    the same basename plus a generated .kicad_pro - open the project file
    and the schematic/PCB editors cross-link as normal. The project file
    carries the fiber-laser netclass (0.8 mm clearance / 1.0 mm tracks) so
    GUI routing keeps the production rules; verified DRC still reports the
    0.8 mm rule and 0 violations on all seven boards after the move.
    When running Update PCB from Schematic the first time, tick 're-link
    footprints by reference designator' (script-built boards have no
    symbol UUID links). pcb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
    [boost.kicad_pcb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]
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2026-06-10 Hand-place mppt and current_sense following the signal flow
    The auto-grid placement scattered the per-channel parts and starved the
    single-layer router: current_sense had 15 airwires (a third of the
    board hand-wired) and mppt 10. pcb_build.py now takes an explicit
    placement table for these two - channels run left to right (terminal ->
    shunt -> gain pair -> op-amp -> header), PV chain likewise - and the
    boards shrank in the process (mppt 165x82 -> 140x68, current_sense
    134x58 -> 120x80).
    Jumpers now: mppt 7, current_sense 10, both DRC-clean (one cosmetic
    silk-over-mask warning on mppt; silk isn't part of the laser flow).
    Also fixed in this pass: shunt pair R5/R6 flipped so same-net pads
    face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
    [boost-B_Cu.gbl, boost-B_Mask.gbs, boost-Edge_Cuts.gm1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]
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2026-06-10 Move engraved component names to the top side (F.Cu)
    The refdes copper text now sits on the component side next to each
    part, not mirrored - it rides in <board>_top_cu.dxf, so it gets etched
    into the top copper on a double-sided build, or engraved onto the top
    surface together with the wire-bridge plan on a single-sided build.
    Migration done textually with sexpdata (migrate_refdes_topside.py):
    ZONE.Remove() via the pcbnew API crashes KiCad 9.0.6's python with an
    access violation and corrupts SWIG iteration, so in-process zone
    surgery is off the table - zones are refilled in a clean session
    (refill_zones.py) instead. Texts that landed on top-layer tracks after
    the move (one was shorting boos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
    [boost-B_Cu.gbl, boost-B_Mask.gbs, boost-Edge_Cuts.gm1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]
2026-06-10 Fit the measured 470uH toroid on buck/boost and fix the routing pipeline
    L1 was placeholder Fastron 07P (D10/P5) - the wound toroid measures OD 34.5mm
    standing on edge, legs 28.2mm c-c at 1.6mm dia. New footprint
    energy_system:L_Toroid_Vertical_L34.5mm_W15.0mm_P28.20mm_LaserPads
    (2.0mm drills, 4.0mm pads), boards regrown to 145x72 and rerouted
    (buck 4 top tracks / boost only 2 now). Production DXF/gerbers re-exported.
    Routing pipeline fixes that this flushed out:
    - Set-Content -Encoding UTF8 under Windows PowerShell 5.1 writes a BOM and
    Freerouting's DSN parser chokes on it (bogus "file not found"). The stage-1
    mask now writes via [IO.File]::WriteAllText (BOM-less).
    - Freerouting 2.0.1'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
    [boost-B_Cu.gbl, boost-B_Mask.gbs, boost-Edge_Cuts.gm1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]
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2026-06-10 Move all boards to the 104x104 jig format with compact placement
    The laser positioning jig takes an exactly 109x109 mm copper blank, so every
    board now has identical 104x104 edge cuts (2.5 mm rim). pcb_build.py:
    - fixed JIG_W/JIG_H outline, hard failure if content overflows the square
    - compact packing: 5 mm bbox gaps (was 8), squarish component cluster below
    the connector zone instead of full-width rows
    - mppt/current_sense PLACE layouts re-arranged for the square and tightened
    All 7 boards rerouted: 0 unconnected, 0 real DRC errors, and no vias needed
    anywhere (the square format routes better than the old elongated boards).
    Production DXF/gerbers re-exported; README run-plan updated for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
    [boost-B_Cu.gbl, boost-B_Mask.gbs, boost-Edge_Cuts.gm1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]
2026-06-10 Fix refdes copper-text collisions after manual drive_circuit reroute
    [drive_circuit-B_Cu.gbl, drive_circuit-B_Mask.gbs, drive_circuit-Edge_Cuts.gm1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]
2026-06-11 Condense and center all boards in the jig outline; reroute drive_circuit
    Placement (pcb_build.py): connector columns now hug the component block
    instead of sitting at the board edges, and the whole cluster is translated to
    the center of the 104x104 outline - nothing sits next to the edge cuts
    anymore. Fail-hard check if a cluster outgrows the jig.
    drive_circuit keeps the hand-made GUI placement but is rerouted with the
    two-stage flow: 43 top tracks + 1 via from the GUI autoroute down to 20
    pin-to-pin bridges, no via. New tools/strip_routing.py removes existing
    routing textually (sexpdata) - in-process pcbnew Remove() access-violates.
    All 7 boards: 0 unconnected, 0 real DRC errors, no vias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
    [boost-B_Cu.gbl, boost-B_Mask.gbs, boost-Edge_Cuts.gm1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]
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2026-06-11 Fix buck_v2 gate drive, regulator ground and output cap
    Four wiring bugs from review of the new schematic:
    - LF50 GND/C1/C2 formed a floating island - regulator had no return, the
    5V rail was undefined. Tied to GND.
    - High-side gate drive could not work: opto collector sat on the GND-
    referenced 9V rail and R5 pulled the gate to GND, so V_GS goes negative
    the moment Q1 turns on (drain bus is 15V). The 9V battery now FLOATS on
    the SW node (J2- = SW, J2+ = opto collector, R5 gate->source) like the
    J4 arrangement on buck v1. The LF50/555 control side is fed from the
    Rectifier (V1) rail instead, with C1 as its input cap.
    - C5 output cap 100n -> 47u (100n gives volts of ripple at thes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
    [buck_v2.kicad_sch]
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2026-06-17 Boost v2 med IR2110 gate-driver + boost test-resultater
    - boost_v2: integreret IR2110 gate-drive (opto -> IR2110 -> low-side MOSFET),
    generator (build_boost_v2.py), schematic, board og laser/gerber-filer
    - buck_v2: patchet til IR2110 high-side drive (patch_buck_v2_ir2110.py)
    - boost: opdateret board, gamle produktions-DXF erstattet af boost_v2
    - AD3 boost-bringup script (tools/ad3/boost_test.py)
    - BOM opdateret med IR2110/CNY17; CNY17- og IRF530-datablade
    - rapport: boost maaleresultater (10 kHz, 40%) med figur
    - HANDOFF-dokument for buck/boost IR2110-redesign; PCB_RESULTS opdateret
    [boost.dxf, boost.kicad_pcb, boost_silk_top.dxf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]
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2026-06-21 motor_power: re-route with 0 vias (single-sided clean)
    Bypass caps placed adjacent to their ICs (C1/C2 by the 555) so the 555-CONT net
    no longer needs an inter-layer link. Fully routed: 0 vias, 0 unconnected pads.
    [motor_power.kicad_pcb, motor_power.place.json]
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2026-06-22 Refdes on silkscreen, never on top copper
    Component reference designators now go on F.SilkS (top silkscreen) instead of
    being etched as copper text on F.Cu. Footprint default refs are hidden so there's
    one clean label per part; placement only avoids pads (silk-over-copper is fine),
    so nothing drops. Also fixes the finish step's zone-removal to materialize lists
    before Remove() (KiCad-10 SWIG iterators invalidate on mutation). motor_power +
    motor_feedback re-finished to silk.
    [motor_feedback.kicad_pcb, motor_power.kicad_pcb]
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2026-06-22 boost_v2_mill: CNC-millable rebuild of boost_v2 for the 0.8 mm endmill
    Wider-clearance variant for the SRM-20 mill. Placement scaled ~1.4x onto a
    116x97 mm board (the mill has no 104x104 jig) and re-routed; clearance rule
    set to 0.8 mm (the endmill diameter), all copper gaps >= 0.8 mm so the bit can
    isolate them - the original 0.8 mm-clearance laser board had 43 un-millable
    gaps with this bit. Fully routed, DRC clean. Includes B.Cu/Edge gerbers +
    PTH/NPTH drill. Original boost_v2 laser board + its gerbers untouched.
    Bumps srm-cam: SRM-20 0.8 mm preset drills to 2.3 mm for clean breakthrough.
    [boost_v2_mill.kicad_pcb, boost_v2_mill.kicad_sch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]
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2026-06-22 boost_v2_mill: F.Silkscreen DXF for xTool top-side engraving
    Top silkscreen (refdes, component outlines, polarity marks) plus the
    Edge.Cuts outline as a registration reference, exported NOT mirrored so it
    engraves correctly on the component side from above. mm units, no drill
    marks.
    [boost_v2_mill_silk_top.dxf]
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2026-06-23 drive_circuit: route board + CNC production files for the SRM-20
    Routed single-sided for milling. Exported the mill production set: B.Cu +
    Edge.Cuts gerbers and split PTH/NPTH drill, plus the traces/drill/cutout
    toolpaths in both .nc (G-code) and .rml. Dropped the laser-only F.Cu /
    mask / silk gerbers and the combined drill the mill doesn't use.
    [drive_circuit-B_Cu.gbl, drive_circuit-B_Mask.gbs, drive_circuit-Edge_Cuts.gm1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]
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2026-06-27 system PCB: lock double-sided CNC integration (Phase 0-2.2)
    Set up the whole-system board as one double-sided CNC-milled PCB.
    - system.kicad_pro: CNC double-sided netclass (clearance 1.0 mm, track 1.0 mm,
    hand-stitch via 2.4/1.0 mm) replacing the laser 0.8 mm rules
    - interface contract (docs/superpowers/specs/2026-06-27-...) + rewritten
    label howto for the 5-board split-MCU integration
    - split MCU: Arduino owns MPPT (PV INA219 + drives mppt_buck PWM at 5 V),
    C2000 runs motor-buck + boost PID; the two MCUs are fully independent
    - current_sense (discrete) dropped; current sensing via PV INA219
    - c2000_feedback: strip I-channels + PWM pass, keep 3 V-dividers
    (V1/LOAD/STORE -> ADC)
    - hi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
    [boost_v2_mill.kicad_sch, c2000_feedback.kicad_sch, motor_feedback.kicad_sch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]
2026-06-27 system: connected top sheet for the integrated PCB
    Rebuild system.kicad_sch as the netlist-connected 5-board hierarchy
    (motor_power, motor_feedback, mppt_buck, boost_v2_mill, c2000_feedback),
    replacing the old block-diagram. Connectivity by global labels.
    - J_ARD (Arduino), J_C2K (C2000), J_INA (PV INA219) connectors
    - external screw terminals: 3-phase, motor, PV, store, load, +15V, +5V
    - 17 diagnostic probe-point headers on the key nets
    - single GND<->GND_MCU star tie (R_STAR 0R)
    - generator tools/generators/build_system_top.py (reference; the sheet is
    now hand-maintained in the GUI)
    Netlist verified: all 36 top-level connector pins match the interface
    contract, no shorts, STORE/V1/LOAD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
    [boost_v2_mill.kicad_sch, c2000_feedback.kicad_sch, motor_feedback.kicad_sch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]
2026-06-27 system: single edge-connector set + integrated board
    - delete 22 redundant board-level I/O connectors (J201-207, J301-302,
    J401-404, J501-504, J601-605); on the monolithic board these are internal
    board-to-board nets (now copper traces) or duplicates of the top-level edge
    set. Nets carried by the hierarchical sheet pins; netlist re-verified.
    - C212: real capacitor footprint, + on V1 (was a swap terminal)
    - motor_feedback MCU-side powered from +5V_PWR (merged +5V_MCU)
    - footprints assigned to all top-level connectors/probes (J_*, TP, R_STAR)
    - system.kicad_pcb: integrated board pulled via Update-PCB-from-Schematic
    - placement guide (PNG + PDF) + generator/patch scripts
    [boost_v2_mill.kicad_sch, motor_feedback.kicad_sch, motor_power.kicad_sch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]
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2026-06-27 system PCB: repack placement — 0 overlaps, toroids fixed, clusters clear
    [system.kicad_pcb]
2026-06-28 system PCB: routing prep (track 1.0, GND pour both layers) + board/CAM updates
    system board:
    - fix Default netclass track 0.9 -> 1.0 mm (was below min_track_width, every
    trace would have failed DRC); clearance 1.0, via 2.4/1.0 in .kicad_pro + board
    - pour GND on F.Cu and B.Cu (edge inset 0.5 mm, solid pad tie)
    - routing tooling: route_prep (netclass+pour), export_dsn_noplane (route GND as
    tracks; Freerouting 1.9.0 chokes on full-board planes), route_finish (SES
    import + refill + sparse GND stitching), inspect_system
    srm-cam: bump submodule to double-sided support (90 rotation, bottom-side bed
    leveling, GUI ruler/STOP/probe-grid, run-time estimator)
    production: rename boost_v2_mill nc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
    [buck_v2.kicad_pcb, buck_v2.kicad_sch, c2000_feedback.kicad_sch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]
2026-06-28 system PCB: route both layers (Freerouting), DRC-clean, millable
    - 1199 tracks + 67 vias (61 signal from the router + 6 GND stitches); every
    real net routed at 1.0 mm clearance, GND poured both layers
    - custom DRU: pad-to-pad floor 0.8 mm (fixed 2.54 mm THT pitch can't reach the
    1.0 mm routed-copper rule) -> DRC clearance violations 246 -> 0
    - gerber2rml preflight: 0.4 mm bit 0 un-millable gaps; 0.8 mm bit only 2 (0.38 mm2)
    - remaining DRC: 4 silk-over-edge (cosmetic) + 24 netless NC/unused pins (benign)
    - system_routed.pdf: F.Cu/B.Cu/Edge.Cuts for review
    [system.kicad_pcb]
2026-06-28 system PCB: narrow THT pads for 0.8 mm bit + connectivity-aware re-placement
    - narrow_pads.py: clamp the close-neighbour pad dimension to 1.40 mm on dense
    (<=2.54 mm-pitch) parts -> inter-pin gaps 0.84/0.94 -> 1.14 mm. Clears the
    1.0 mm clearance rule outright and gives a 0.8 mm end mill 0.34 mm margin
    (168 pads / 23 parts: DIPs, optos, TO-220s, 2.54 mm headers, DIP switch)
    - place_system2.py: force-directed per-region placement, related parts cluster
    (decoupling by IC, gate parts by MOSFET, divider Rs by op-amp), pulled toward
    each region's fixed connectors/toroids; 0.5 mm grid snap, shelf fallback,
    0 overlaps. Routing must be stripped first (strip_all_routing.py, textual --
    i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
    [system.kicad_pcb]
2026-06-28 system PCB: grid-aligned, justified re-placement (spacious, 0 overlaps)
    Replace the cramped force-directed layout. place_system3.py packs each functional
    block into neat justified rows (even spacing -> routing channels), groups same-type
    parts, lays tall parts (DIPs/TO-220) on their side for short uniform rows, snaps to
    a 1 mm grid. Regions sized ~proportional to part-need; mppt & boost placed SIDE BY
    SIDE in the centre (each full height) so neither overflows. Connectors on the edges.
    [system.kicad_pcb]
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2026-07-03 hardware: label test points by signal name on system board silkscreen
    TP1xx footprints showed their refdes (TP111 etc.) on F.SilkS instead of
    what they actually tap. Reference is now hidden and the Value property
    (already the right name in the schematic, e.g. PWM_MPPT) takes over the
    silk position instead. Re-exported the laser DXF pair from the updated
    layout.
    Adds tools/fix_tp_silk_labels.py (the property swap) and
    tools/dxf_clean_silk.py (kicad-cli DXF -> minimal SILK/OUTLINE geometry
    for the xTool software).
    [MegaPCB_top_silkscreen.dxf, MegaPCB_top_silkscreen_CLEAN.dxf, new_system.kicad_pcb]
2026-07-03 hardware: fix test point labels missing from silkscreen DXF export
    kicad-cli's DXF exporter silently drops the footprint Value FIELD even
    when it's set visible on F.SilkS - confirmed by a controlled test (a
    plain fp_text at the same spot plots fine, the field doesn't). Reference
    designators export fine since they're a different field type, which is
    why every other component's silkscreen showed up on the xTool import but
    the TP1xx signal names didn't.
    Converts the 17 test-point labels from the Value field to plain fp_text
    "user" objects on F.SilkS (keeping the field itself hidden/on F.Fab like
    every other component). Re-exported both DXFs from the corrected board.
    [MegaPCB_top_silkscreen.dxf, MegaPCB_top_silkscreen_CLEAN.dxf, new_system.kicad_pcb]
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
